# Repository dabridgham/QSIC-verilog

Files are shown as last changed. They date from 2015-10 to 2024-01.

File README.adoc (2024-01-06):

= QSIC - QBUS Storage and I/O Card

The QSIC is a QBUS card with an FPGA and SD cards that emulates the old DEC disk
controllers and drives.  A companion
http://github.com/dabridgham/Indicator-Panel[indicator panel] is also
available for those who want the blinkenlights.

This project has been split into separate repositories so that it
works better with git.  This repository primarily holds the Verilog
code that runs on the FPGAs.  It also holds the documentation and the
paper I wrote on bus arbitration.  Finally, just because there's no
more work being done on it, I've left the KiCad schematic for the
wire-wrapped prototype here as well.

So, directories you might care about are:

[horizontal]
board-wirewrap:: KiCad design for the wire-wrap prototype board
documentation:: Programming Manual for the QSIC/USIC
papers:: A paper on QBUS and Unibus arbitration
verilog:: The FPGA code to implement the QSIC

These directories, I'll probably make go away at some point but, for
now, I'll leave them be.

[horizontal]
board-prototype:: KiCad design for a prototype board with 8641 bus
		  transceivers (old idea)
board-qsic:: KiCad design for the QSIC hardware
board-smt:: KiCad design where I've been experimenting with discrete bus drivers
indicator-panel:: This directory is obsolete as the indicator panel has
		  been moved to its own project

Other QSIC-related repositories.

[horizontal]
https://github.com/dabridgham/QSIC[QSIC]:: The QSIC board
https://github.com/dabridgham/USIC[USIC]:: The USIC board
http://github.com/dabridgham/Indicator-Panel[Indicator Panel]:: Indicator Panel PCBs and graphics inlays
Software:: The software that runs on the embedded soft processor in
the QSIC/USIC (not yet started)

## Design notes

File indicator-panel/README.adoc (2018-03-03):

= Indicator Panel

This is an attempt to replicate the functionality of DEC's indicator
panels used on PDP-11s and some other machines.  It was designed in
conjunction with the QSIC project to build a QBUS board to emulate the
old DEC disk drives using more modern storage technology and we wanted
to have blinkenlights to go with.

indicator-panel*::
   KiCad design for the indicator panel boards themselves.  Three
   boards make a full indicator panel.

adapter*:: A small adapter board to convert from the version 1 pinout
   to version 2.

inlay*:: Various inlay designs we've come up with to use with the
   QSIC.

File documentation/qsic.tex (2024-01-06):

% -*- mode: LaTeX; fill-column: 96 -*-
%
% QSIC/USIC Programming and Configuration

\chapter[QBUS/UNIBUS Storage and I/O Card]{QBUS/UNIBUS Storage and Input/Output Card}
\section{Introduction}

The QSIC and USIC are cards which provide emulation of various QBUS and
UNIBUS controllers and disks, using MicroSD cards or (eventually) USB disks
as the actual storage media. They use NOS original bus drivers (DS8641s),
and then level converters to interface to a modern FPGA.

Eventually, they are likely be extended to allow emulation of other
controllers, e.g. the Interlan NI1010 and NI2010 Ethernet, via devices
plugged into the USB port.

They currently implement upwardly compatible, but extended, versions of the
old DEC RK11 and RP11 disk controllers. Although the emulation is not exact,
it is good enough that un-modified operating system images (UNIX V6) are able
to boot and run.

The emulation limitations are in part because many of the control register
bits only make sense with an actual physical drive; also, exact emulation,
including delays (e.g. for now non-existent seeks) would limit the
performance obtainable. (It is possible some systems that will not work
without better emulation of such delays; if so, an option could be added to
better emulate them.)

The QSIC is a dual-height QBUS card; it can hold two microSD cards,
allowing direct card-\textgreater card backup. The controllers are
denominated as the RKV11-F and RPV11-D; the extension is allowing DMA
to the entire $2^{22}$ byte QBUS address space.

The USIC is the same functionality in a quad-height SPC card for the UNIBUS.
The USIC will optionally adds the Able ENABLE functionality, which allows
processors with only 18-bit addressing to have access to $2^{22}$ bytes of
memory.

When this is enabled, the RK11-F and RP11-D (as they are denominated here)
can be set to be `MASSBUS' controllers (notionally), with full direct access
to the entire memory (which is on the USIC), without going through a UNIBUS
Map. With that turned off, they emulate the originals; i.e. they do DMA
cycles on the UNIBUS.

Both cards have provision for adding indicator panels, as close as possible
to the DEC originals, to display internal state and datal; this will help
invoke the feel of the older machines. They might even be useful for
debugging from time to time!

\section{Basic operation}

The space on the microSD cards (`storage devices') is divided into `packs',
described by a `pack table' on the card (because it applies only to that
card), which gives their location and size. Packs can be `loaded' on
`drives'; in other words, everything works much like the original hardware.

(The term `mount' is reserved for the operation of letting the operating
system add a pack to the visible file system -- again, like the existing UNIX,
etc, terminology.)

There are also `load tables', which record which packs are loaded on which
drives; a non-volatile instance of these allows a system to be cold-booted
without going through a pack loading phase.

A storage device is `inserted' into a microSD slot; removing one without
previously un-mounting (and un-loading) the packs is an error which can
damage storage contents, just as switching a physical pack without
un-mounting it would have on the original hardware.

Removing a storage device will auto-unload any packs still loaded. Before any
further disk operations can happen, any packs on a new storage device which
are to be used have to be loaded; attempting to use them without that step
will produce `disk not loaded' faults (e.g. clears `Drive Ready' on the RK11).

Each controller supports the maximum 8 drives of the original. It will be
possible to configure more than one instance of each controller, should
simultaneous access to more packs/drives be needed.

\section{Configuration}
\label{conf}

The QSIC and USIC contain, potentially, a multitude of devices all of
which need configuration.  If we did it in the traditional manner with
jumpers and DIP switches, the boards would be a mess of DIP switches
and difficult to change as we update the FPGA load.  Therefore,
configuration of these devices is handled through two I/O registers
which give access to a series of internal configuration registers
inside each of the emulated devices.

This configuration may be saved to internal flash memory where it will
be restored at startup.  Some configuration information is more
dynamic, such as the disk pack load tables, and needs to be
re-computed at each boot.\footnote{Still to be designed.}

\subsection{Bus Registers}

Access to the internal configuration registers is through two I/O
registers on the UNIBUS or QBUS located at $777720_8$ and $777722_8$.
The first register is the address register.  Setting this selects
which internal configuration register the second register accesses.
Reading or writing the second bus register then accesses the specified
configuration register.

\subsection{Top-Level Configuration Table}

The internal configuration begins at fixed location 0.  It gives some
information about the USIC or QSIC and then indexes all of the rest of
the configuration for the rest of the devices.

\begin{register16}
  \bits{14}{15}{Type}
  \bit{13}{FPGA Dev}
  \bit{12}{Soft Dev}
  \bit{11}{Save}
  \bits{4}{10}{---}
  \bits{0}{3}{Conf Vers}
\end{register16}
\regaddr{0}

\begin{bittable}
  0-3 & Conf Vers & Version of the configuration format.  This
  document describes version 0. \\

  11 & Save & Set this bit to cause the current configuration to be
  saved to flash memory.  While saving, this bit will read as 1.
  Do not modify the configuration while saving is in progress. \\

  12 & Soft Dev & The Software version shown is under development.  This
  bit will be cleared when it is a released version. \\

  13 & FPGA Dev & The FPGA version shown is under development.  This
  bit will be cleared when it is a released version. \\

  14-15 & Type & Type of board.\newline
  {\tt
    \begin{tabular}{rl}
      USIC & 00 \\
      QSIC & 01 \\
  \end{tabular}} \\
\end{bittable}

\begin{register16}
  \bits{8}{15}{FPGA Major Version}
  \bits{0}{7}{FPGA Minor Version}
\end{register16}
\regaddr{1}

\begin{register16}
  \bits{8}{15}{Software Major Version}
  \bits{0}{7}{Software Minor Version}
\end{register16}
\regaddr{2}

\begin{register16}
  \bits{8}{15}{Controller Count}
  \bits{0}{7}{Storage Device Count}
\end{register16}
\regaddr{3}

\begin{bittable}
  0-7 & Storage Device Count & A count of how many entries are in the
  storage devices table that follows the controller table. \\

  8-15 & Controller Count & A count of how many entries are in the
  controller table that follows. \\
\end{bittable}

Beginning at word 4, there is a table of Controllers followed by a
table of Storage Devices.  Each entry in the tables is one word long.

\begin{register16}
  \bits{11}{15}{Type}
  \bits{0}{10}{Index}
\end{register16}

\begin{bittable}
  0-10 & Index & The start address of the configuration block for the
  specified device. \\

  11-15 & Type & The type of device referenced.  For controllers,
  types are:\newline
  {\tt
    \begin{tabular}{ll}
      Indicator Panels & 0 \\
      RK11-F & 1 \\
      RP11-D & 2 \\
      Enable+ & 3 \\
      Interlan 1010 & 4 \\
  \end{tabular}}\newline
  
  For Storage Devices:\newline
  {\tt
    \begin{tabular}{ll}
      SD Card & 0 \\
      RAM Disk & 1 \\
      USB & 2 \\
  \end{tabular}}\\
\end{bittable}

\subsection{Storage Devices}

The storage devices have no configuration but they show up in the
configuration system as a way of reporting status and diagnostics.

\subsubsection{SD Card}

\begin{register16}
  \bit{15}{CD}
  \bit{14}{V2}
  \bit{13}{HC}
  \bit{12}{RDY}
  \bit{11}{RD}
  \bit{10}{WR}
  \bits{6}{9}{Error Code}
  \bits{0}{5}{Size}
\end{register16}

\begin{bittable}
  0-5 & Size & The $\log_2$ of the size of the SD Card in 512~byte
  blocks. \\
  6-9 & Error Code & If non-zero, the SD card controller is indicating an
  error.\footnote{Will fill out a table of error codes once they're
    set in the code.} \\
  10 & WR & The card is in the middle of a write operation. \\
  11 & RD & The card is in the middle of a read operation. \\
  12 & RDY & The device is ready. \\
  13 & HC & High Capacity \\
  14 & V2 & SD Version 2 \\
  15 & CD & Card Detect \\
\end{bittable}

\subsubsection{RAM Disk}

\begin{register16}
  \bits{6}{15}{---}
  \bits{0}{5}{Memory Size}
\end{register16}

\begin{bittable}
  0-5 & Size & The $\log_2$ of the size of memory in 512~byte blocks.\footnote{Current value is
    19.  256~MiBytes = $2^{28}$~Bytes = $2^{19}$~blocks.}  Zero (0) indicates there is no RAM
  available.\footnote{Wait, if there's no RAM then would we even have an entry for the
    memory?}
\end{bittable}

\subsubsection{USB Device}

This is mostly a placeholder for now, since we have not even begun to implement USB devices.
I'm expecting to have some small, fixed number of USB devices in the FPGA that get mapped to
actual USB storage devices as they're plugged in.

\begin{register16}
  \bit{15}{ACT}
  \bits{10}{14}{---}
  \bits{6}{9}{Error Code}
  \bits{0}{5}{Size}
\end{register16}

\begin{bittable}
  0-5 & Size & The $\log_2$ of the size of the USB device in 512~byte
  blocks. \\
  6-9 & Error Code & If non-zero, the USB Controller is indicating an
  error. \\
  15 & ACT & This USB device is active. \\
\end{bittable}

\subsubsection{Load Tables}
\label{storagedevice}

The load tables in each disk controller need to specify the storage device on which a disk pack
resides.  These are the values that are used.  Note that the SD Cards are physical locations
(there are two SD card slots, SD 0 and SD 1) while the different USB devices are logical (the
QSIC/USIC only has a single USB port but that may connect to a USB hub and there is no
particular mapping from physical USB port to the USB device number here).

{\tt
  \begin{tabular}{rl}
    SD Card 0 & 0 \\
    SD Card 1 & 1 \\
    RAM Disk & 2 \\
    USB 0 & 3 \\
    USB 1 & 4 \\
    USB 2 & 5 \\
    USB 3 & 6 \\
    USB 4 & 7 \\
\end{tabular}} \\

\section{RAM disks}

In addition to storing pack images on removable media, the QSIC/USIC also
supports `RAM drives' -- packs which are kept in on-board RAM on the card. The
contents do not survive power cycles, but RAM drives are desirable for uses
which do a lot of writing, none of which needs to survive a system re-boot,
e.g. swapping and paging.

The reason is that microSD cards (unlike the original magnetic media) cannot
perform un-limited write cycles; they wear out after a finite number of
writes. So, if there is no need to keep writes over re-boots (e.g. swapping
or paging data), those operations should be assigned to a RAM disk for
long-term use. On most operating systems, it is fairly easy to configure them
to do swapping/paging to particular devices.

\subsection{microSD card selection}

There have been reports of cheap commodity microSD cards failing after relatively
small numbers of writes. So, these should be avoided; also, backups of the
data on microSD cards should be kept fairly meticulously. There are ``industrial
grade'' microSD cards available, which are more robust than good consumer-grade
cards, so those are perhaps worth using.

\subsection{UNIX pipes}

The UNIX pipe device can also generate lots of ``temporary'' writes.
Unfortunately, on the early versions of UNIX, pipes are created on the root
device~-- probably the last place you want them, if there are microSD card issues!

This is simple to fix, though; in pipe(), in pipe.c, change the line:

	ip = ialloc(rootdev);

to

	ip = ialloc(pipedev);

and then go into c.c and add a line underneath the declaration of ``rootdev''
to add a ``pipedev''.

Don't forget that you will need to create a file system on any RAM pack you
are using to hold pipes, before you can use a pipe, though! Probably the
safest thing is to start the system with pipedev set to the root device, and
then reset pipedev once the pipe pack has a filesystem on it. (This is quite
OK, because once a pipe is created, it stays on the device it was created on,
and it's possible to have open pipes on more than one device.) A program to
set `pipedev' is available for V6.

\section{Upgrading drivers}

The devices on QSIC, and USIC with Enable+ on, can do DMA to all 22 bits of
address space, but are program compatible for 18 bits (i.e. existing software
will run, but can only use the low $2^{18}$ bytes of memory). To use more
than $2^{18}$ bytes -- generally only needed to use the QSIC/USIC devices for
swapping/paging -- the device driver will have to be fixed -- not too
complicated, but only if one has the capability!

The 18-bit program compatability is, however, useful for extending operating
systems to use the 22-bit capability. (For systems like UNIX, which restrict
block device I/O to buffers in the low $2^{16}$ bytes of memory, the
22-bit capability is not needed if they are not being used for swapping/paging.)
Just simply boot the OS with only $2^{18}$ bytes of memory; modify the device
driver to be able to use the 22-bit addressing capability; and restart. (This
technique was used to give Unix V6 access to the 22-bit capability.)

NOTE: On OSs that auto-size memory, if you boot the system with more than
256KB of memory, if it tries to swap to high memory with the existing 18-bit
driver, either i) the system will crash if it knows that RK11's and/or RP11's
are 18-bit only (well, technically, RKV11-D's are actually only 16 bits), or
ii) the transfer will go someplace else in memory from where the OS thought
it was going to go. (E.g. UNIX V6 would do this -- although the address in the
I/O request is 22 bits long, the existing RK11/RP11 drivers only look at the
low 18.) The solution is to boot the system with only 256KB of memory
installed; then update the driver to be able to do 22 bit DMA; then the rest
of the memory can be added back.

\chapter{Indicator Panels}

The QSIC and USIC support indicator panels which look exactly like the old
DEC ones. These comprise (like the originals) a bezel, a captioned inlay, a
light shield, and a PCB holding the lamps (``warm white'' LEDs, which look
identical to the original units, when seen through the inlay); the whole
mounts to a $19''$ rack.

As on the originals, the bezel and inlay go on the standard ``latch moldings''
(the flat plastic units with the two posts with a spherical ball on the top)
mounted to the rack; the light shield (``Benelex'' in DEC parts jargon) mounts
to the rack with a pair of brackets, and the lamp PCB mounts to that.

Although the new panels are mechanically compatible with the originals (so
that original bezels, inlays, etc can be used, and vice versa), the hardware
interface to the lamp PCB is totally different (bit-serial via a 4-wire
interface -- data, clock, latch and ground), rather than `wire per bulb', as
in the originals. As a result, the PCBs are also completely different. The
new PCBs are limited in size (for ease of fabrication); each only holds 12
columns of lamps, and a set of 3 plug together to make the full 36-wide array
of the originals.

The maximum number of panels a single QSIC/USIC can support is not yet
determined, but should be at least 4.

We can supply complete units (mostly newly-fabricated), but we have only a
limited supply of original bezels.

\section{Configuration}

The configuration registers allow the user to set how many indicator
panels are attached and what should be displayed on them.

All the indicator panels are driven by a single, differential serial
line running at approximately 100~kHz.  This serial line is
daisy-chained from one panel to the next.  The more indicator panels
you configure, the slower their update.  The current configuration
allows for up to seven but that maximum has not yet been tested.

\begin{register16}
  \bits{12}{15}{Count}
  \bits{8}{11}{Panel 1}
  \bits{4}{7}{Panel 2}
  \bits{0}{3}{Panel 3}
\end{register16}
\regaddr{Start+0}

\begin{register16}
  \bits{12}{15}{Panel 4}
  \bits{8}{11}{Panel 5}
  \bits{4}{7}{Panel 6}
  \bits{0}{3}{Panel 7}
\end{register16}
\regaddr{Start+1}

\begin{bittable}
  & Count & How many panels are active.\\

  & Panel N & The type of each panel.  That is, what to display.
  Panel 1 is first in the chain (that is, closest to the QSIC or USIC). \newline
  {\tt \begin{tabular}{rll}
      lamptest & 0 & All lights on \\
      Bus Monitor & 1 & Unibus or QBUS\footnote{Also includes some SD Card and USB
      status lights.} \\
      RK11 \#0 & 2 \\
      RK11 \#1 & 3 \\
      RP11 \#0 & 4 \\
      RP11 \#1 & 5 \\
      Enable+ & 6 \\
      Interlan & 7\footnote{Do we even want a full indicator panel for
        the Interlan Ethernet board?  Maybe just grab two or three
        lights off the bus monitor display.} \\
      debugging & 15 \\
  \end{tabular}} \\
\end{bittable}

\section{Inlays}

Although we could do exact duplicates of original panels, the old DEC panels
have lots of lights that don't make sense without an actual physical disk
(e.g. `write current on'), and also leave off other ones that would be useful
(e.g. memory address). So, we default to a new layout we have designed, which
makes the best use of the available set of lamps.

The new layout works with both the RK11 and RP11; the RK11 does not drive all
the disk address lights, but is otherwise identical.

We might be able to provide exact copies of the old ones for people who are
crazy for authenticity; it will require custom FPGA loads to drive their
lamps correctly, though.

In addition to the RK/RP inlays, there is also an inlay to monitor QBUS
activity.

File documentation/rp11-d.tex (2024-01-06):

% -*- mode: LaTeX; fill-column: 96 -*-
%
% RP11-D Programming Manual for the QSIC/USIC

\chapter{RP11-D}

The RP11-D is the implementation of the RP11 disk controller inside the QSIC
and USIC. The RP11 never existed on the QBUS at all, but it is being
supported there because it's a nice simple controller, and can be very simply
extended to provide very large disks.

The RP11-D has been extended to support 22-bit addressing, both on the QSIC
(for the 22-bit QBUS), and on the USIC (where it's notionally a MASSBUS
device), to be able to have access to the $2^{22}$ bytes of main memory
supported by the ENABLE+ functionality available on the USIC.

The extended address needs more bits alongside the existing Bus Address
Register; these are stored in a new register, the 'Extended Address Register'
(RPXA). To find a place for this, the RP11-D takes advantage of the fact that
the original RP11-C hardware actually responds from $776700_8$ up to
$776736_8$, but there are no actual registers from $776700_8$ to
$776706_8$, so we can put any additional registers needed in that range.

We've also extended it further to allow for much larger disks. This is done by the
simple expedient of extending the track and cylinder fields into all the adjacent
unused bits, and allowing the sector, head, and cylinder fields of the disk address
to take on any value that fits. (These bits are not enabled unless the RP11-D is
configured for extended packs.) The result is 28~bits of linear block address, or a
maximum disk size of $2^{37}$ bytes or 128~GiBytes.  Obviously you'll need the
ability to modify your disk driver to take advantage of this.  Another added register
allows the device driver to see the configured pack size of each disk pack.

\section{Configuration}

The RP11-D has a set of configuration registers that take the place of the jumpers
and DIP switches of earlier disk controllers.  Additionally, there are configuration
registers that make up a ``load table'' that maps logical disk drives to disk packs
located on the various storage media.

This block of registers is referenced from the top-level configuration block as
described in \S\ref{conf}, page \pageref{conf}.  In this way, multiple RP11-Ds can
each have its own set of configuration registers and they can move around in the
configuration address space without needing to redefine anything here.  Addresses
shown here are relative to the beginning of this block of RP11-D configuration.

\subsection{Device}

\regaddr{Start+0}

\begin{register16}
  \bit{15}{ENA}
  \bit{14}{Q22}
  \bit{13}{EXT}
  \bits{0}{12}{Base Address}
\end{register16}

\begin{bittable}
  00-12 & Base Address & The base address of the RP11-D's registers in the I/O page
  on the QBUS or Unibus.  The default for the first RP11 is $776700_8$.\\

  13 & Extended & Enables extended disk packs.  This breaks compatibility with
  previous RP11s but allows for much larger disks if you're able to modify your disk
  driver. \\

  14 & Q22 & Enables 22-bit operation, otherwise the RP11-D acts as an 18-bit device.
  On the QBUS, Q22 would be normal while on the Unibus, 18-bits would be normal.
  
  Selecting Q22 on the Unibus while the Enable+ is also enabled, directs the RP11-D
  to DMA directly to 22-bit memory with physical addresses, not going through the
  Enable+ Unibus mapping registers.  An ersatz MASSBUS disk, if you will.  Enabling
  22-bit addressing on the Unibus without the Enable+ is currently undefined. \\

  15 & Enable & Enables this RP11-D. \\
\end{bittable}

\regaddr{Start+1}

\begin{register16}
  \bits{11}{15}{---}
  \bits{9}{10}{INT PRI}
  \bits{0}{8}{Interrupt Vector}
\end{register16}

\begin{bittable}
  00-08 & Interrupt Vector & The interrupt vector to use.  The default for the first
  RP11 is $254_8$. \\

  09-10 & INT PRI & The interrupt priority.  The default is interrupt priority
  5. \newline {\tt
    \begin{tabular}{ll}
      Priority 4 & 00 \\
      Priority 5 & 01 \\
      Priority 6 & 10 \\
      Priority 7 & 11 \\
  \end{tabular}} \\
\end{bittable}

\subsection{Load Table}

The Load Table immediately follows the device configuration and tells the RP11-D
about simulated ``disk packs'' that are loaded into its ``drives''.  It has eight
entries, corresponding to the eight disk drives the disk controller supports.  Each
entry is four consecutive configuration words.

\regaddr{Start+2,6,10,14,18,22,26,30}

\begin{register16}
  \bit{15}{ENA}
  \bit{14}{EXT}
  \bit{13}{RP03}
  \bits{3}{12}{---}
  \bits{0}{2}{SD}
\end{register16}
\begin{register16}
  \bits{0}{15}{Offset Low}
\end{register16}
\begin{register16}
  \bits{0}{15}{Offset High}
\end{register16}
\begin{register16}
  \bits{0}{15}{Size}
\end{register16}

\begin{bittable}
  00-02 & SD & The Storage Device the pack lives on.  See the table at
  \S\ref{storagedevice}, page \pageref{storagedevice}. \\

  13 & RP03 & If this is not an extended disk pack, this specifies an RP03 disk (406
  cylinders, \verb|~|40MB) otherwise an RP02 disk (203 cylinders, \verb|~|20MB). \\

  14 & EXT & This is an extended disk pack.  Only allowed if the RP11-D is configured
  to allow extended packs.\footnote{Considering using the File Unsafe error (RPDS bit
    09) to indicate that an extended pack was configured on a non-extended RP11-D.} \\

  15 & ENA & This pack is enabled.  Whether the pack shows as loaded depends on both
  this bit and whether the associated storage device is active. \\

   & Offset & The offset, in blocks, of the pack from the beginning of its Storage
  Device. \\

   & Size & For extended disk packs, this is the largest cylinder number (one less than the
  number of cylinders).  It is set to 0 for legacy RP02 or RP03 disk packs, allowing for a
  mix of legacy and extended disk packs on the same RP11-D controller. \\
\end{bittable}

On extended disk packs, the RP11-D has 4~bits to specify the sector address and
8~bits for the track.  All values are used (16 sectors per track and 256~tracks per
cylinder) so there are $2^{12}$ or 4,096~sectors per cylinder.

The smallest disk supported is 4~MiB with 2 cylinders (since a size of 0, 1 cylinder,
specifies a legacy disk pack) while the largest is 65,536~cylinders or 128~GiB.

\section{Programming}

The RP11-D is substantially compatible with the RP11-C, with extensions for
extended addressing, the optional extended disk addresses, and again, some
different meanings to error bits to better match the flash media the
QSIC/USIC uses for storage devices.

Initiate functions (Idle, Seek and Home Seek) only require short periods;
execute functions (the rest) tie up the controller until it is finished
with the operation. No other operation (initiate or execute) can be
started until the execute function has completed. Plain Read and Write
include an implicit seek, if needed; the Seek command allows specifying
the desired head (track) as well.

After reading or writing the last sector in a track, the RP11-D automatically
advances to the next track; if the track that overflowed was the last track
in the cylinder, the cylinder automatically advances to the next cylinder. If
the cylinder that overflowed was the last cylinder, End of Pack in the RPER
is set.

Neither the 36-bit mode, nor header commands (i.e. Header bit in the RPCS
set), nor either parity, is supported.

The default interrupt vector is $254_8$ and the interrupt priority 
is 5. Both the interrupt priority and vector are configurable.

\section{Registers}

The address shown for each register is the default address for the
first RP11 controller.

\subsection{Pack Size Register (RPPS)}
\regaddr{776704}

\bigskip
If the larger pack size is not enabled, this register reads as 0, and writing
has no effect, like on the RP11-C.

If it is enabled, this register give the size of the pack currently mounted
on the drive selected by the 'Drive Select' field of the RPCS.  If a
regular RP02 or RP03 pack is loaded on a drive, the pack size will
show as 0 and the disk addressing for that disk will be the regular
cylinder/track/sector rather than a linear block address.

\begin{register16}
  \bits{0}{15}{Pack Size}
\end{register16}

\begin{bittable}
  00-15 & Pack Size (PS) & Contains the largest valid cylinder number of
  the drive selected by the 'Drive Select' field of the RPCS; read-only. \\
\end{bittable}

\subsection{Extended Address Register (RPXA)}
\regaddr{776706}

\bigskip
If addressing is set to 18-bits, this register reads as 0 and writing has no
effect, like on the RP11-C.

If addressing is set to 22-bits, this register extends the Bus
Address register to a full 22-bits.  On the UNIBUS, this only makes
sense in the presence of the ENABLE+ and the address is then a
physical address rather than being mapped by the ENABLE+. On the QBUS
it's always a physical address anyway.

\begin{register16}
  \bits{0}{5}{BAE}
  \bits{6}{15}{0}
\end{register16}

\begin{bittable}
  00-05 & Bus Address Extension (BAE) & If 22-bit addressing is
  enabled, these bits extend the Bus Address Register to 22-bits.
  Bits 00 and 01 are duplicates of MEX (bits 04 and 05 of RPCS) and
  may be read or written through either register. \\
\end{bittable}

\subsection{Drive Status Register (RPDS)}
\regaddr{776710}

\begin{register16}
  \bit{0}{ATTN 0}
  \bit{1}{ATTN 1}
  \bit{2}{ATTN 2}
  \bit{3}{ATTN 3}
  \bit{4}{ATTN 4}
  \bit{5}{ATTN 5}
  \bit{6}{ATTN 6}
  \bit{7}{ATTN 7}
  \bit{8}{SU WP}
  \bit{9}{SU FU}
  \bit{10}{SU SU}
  \bit{11}{SU SI}
  \bit{12}{HNF}
  \bit{13}{SU RP03}
  \bit{14}{SU OL}
  \bit{15}{SU RDY}
\end{register16}

The Attention bits are read-write (and may be written by a 'write byte' bus
cycle), the rest are read-only.

\begin{bittable}
  00-07 & Drive Attention & Set when the drive completes a seek.\\
  
  08 & Selected Unit Write Protected & Set when the selected drive is in
  write-protected mode. \\

  09 & Selected Unit File Unsafe & Unused, set to 0.\footnote{Could be used to
    indicate storage device initialization failure, perhaps.} \\

  10 & Selected Unit Seek Underway & Unused, set to 0.\footnote{May depend on
    what we do with seeks.} \\

  11 & Selected Unit Seek Incomplete & Set to 0; seeks always complete. \\

  12 & Header Not Found & Unused, set to 0. \\

  13 & Selected Unit RP03 & Set to 1 to indicate this is an RP03. \\

  14 & Selected Unit Online & Set to 1 when i) an SD card has been installed;
    ii) it has successfully completed initialization; iii) a pack partition
    on that card has been assigned to this drive. \\

  15 & Selected Unit Ready & Set to 1 as with SU OL, except during a read or
	write operation to this disk, when is it 0. \\
\end{bittable}

\subsection{Error Register (RPER)}
\regaddr{776712}

% Argh!! Why the inverse numbering from the previous?
\begin{register16}
  \bit{15}{WPV}
  \bit{14}{FUV}
  \bit{13}{NXC}
  \bit{12}{NXT}
  \bit{11}{NXS}
  \bit{10}{\tiny PROG}
  \bit{9}{\tiny FMTE}
  \bit{8}{\tiny MODE}
  \bit{7}{LPE}
  \bit{6}{WPE}
  \bit{5}{\tiny CSME}
  \bit{4}{\tiny TIMEE}
  \bit{3}{WCE}
  \bit{2}{\tiny NXME}
  \bit{1}{EOP}
  \bit{0}{\tiny DSK ERR }
\end{register16}

The RPER is a read-only register (except in maintenance mode, which
is not currently supported).

\begin{bittable}
  00 & Disk Error & OR of HNF and SU SI, so always 0. \\

  01 & End of Pack & Indicates that, during a Read, Write, Read Check,
    or Write Check function, operations on sector $11_8$, track $23_8$,
    and cylinder $625_8$ were finished, and the RPWC has not yet overflowed.
    This is essentially an attempt to overflow out of a drive. \\

  02 & Nonexistent Memory & Set if memory does not respond
  within the bus timeout on a memory cycle. \\

  03 & Write Check Error & Indicates that the data comparison
    didn't match during a Write Check function.\footnote{Not yet
    implemented.} \\

  04 & Timing Error & Unused, set to 0. \\

  05 & Checksum Error & Indicates a checksum error while reading
  data during a Read Check or Read function. The RP11-D does not do
  its own checksums on the data and this bit reflects the checksum
  from the SD Card or USB checksum.\footnote{Not yet implemented.} \\

  06 & Word Parity Error & Unused, set to 0. \\

  07 & Longitudinal Parity Error & Unused, set to 0. \\

  08 & Mode Error & Unused, set to 0. \\

  09 & Format Error & Unused, set to 0. \\

  10 & Programming Error & OR of transfer attempted with the RPWC
    set to 0; an operation was attempted on a drive which was not online;
    an operation was attempted while another was still in progress. \\

  11 & Non-existent Sector & Indicates that an attempt was made
  to initiate an operation to a sector larger than $11_8$. \\

  12 & Non-existent Track & Indicates that an attempt was made
  to initiate an operation to a track larger than $23_8$. \\

  13 & Non-existent Cylinder & Indicates that an attempt was made
  to initiate a transfer to a cylinder larger than $625_8$. \\

  14 & File Unsafe Violation & Unused, set to 0. \\

  15 & Write Protect Violation & Set if an attempt is made to
    write to a disk that is currently write-protected.\footnote{Not
    yet implemented.} \\
\end{bittable}

\subsection{Control Status Register (RPCS)}
\regaddr{776714}

\begin{register16}
  \bit{15}{ERR}
  \bit{14}{HE}
  \bit{13}{AIE}
  \bit{12}{\tiny MODE}
  \bit{11}{HDR}
  \bits{8}{10}{DRV SEL}
  \bit{7}{RDY}
  \bit{6}{IDE}
  \bits{4}{5}{MEX}
  \bits{1}{3}{COM}
  \bit{0}{GO}
\end{register16}

\begin{bittable}
  00 & Go & When set, causes the RP11-D to act on the function
    contained in bits 01 through 03 of the RPCS; when set, it
    sets Not Ready bit (which does not appear to be in any register;
    perhaps the Ready bit in the CSR is the inversion of that).
    Write-only, always reads as 0 (it is not stored; rather, the level during
    the bus write operation is used as a pulse). \\

  01-03 & Function & The function to be executed when Go is
  set.\newline
  {\tt
    \begin{tabular}{ll}
      Idle/Reset & 000 \\
      Write & 001 \\
      Read & 010 \\
      Write Check & 011 \\
      Seek & 100 \\
      Write (no seek) & 101 \\
      Home Seek & 110 \\
      Read (no seek) & 111 \\
  \end{tabular}} \\

  04-05 & Memory Extended Address & A 2-bit extension to RPBA giving
    an 18-bit bus address. If 22-bit addresses are enabled,
    these two bits are replicated as bits 00 and 01 of RPXA. \\

  06 & Interrupt on Done (Error) Enable & When set, causes an interrupt
    to be issued on various conditions.\footnote{Should audit the code
    and list all the conditions that can generate an interrupt.}\\

  07 & Ready & Controller is ready to perform a new function;
    read-only. \\

  08-10 & Drive Select & Specify the drive for any controller command. \\

  11 & Header & Not applicable to the QSIC/USIC.\footnote{Currently the
    Header bit is ignored but it probably should generate some sort of
    error.} \\

  12 & Mode & Not applicable to the QSIC/USIC.\footnote{Currently the
    Mode bit is ignored but it probably should generate some sort of
    error.} \\

  13 & Attention Interrupt Enable & Allows the RP11-D to generate an
    interrupt when any Attention bit (in RPDS) is set.\footnote{Not yet
    implemented.} \\

  14 & Hard Error & Set when any error other than a data error is set;
    read-only. \\

  15 & Error (ERR) & Set when any error is set; read-only. \\
\end{bittable}

\subsection{Word Count Register (RPWC)}
\regaddr{776716}

\begin{register16}
  \bits{0}{15}{Word Count}
\end{register16}

\begin{bittable}
  00-15 & Word Count & The 2's complement of the number of words to be
  transferred by a function.  The register increments by one after
  each word transfer.  When the register overflows to 0, the transfer
  is completed and the RP11 function is terminated. \\
\end{bittable}

\subsection{Bus Address Register (RPBA)}
\regaddr{776720}

\begin{register16}
  \bits{1}{15}{Bus Address}
  \bit{0}{0}
\end{register16}

\begin{bittable}
  00-15 & BA00-BA15 & The low 16-bits of the bus address to be used for data
  transfers.  The MEX bits (bits 04 and 05 of RPCS) extend the address to 18-bits
  and, if enabled, the BAE bits (bits 00-05 of RPXA) extend the address to
  22-bits. Bit 00 is always 0 as all transfers are a full word. \\
\end{bittable}

\subsection{Cylinder Address Register (RPCA)}
\regaddr{776722}

\begin{register16}
  \bits{0}{8}{Cylinder Address}
  \bits{9}{15}{Extended Cylinder Address}
\end{register16}

When in RP02/RP03 emulation mode, bits 0-8 are read-write, and 9-15 are
unused.

\begin{bittable}
  00-08 & Cylinder 00-08 & The cylinder number when emulating an
  RP02/03. \\

  09-15 & Extended Cylinder 09-15 & The high bits of the cylinder number,
  when emulating an extended pack. \\
\end{bittable}

\subsection{Disk Address Register (RPDA)}
\regaddr{776724}

\begin{register16}
  \bits{0}{3}{Sector Address}
  \bits{4}{7}{Current Sector}
  \bits{8}{12}{Track Address}
  \bits{13}{15}{Extended Track}
\end{register16}

Used for all operations other than Home Seek. Seek uses only the
Track Address.

\begin{bittable}
  00-03 & Sector Address & The disk sector to be addressed for
  the next function. \\

  04-07 & Current Sector & Notionally, the current sector address of the
	currently selected drive; read-only. On the RP11-D, connected to
	a free-running counter; the data is of no validity. \\

  08-12 & Track 00-04 & The track number, when emulating an RP02/03. \\

  13-15 & Extended Track 05-07 & The extended track number, when emulating
	an extended pack. \\
\end{bittable}

\subsection{Maintenance 1 Register (RPM1)}
\regaddr{776726}

\begin{register16}
  \bits{0}{15}{Unused}
\end{register16}

This register is currently unimplemented in the RP11-D.

\begin{bittable}
  00-15 & Unused & Unused \\
\end{bittable}

\subsection{Maintenance 2 Register (RPM2)}
\regaddr{776730}

This register is currently unimplemented in the RP11-D.

\begin{register16}
  \bits{0}{15}{Unused}
\end{register16}

\begin{bittable}
  00-15 & Unused & Unused \\
\end{bittable}

\subsection{Maintenance 3 Register (RPM3)}
\regaddr{776732}

This register is currently unimplemented in the RP11-D.

\begin{register16}
  \bits{0}{15}{Unused}
\end{register16}

\begin{bittable}
  00-15 & Unused & Unused \\
\end{bittable}

\subsection{Selected Unit Cylinder Address(SUCA)}
\regaddr{776734}

\begin{register16}
  \bits{0}{8}{Cylinder Address}
  \bits{9}{15}{Extended Cylinder Address}
\end{register16}

This register appears to be read-only. (Need to check the prints.)

\begin{bittable}
  00-08 & Cylinder 00-08 & Contains the cylinder address of the selected
    drive (I think!) when emulating an RP02/03. \\

  09-15 & Extended Cylinder 09-15 & Contains the extended cylinder address
    when emulating an extended pack. \\
\end{bittable}

\subsection{Silo Memory Buffer Register (SILO)}
\regaddr{776736}

\begin{register16}
  \bits{0}{15}{Silo end}
\end{register16}

\begin{bittable}
  00-15 & Silo & This register, when enabled by maintenance
  (currently un-implemented) allows reading from and writing to
  the FIFO connecting the RP11-D to its storage device. \\
\end{bittable}

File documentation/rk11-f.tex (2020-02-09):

% -*- LaTeX -*-
%
% RK11-F Programming Manual for the QSIC/USIC

\chapter{RK11-F}

The RK11-F is the implementation of the RK11 disk controller inside
the QSIC and USIC.  It is substantially compatible with the RK11-D
with extensions for extended addressing on the QBUS and some
reinterpretations of some of the error bits to better match the flash
media the QSIC/USIC uses for storage devices.

To provide 22-bit addressing, the RK11-F has recycled the maintenance
register from the RK11-C (which was unused in the RK11-D) to hold the
extra address bits.  On the Unibus, the RK11-F with extended
addressing is notionally a MASSBUS device, giving direct access to the
full $2^{22}$ byte physical address space supported by the ENABLE+
functionality.

On the QBUS, the RK11-F only has 22-bit mode though if you ignore the
extended address register it will act mostly like an 18-bit
device.\footnote{The exception has to do with the address register
  wrapping around at the end of the address space.  This shouldn't be
  an issue in practice as it would involve DMA operations into the I/O
  page which would almost certainly generate NXM errors.}

DEC did build an RKV11-D that was an RK11-D modified to work on the
QBUS.  For some reason, it only support 16-bit addresses even though
the RK11-D supported 18-bit addresses on the Unibus.  We think the
RK11-F, even though in 22-bit mode, ought to work with legacy software
but if this turns out to not be the case we'll return to this issue.

\section{Configuration}

By default, eight I/O registers begin at $777400_8$\footnote{Assuming
  we include two RK11s by default, I should add the default values for
  the second RK11 too.}.  The default interrupt vector is $220_8$ and
the interrupt priority is 4.  The USIC can be configured for 18-bit or
22-bit addresses.  The RK11-F as a whole may be disabled if it's not
wanted.

\section{Programming}

The address shown for each register is the default address for the
first RK11 controller.

\subsection{Drive Status Register (RKDS)}
\regaddr{777400}

\begin{register16}
  \bits{0}{3}{Sector Counter}
  \bit{4}{SC=\\SA}
  \bit{5}{WPS}
  \bit{6}{\tiny R/W/S\\RDY}
  \bit{7}{DRY}
  \bit{8}{SOK}
  \bit{9}{SIN}
  \bit{10}{DRU}
  \bit{11}{RK05}
  \bit{12}{DPL}
  \bits{13}{15}{Drive Ident}
\end{register16}

\begin{bittable}
  00-03 & Sector Counter (SC) & The current sector address of the
  selected drive. On the QSIC/USIC, this is just a free-running
  counter clocked at 312.5kHz ($3.2\mu s$).\footnote{Check me that
    this is about the right speed.}  All disks share a single Sector
  Counter. \\
  
  04 & Sector Counter Equals Sector Address (SC=SA) & Set when the
  Sector Counter is equal to the Sector Address (RKDA 03-00). \\

  05 & Write Protect Status (WPS) & Set when the selected disk is in
  the write-protected mode. \\

  06 & Read/Write/Seek Ready\newline (R/W/S RDY) & Indicates a storage
  device is loaded and ready to accept commands.  In the QSIC/USIC, a
  storage device may be serving multiple disks at once and so unable
  to accept commands right now because it's otherwise busy.  However,
  the disk controller can still accept a command and it will wait
  until the storage device is ready.\footnote{This is a description of
    what it does right now.  As I wrote this, I realized that another
    possible implementation, perhaps better, would for it to be the
    AND of DRY (Drive Ready) and RDY (Control Ready).} \\

  07 & Drive Ready (DRY) & A storage device is loaded for the selected
  disk. \\

  08 & Sector Counter OK (SOK) & Unused, set to 1. \\

  09 & Seek Incomplete (SIN) & Set to 0.  Seeks always complete. \\

  10 & Drive Unsafe (DRU) & Unused, set to 0.\footnote{Could be used to
    indicate storage device initialization failure, perhaps.} \\

  11 & RK05 & Set to 1 to indicate this is an RK05. \\

  12 & Drive Power Low (DPL) & Unused, set to 0. \\

  13-15 & Identification of Drive (ID) & Set to the drive number that
  caused an interrupt.\footnote{Currently I set this from state
    CMD\_DONE regardless of whether I generate an interrupt or not.
    Also, I should check that it sets ID for all commands that could
    generate an interrupt.} \\
\end{bittable}

\subsection{Error Register (RKER)}
\regaddr{777402}

\begin{register16}
  \bit{15}{DRE}
  \bit{14}{OVR}
  \bit{13}{WLO}
  \bit{12}{SKE}
  \bit{11}{PGE}
  \bit{10}{NXM}
  \bit{9}{DLT}
  \bit{8}{TE}
  \bit{7}{NXD}
  \bit{6}{NXC}
  \bit{5}{NXS}
  \bits{2}{4}{Unused}
  \bit{1}{CSE}
  \bit{0}{WCE}
\end{register16}

\begin{bittable}
  00 & Write Check Error (WCE) & Indicates that the data comparison
  didn't match during a Write Check function.\footnote{Not yet
    implemented.} \\

  01 & Checksum Error (CSE) & Indicates a checksum error while reading
  data during a Read Check or Read function.  The RK11-F does not do
  its own checksums on the data and this bit reflects the checksum
  from the SD Card or USB checksum.\footnote{Not yet implemented.} \\

  02-04 & Unused  \\

  05 & Nonexistent Sector (NXS) & Indicates that an attempt was made
  to initiate a transfer to a sector larger than $13_8$. \\

  06 & Nonexistent Cylinder (NXC) & Indicates that an attempt was made
  to initiate a transfer to a cylinder larger than $312_8$. \\

  07 & Nonexistent Disk (NXD) & Indicates that an attempt was made to
  initiate a function on a nonexistent drive.\footnote{Not yet
    implemented.} \\

  08 & Timing Error (TE) & Unused, set to 0. \\

  09 & Data Late (DLT) & Unused, set to 0. \\

  10 & Nonexistent Memory (NXM) & Set if memory does not respond
  within the but timeout on the memory cycle. \\

  11 & Programming Error (PGE) & Unused, set to 0. \\

  12 & Seek Error (SKE) & Unused, set to 0. \\

  13 & Write Lockout Violation (WLO) & Set if an attempt is made to
  write to a disk that is currently write-protected.\footnote{Not
    yet implemented.} \\

  14 & Overrun (OVR) & Indicates that, during a Read, Write, Read
  Check, or Write Check function, operations on sector $13_8$, surface
  1, and cylinder address $312_8$ were finished, and the RKWC has not
  yet overflowed.  This is essentially an attempt to overflow out of a
  disk drive. \\

  15 & Drive Error (DRE) & Unused, set to 0. \\
\end{bittable}

\subsection{Control Status Register (RKCS)}
\regaddr{777404}

\begin{register16}
  \bit{15}{ERR}
  \bit{14}{HE}
  \bit{13}{SCP}
  \bit{12}{---}
  \bit{11}{IBA}
  \bit{10}{FMT}
  \bit{9}{EXB}
  \bit{8}{SSE}
  \bit{7}{RDY}
  \bit{6}{IDE}
  \bits{4}{5}{MEX}
  \bits{1}{3}{FUNC}
  \bit{0}{GO}
\end{register16}

\begin{bittable}
  00 & GO & When set, causes the RK11-F to act on the function
  contained in bits 01 through 03 of the RKCS.\footnote{The RK11-D and
    RK11-E manual lists GO as write-only.  The RK11-F currently allows
    it to be read.  Oh wait, I know why they did that.  I need to fix
    the code.} \\

  01-03 & Function & The function to be executed when GO is
  set.\newline
  {\tt
    \begin{tabular}{ll}
      Control Reset & 000 \\
      Write & 001 \\
      Read & 010 \\
      Write Check & 011 \\
      Seek & 100 \\
      Read Check & 101 \\
      Drive Reset & 110 \\
      Write Lock & 111 \\
  \end{tabular}}  \\

  04-05 & Memory Extension (MEX) & A 2-bit extension to RKBA giving an
  18-bit bus address.  If 22-bit addresses are enabled (QSIC only),
  these two bits are replicated as bits 00 and 01 of RKXA. \\

  06 & Interrupt on Done Enable (IDE) & When set, causes an interrupt
  to be issued on various condition.\footnote{Should audit the code
    and list all the conditions that can generate an interrupt.}  The
  interrupt priority and vector are configurable. \\

  07 & Control Ready (RDY) & Control is ready to perform a function. \\

  08 & Stop on Soft Error & Currently not implemented. \\

  09 & Extra bit (EXB) & Unused. \\

  10 & Format (FMT) & Not applicable to the
  QSIC/USIC.\footnote{Currently the FMT bit is ignored but it probably
    should generate some sort of error.} \\

  11 & Inhibit Incrementing the RKBA (IBA) & Inhibits the RKBA from
  incrementing during a normal transfer.  This allows data transfers
  to occur to or from the same memory location throughout the entire
  transfer operation. \\

  12 & Unused \\

  13 & Search Complete (SCP) & Indicates that the previous interrupt
  was the result of some previous Seek or Drive Reset function.
  Cleared at the initiation of any new function.\footnote{Not yet
    implemented.} \\

  14 & Hard Error & Set when any of RKER 05-15 are set. \\

  15 & Error (ERR) & Set when any of RKER is set. \\
\end{bittable}

\subsection{Word Count Register (RKWC)}
\regaddr{777406}

\begin{register16}
  \bits{0}{15}{Word Count}
\end{register16}

\begin{bittable}
  00-15 & Word Count & The 2's complement of the number of words to be
  transferred by a function.  The register increments by one after
  each word transfer.  When the register overflows to 0, the transfer
  is completed and the RK11 function is terminated. \\
\end{bittable}

\subsection{Current Bus Address Register (RKBA)}
\regaddr{777410}

\begin{register16}
  \bits{1}{15}{Bus Address}
  \bit{0}{0}
\end{register16}

\begin{bittable}
  00-15 & BA00-BA15 & The low 16-bits of the bus address to be used
  for data transfers.  The MEX bits (bits 04 and 05 of RKCS) extend
  the address to 18-bits and, if enabled, the BAE bits (bits 00-05 of
  RKXA) extend the address to 22-bits (QSIC only).  Bit 00 is always 0
  as all transfers are a full word. \\
\end{bittable}

\subsection{Disk Address Register (RKDA)}
\regaddr{777412}

\begin{register16}
  \bits{0}{3}{Sector Address}
  \bit{4}{SUR}
  \bits{5}{12}{Cylinder Address}
  \bits{13}{15}{Drive Select}
\end{register16}

\begin{bittable}
  00-03 & Sector Address (SA) & The disk sector to be addressed for
  the next function. \\

  04 & Surface (SUR) & Upper or lower surface has no meaning for SD
  cards or USB flash drives so this maps to just another bit of
  cylinder addressing. \\

  05-12 & Cylinder Address\newline (CYL ADDR) & The cylinder address
  currently being selection.  The largest valid cylinder is
  $312_8$. \\

  13-15 & Drive Select (DR SEL) & The logical drive number currently
  being selected. \\
\end{bittable}

\subsection{Extended Address Register (RKXA)}
\regaddr{777414}

\bigskip
On the RK11-C this register was a maintenance register and on the
RK11-D it was unused.  If addressing is set to 18-bits, this register
reads as 0 and writing has no effect, like on the RK11-D.

If addressing is set to 22-bits, this register extends the Bus
Address register to a full 22-bits.  On the Unibus, this only makes
sense in the presence of the ENABLE+ and the address is then a
physical address rather than being mapped by the ENABLE+.  On the QBUS
it's always a physical address anyway.

\begin{register16}
  \bits{0}{5}{BAE}
  \bits{6}{15}{0}
\end{register16}

\begin{bittable}
  00-05 & Bus Address Extension (BAE) & If 22-bit addressing is
  enabled, these bits extend the Bus Address Register to 22-bits.
  Bits 00 and 01 are duplicates of MEX (bits 04 and 05 of RKCS) and
  may be read or written through either register. \\
\end{bittable}

\subsection{Data Buffer Register (RKDB)}
\regaddr{777416}

\begin{register16}
  \bits{0}{15}{Data Buffer}
\end{register16}

\begin{bittable}
  00-15 & Data Buffer (DB00-DB15) & This register reads from the read
  end of the FIFO connecting the RK11-F to its storage device.
  Writing to the Data Buffer has no effect. \\
\end{bittable}

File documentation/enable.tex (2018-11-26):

% -*- LaTeX -*-
%
% Enable+ Programming Manual for the QSIC/USIC

\chapter{Enable+}

The Enable+ is an implementation of the Able ENABLE board inside the
USIC.  The ENABLE board gave access to $2^{22}$ bytes of main memory
much like the PDP-11/70 for processors that only had 18 bits of
addressing.

The Able ENABLE board worked by having three bus connections, one
UNIBUS coming in, one UNIBUS out, and a memory bus.  The USIC
simplifies this by having all memory on-board and doesn't actually
need a UNIBUS out.

There are two maps in the Enable+, one for accesses from the processor
and the other used when devices are doing DMA operations.

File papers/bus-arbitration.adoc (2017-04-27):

= On Bus Arbitration on the Unibus and QBUS
David Bridgham <dab@froghouse.org>
April 2017

== Introduction

While working on implementing a QBUS device on an FPGA we reached a point of writing the
Verilog code for the bus arbitration.  In one particular place in the code we could see,
plain as day, that there was a race condition.  This triggered a vague memory from years
ago of being told about how there was a design flaw in the Unibus that could, on rare
occasion, lead to a bus-arbitration failure, and that this was discovered and fixed in the
QBUS design.

So here was the problem we had heard about all those years ago, clear in the Verilog code,
and that lead to an effort to understand the problem and find a workable solution.  This
paper is our attempt to document the results for the benefit of anyone who follows.  As
far as we know, this knowledge was passed word-of-mouth within the DEC community and has
not been written down until now.

== Bus Arbitration

We assume the reader has some knowledge of the Unibus and QBUS but may not know in detail
how bus arbitration works on these two buses.  For those details, refer to DEC's
http://www.bitsavers.org/pdf/dec/pdp11/handbooks/PDP11_BusHandbook1979.pdf[PDP-11 Bus
Handbook].
footnote:[http://www.bitsavers.org/pdf/dec/pdp11/handbooks/PDP11_BusHandbook1979.pdf]
It covers both the Unibus and QBUS and we will refer to timing diagrams by
page number in that reference.

For anyone actually working with these buses, it's worth your time to refer to multiple
sources for the bus description.  DEC's specs are pretty good but they learned things over
time and occasionally had editing errors.  Another take on the Unibus is found in
http://www.bitsavers.org/pdf/dec/unibus/UnibusSpec1979.pdf[PDP-11 Unibus Design
Description]
footnote:[http://www.bitsavers.org/pdf/dec/unibus/UnibusSpec1979.pdf]
and a later description of the QBUS (which has some details about block mode
transfers that I haven't seen elsewhere) is found in Appendix F of the
http://www.bitsavers.org/pdf/dec/vax/680/EK-KA680-TM-001_KA680_TechMan.pdf[KA680 CPU
Module Technical Manual].
footnote:[http://www.bitsavers.org/pdf/dec/vax/680/EK-KA680-TM-001_KA680_TechMan.pdf]

=== General Description

A computer bus connects a processor (sometimes multiple processors) and peripheral devices
together and allows data transfers between the various components.  As a general rule, one
and only one device may be in control of the bus at any time.  Usually this would be the
processor, reading and writing to memory and I/O devices as it executes instructions, but
from time to time it is useful to hand off this bus-master role to other devices in the
system, either so they can access memory directly (DMA) or so they can interrupt the
processor and give it an interrupt vector.

The mechanism whereby the processor hands over control of the bus to exactly one device is
called bus arbitration.  Computer designers have invented a variety of means of doing this
arbitration but a generic description of how DEC does it on the Unibus and QBUS follows.

A device requesting the bus asserts a common open-collector signal (wired OR) to the
processor.  When the processor sees this and is ready, the bus arbitration circuitry in
the processor asserts a bus grant line that is daisy-chained down the bus (i.e. wired from
an 'out' pin on one slot to an 'in' pin on the next sequential slot, for every pair of
adjacent slots).

Each device that is not requesting the bus simply repeats the bus grant signal along.  The
first device that is requesting the bus does not repeat the bus grant signal and assumes
that it now has exclusive use of the bus.  It asserts an acknowledgment back to the
processor, and asserts its interrupt vector, or begins DMA operations as appropriate.

=== Detailed Descriptions

Each of the four combinations of Unibus vs. QBUS and DMA vs. interrupts has little
variations from that general description so we'll briefly introduce those here.  All the
bus signals mentioned below, except the grants, are, like the request line, also common
open-collector signal (wired-OR); i.e. they are broadcast to all devices on the bus.

==== Unibus Non-Processor Grant

The Unibus NPG Arbitration Sequence allows a device to become bus master in order to
perform DMA operations.  The description, starting on page 36, follows the general
description pretty closely.

To start, a device requests the bus by asserting NPR.  The bus arbitrator responds, when
it's ready, by asserting the daisy-chained signal NPG.  The requesting device captures NPG
(doesn't pass it along to devices further down the chain) and asserts SACK to acknowledge
the bus-grant; the arbitrator negates NPG when it sees that acknowledgment.  Important
note: the requesting device must not grab an NPG if it has already started passing it
along for some other device.  More on this later.

When the bus is idle (BBSY, NPG, and SSYN are all negated), the requesting device asserts
BBSY and becomes the bus master.  The requesting device now can run data transfer bus
cycles.  When it's done, the requesting device negates SACK and BBSY and control reverts
to the processor.  footnote:[The formatting of the 1979 __PDP-11 Bus Handbook__ seems to
have gotten broken here.  Immediately following the description of the NPG Arbitration
Sequence, without any sort of header or break, the text goes into describing how to
generate INTR cycles.  Other Unibus descriptions make it clear that the NPG sequence is
only for DMA and not for interrupts.]

==== Unibus Bus Grant

The Unibus also has a priority Bus Grant system with four priority levels that work just
like NPG but requests are made on BR[7..4] and the daisy-chained bus-grant signals are on
BG[7..4].  Once a device becomes bus master, it may run either data transfer cycles (aka
DMA) or an interrupt cycle to pass its interrupt vector to the processor.

==== QBUS DMA Protocol

The QBUS DMA protocol is described starting on page 115 with the timing diagram Figure 2-8
on page 117.  It follows the general description given above exactly.  A device requesting
the bus for DMA asserts DMR.
footnote:[A note on QBUS signal terminology.  A signal like DMR (DMA Request) may show up with
three different names depending on how this signal is being considered, distinguished by a
prefix letter.  A leading B is the signal on the bus; it is inverted logic, that is an
asserted signal is a low voltage (open-collector signals).  A leading T indicates this is
the signal transmitted by a board and a leading R indicates a received signal; these
signals are not inverted.  In addition, the daisy-chained signals (DMG and IAK) often have
a trailing letter (I or O) to indicate if the signal is coming in (from the processor) or
going out (away from the processor).]
When the processor replies with DMGI the device does not pass this through by asserting
DMGO to the next device (not shown in the timing diagram) but captures that bus grant for
itself and asserts SACK to acknowledge that it has the bus.  It then clears DMR which it
was asserting, goes on to do its DMA operations, and clears SACK when it is done.

==== QBUS Interrupt Protocol

The QBUS interrupt protocol diverges the most from the general description we've been
using.  The basic ideas are the same but there are a bunch of details that differ.  The
big difference is that for Unibus interrupts, the interrupt device becomes bus master and
then runs an INTR bus cycle to send its interrupt vector to the processor.  On the QBUS,
the device runs through the bus arbitration but then the processor reads the interrupt
vector from the device similarly to how the processor would read an I/O register from the
device.

The interrupt protocol description starts on page 117 with the timing diagram figure 2-10
on page 120.  The QBUS has four different interrupt request lines IRQ4, IRQ5, IRQ6, and
IRQ7.  A single shared daisy-chained "bus grant" comes back down the bus and into a device
as IAKI and continues out of the device as IAKO.

A device that's requesting an interrupt will not pass an incoming IAKI to IAKO, but will
assume that it has won the bus arbitration.  At that point it deasserts its request,
asserts RPLY and its interrupt vector, and then removes RPLY and its interrupt vector
when it sees IAKI go away.

There is a little more complication with not capturing a bus grant if someone at higher
priority is requesting an interrupt but that's not relevant to the discussion here about
bus arbitration.

The other variation that we have skipped until now is the DIN signal.  We will come back
to this but, for now, just note that DIN (normally used to signal a read cycle on the bus)
is asserted with SYNC not asserted a minimum of 150ns before IAKI is asserted.  This
provides the device advance notice that an interrupt bus grant is coming soon.

== The Problem

Now we focus in on just how a device decides if it is going to pass the bus grant signal
through, or capture it for itself, thereby deciding that it has won the arbitration.  This
decision of whether to pass the bus grant signal or not is where the problem arises.  We
will use the QBUS DMA signal names to be specific in the examples.

The first naive approach is that it is a simple AND gate.  If bus grant comes in and this
device is not requesting the bus, pass the signal through.  In Verilog:

    assign TDMGO = RDMGI & ~bus_request;

In this example, the bus_request signal is generated internally by the device whenever it
decides it wants to acquire the bus for DMA operations.  It is sure a nice,
straightforward implementation but of course if that were all there was to it, I wouldn't
be writing this paper and you wouldn't be reading it.

Consider that the device can decide it wants the bus at any arbitrary time relative to
whatever the processor or any other device on the bus is doing.  So it is possible that
the bus grant may come through as a result of a down-steam device's request just before
this device asserts bus_request.  In that case, TDMGO is asserted briefly and then the
device "takes it back".

Besides being downright rude, this can easily result in two devices both thinking that
they own the bus and chaos ensures when they both start running DMA operations.  Given the
design of the Unibus and QBUS with open-collector bus drivers this is unlikely to let out
the magic smoke but scrambling memory or the data on your disk is almost guaranteed.

The fix, you think, is to latch the fact that you passed through bus grant so you never
"take it back".  Exactly right.  Here is the Verilog for this:

----
always @(posedge RDMGI, posedge RINIT, posedge cycle_finished) begin
   if (RINIT || cycle_finished)
     won_arbitration <= 0;
   else
     won_arbitration <= bus_request;
end
    
assign TDMGO = RDMGI & ~won_arbitration;
----

In this, 'cycle_finished' is a signal from the DMA state machine that gets asserted when
DMA operations are complete.  This will synthesize to something like this:



=== Meta-stability

Now we have a circuit that is an
https://en.wikipedia.org/wiki/Arbiter_(electronics)[arbiter].
footnote:[https://en.wikipedia.org/wiki/Arbiter_(electronics)]
footnote:[http://gunkies.org/wiki/Arbiter]
Since we are doing bus
arbitration, that should be no surprise.  The flip-flop is determining if the positive
edge of RDMGI happens before bus_request goes high.  Flip-flops have specifications called
their setup and hold times.  The data input to the flip-flop must be valid at least the
setup time before the clock and must remain valid at least hold time after the clock
otherwise the flip-flop may enter a
https://en.wikipedia.org/wiki/Metastability_in_electronics[meta-stable state].
footnote:[https://en.wikipedia.org/wiki/Metastability_in_electronics]
footnote:[http://gunkies.org/wiki/Meta-stability]

A latch is a circuit with feedback -- i.e. an output is connected back to an input. In line
with the axiom that 'digital circuits are made out of analog parts', this feedback is not
digital (i.e. restricted to '0' or '1'), but may be any intermediate voltage. Generally,
if the output is 'toward' one of those two values, the circuit moves quickly (via
feedback) all the way to that value. However, if it is balanced precisely in the middle,
it may take a while before it fluctuates to one side or the other, and then rapidly moves
to that value.

The race condition is between the clock to the latch and the data input.  As they change
closer together, the setup and hold time limitations mentioned above are violated, and the
probability of the latch going meta-stable increase.

Note that there is no way to avoid this situation (and considerable theoretical work has
gone into studying it, and 'proves' that there is no solution). The best one can do is
create circuits that ask 'is it still trying to decide', and if so, wait.

Since bus_request can happen at any time relative to bus grant (RDMGI), these setup and
hold times cannot be guaranteed and the output of the arbiter may go meta-stable.  This is
a fundamental property of any arbiter.  The fix is to wait a while to let the
meta-stability settle out.  While there is no time interval you can specify that guarantees
success, the longer you wait the better your chances and in reality it almost always does
settle out pretty quickly.

The key though is that you should not use the arbitration output immediately, and this
circuit does use it immediately to gate the pass-through of RDMGI to TDMGO.  In other
words, it can result in a short pulse of grant being passed through, so that two devices
decide that they won the bus arbitration and chaos reigns as described previously.

=== Glitching

Turns out the circuit here also has another problem; it glitches TDMGO when RDMGI comes in
if bus_request is asserted.  The short explanation of this glitch is that whenever an
input signal travels two paths to an output signal, those two paths may take differing
times and so you want to think about glitches.

In more detail, if the circuit is quiescent then RDGMI is low and won_arbitration is low
which makes [overline]#Q# high, therefore TDMGO is low.  If bus_request is high and RDMGI
goes high, [overline]#Q# is still high briefly so TDMGO will go high.  In a very short
interval, the propagation time of the flip-flop, [overline]#Q# will go low and TDMGO will
go low again.  However, this has glitched TDMGO and some device downstream that is also
requesting DMA may think it just won the bus arbitration.

The fix we will apply for the meta-stability problem will fix the glitch as well.

== The Solution

=== The Idea

The basic idea is simple.  Since the problem comes from trying to use the arbitration
output immediately, we should wait a while before using it.  If we could do the
arbitration some time before the bus grant signal arrived then we could let any
meta-stability settle out before we had to pass gate bus grant through or not using that
pre-decided answer.

=== QBUS DMA

For the bus grant on Unibus or DMA on the QBUS, there is no early indication that a bus
grant is soon to come but we can get that effect by running the bus grant through a delay.
The un-delayed signal clocks the arbiter and the delayed bus grant is passed down the
chain or not.

This circuit looks like this:



Now the output of the Arbiter, possibly meta-stable, will not be sent out to TDMGO until
'delay' after RDMGI's positive edge, by which time it ought to have stabilized on an
answer to the question of whether bus_request or RDMGI happened first.  The
won_arbitration needs this type of protection as well.

DEC's DC010 Direct Memory Access Logic chip
footnote:[http://bitsavers.trailing-edge.com/pdf/dec/qbus/Chipkit_Users_Manual_1982.pdf[ChipKit Users Manual] pg.43 Figure 18]
uses a delay line just like this but since delay lines are not available in most FPGAs, we
can use a bucket-brigade of flip-flops to get a similar effect.  Note that this
bucket-brigade is the same circuit as a synchronizer used when signals travel between
clock domains.

Here is the Verilog for this final design with its circuit:

----
always @(posedge RDMGI, posedge RINIT, posedge cycle_finished) begin
   if (RINIT || cycle_finished)
     won_arbitration <= 0;
   else
     won_arbitration <= bus_request;
end

reg RDMGIra[1:0];
reg RDMGI_delayed = RDMGIra[1];
always @(posedge CLK)
  RDMGIra <= { RDMGIra[0], RDMGI };

assign TDMGO = RDMGI_delayed & ~won_arbitration;
----



Obviously this adds delay to the bus grant chain at each device in the chain.  How much of
a problem is this?  From page 117:

____
Propagation delay from BDMGI L to BDMGO L must be less than 500 ns per LSI-11 bus slot.
Since this delay directly affects system performance, it should be kept as short as
possible.
____

With a 20MHz clock, two flip-flops will add between 50ns and 100ns of delay depending on
the phase relationship of the incoming bus grant with the clock, well within the spec.
footnote:[We are unable to find the Unibus spec for this delay.]
Looking at the timing table for the DC010 chip mentioned above,
footnote:[Ibid pg.54 Table 10] 
the total propagation delay high-low is between 95 and 220ns while low-high is between 15
and 60ns.  Apparently DEC considered delays of this order acceptable in practice as well as
in theory.

=== FPGAs and Glitching

One final consideration comes up when implementing this on an FPGA.  Specifically, what
about that AND gate that's feeding TDMGO and what happens if the output of the Arbiter
flip-flop goes meta-stable for a little while?  On a real AND gate, holding one input low
means the output will be low no matter what the other input does.  But what about an AND
gate that's implemented by other means, like the LUTs in an FPGA?  It turns out that
FPGA's LUTs are built to be glitch-free in the face of a single input changing.  So it's a
problem worth considering but, at least in the case of FPGAs, this works.

=== Unibus DMA and Interrupts

We have used the QBUS for our specifics so far but it all works the same on the Unibus,
just wire this circuit up to NPR/NPG or BRn/BGn depending on your desired priority.
However, an interesting difference between the QBUS and Unibus happens once you've won
arbitration and want to generate an interrupt.  On the Unibus, the device runs an INTR bus
cycle that basically writes the interrupt vector into the interrupt fielding processor.
On the QBUS, after the arbitrator has granted the bus to some device requesting an
interrupt, the processor runs what looks very much like a DATI cycle (bus read) to read
the interrupt vector from the device.

This means the implementation of interrupts on the Unibus vs QBUS are quite different
once the bus arbitration is done.  Implementing interrupts on a Unibus device needs a
state machine -- simpler than the DMA state machine but a state machine nonetheless -- to
sequence through the bus signals needed to run the INTR bus cycle.  On the QBUS, interrupt
processing on a slave device is simply another register read.  It's driven off RDIN and
won_arbitration rather than an address match but it's otherwise very similar.  No state
machine is needed, just combinational logic.

=== QBUS Interrupts

In the QBUS interrupt protocol, as mentioned earlier, BDIN is asserted at least 150ns
before bus grant (BIAKI).  So if we clock the arbitrator flip-flop on RDIN, we get a
minimum of 150ns to let any meta-stability clear before we use the signal.  The Verilog
for this is:

----
always @(posedge RDIN, posedge RINIT) begin
   if (RINIT)
     interrupt_mine <= 0;
   else if (irql && !irq_higher)
     interrupt_mine <= 1;
   else
     interrupt_mine <= 0;
end

assign TIAKO = RIAKI & ~interrupt_mine;
----

This should look very similar to the bus grant logic we considered previously with the
change that we clock the arbiter flip-flop off RDIN while we pass RIAKI rather than doing
both off the bus grant.  The irql signal is a latched version of the internal interrupt
request line on the device and irq_higher is a calculation among the four QBUS interrupt
request lines to make sure some higher priority interrupt isn't currently being requested.

The synthesized circuit would look something like this (the irq_higher part removed as it
just muddies the picture):



Again, the output of the Arbiter may be meta-stable for a little while so those outputs
should not be used until they have time to settle.  Gating the output with RIAKI, which
will be low during any potential meta-stability, provides that protection.  The
interrupt_mine signal gets this protection as well, as you'll see below.

One bit of subtlety here is that only RDIN clocks the Arbiter.  Since RDIN is also used to
signal DATI (data read) cycles on the QBUS, doesn't that confuse things?  The processor
asserts RDIN while RSYNC is negated to provide the early indication that the it is about
to assert RIAKI to read an interrupt vector.  So why are we not including RSYNC in here
somewhere?  Well, we could but it turns out it doesn't matter.  Since the output of the
Arbiter is only used when RIAKI gets asserted, clocking in irql on every RDIN transition
doesn't hurt anything and it simplifies the circuit a little.  Also, once our interrupt
vector is read and irql is negated, the next RDIN will clear the Arbiter flip-flop
naturally so we don't have to add some circuitry to deal with that.

This is only a small piece of the QBUS interrupt circuitry and on the QBUS, unlike on
the Unibus, the rest of the interrupt processing is a part of the bus arbitration
sequence.  So here is that arbiter in a little more context.  The interrupt_request
line comes from the device when it wants to trigger an interrupt; TIRQn expands to the
different IRQ signals depending on what priority this device is configured for; 
assert_vector is a signal to the register read circuitry that causes it to put the
interrupt vector on the BDAL lines rather than I/O register contents; and, as before, the
irq_higher logic has been omitted for clarity.

When RIAKI comes in, we either pass it through to TIKAO or assert our own interrupt vector
as determined by the bus arbitration flip-flop which was clocked off RDIN at least 150ns
earlier.  When we assert the interrupt vector, then we also clear the interrupt request
flip-flop and negate TIRQn.



== Conclusion

There is no revealed wisdom here.  These are just the opinions of the author and not
inside information from DEC engineers.  We present the information to aid those in the
community who experiment with their own device designs.  We welcome feedback and
discussion to make this information as complete and correct as possible.

== Acknowledgments

The author gratefully acknowledges the assistance of Noel Chiappa in working through
questions about how the Unibus and QBUS work as well as reviewing this paper not to
mention starting the QSIC project
footnote:[http://pdp10.froghouse.org/qsic/html/overview.html]
that lead to discovering all this stuff in the first place.

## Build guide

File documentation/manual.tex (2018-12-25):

% -*- LaTeX -*-
%
% QSIC/USIC Manual

\documentclass[12pt]{book}

\usepackage{array}
\usepackage{longtable}
%\usepackage{graphicx}
\usepackage[hidelinks=true]{hyperref}

\input{register-diagram.def}

\newcommand{\code}[1]{\textsf{#1}}
\newcommand{\regaddr}[1]{{\hspace{3em} \small\tt Address = #1}}

% Gives me a non-justified paragraph inside a table
\newcolumntype{P}[1]{>{\raggedright\arraybackslash}p{#1}}
% Gives me a \tt column inside a table
\newcolumntype{B}[0]{>{\tt\arraybackslash}l}

% The table used throughout for describing bits in registers.
\newenvironment{bittable}
               { \begin{longtable}{BP{0.22\textwidth}p{0.6\textwidth}}
                   {\bf Bit} &
                   {\bf Designation} &
                   {\bf Description and Operation}  \endhead }
               { \end {longtable}}
                 
\includeonly{
  qsic,
  rk11-f,
  rp11-d,
  enable
}

\title{QBUS/Unibus Storage and \\ Input/Output Card \\
  (QSIC/USIC) \\ Programming Manual}
\author{David Bridgham \and Noel Chiappa}

\begin{document}
\maketitle
\pagenumbering{roman}
\tableofcontents\newpage

\pagenumbering{arabic}
\pagestyle{headings}

\include{qsic}
\include{rk11-f}
\include{rp11-d}
\include{enable}

\end{document}

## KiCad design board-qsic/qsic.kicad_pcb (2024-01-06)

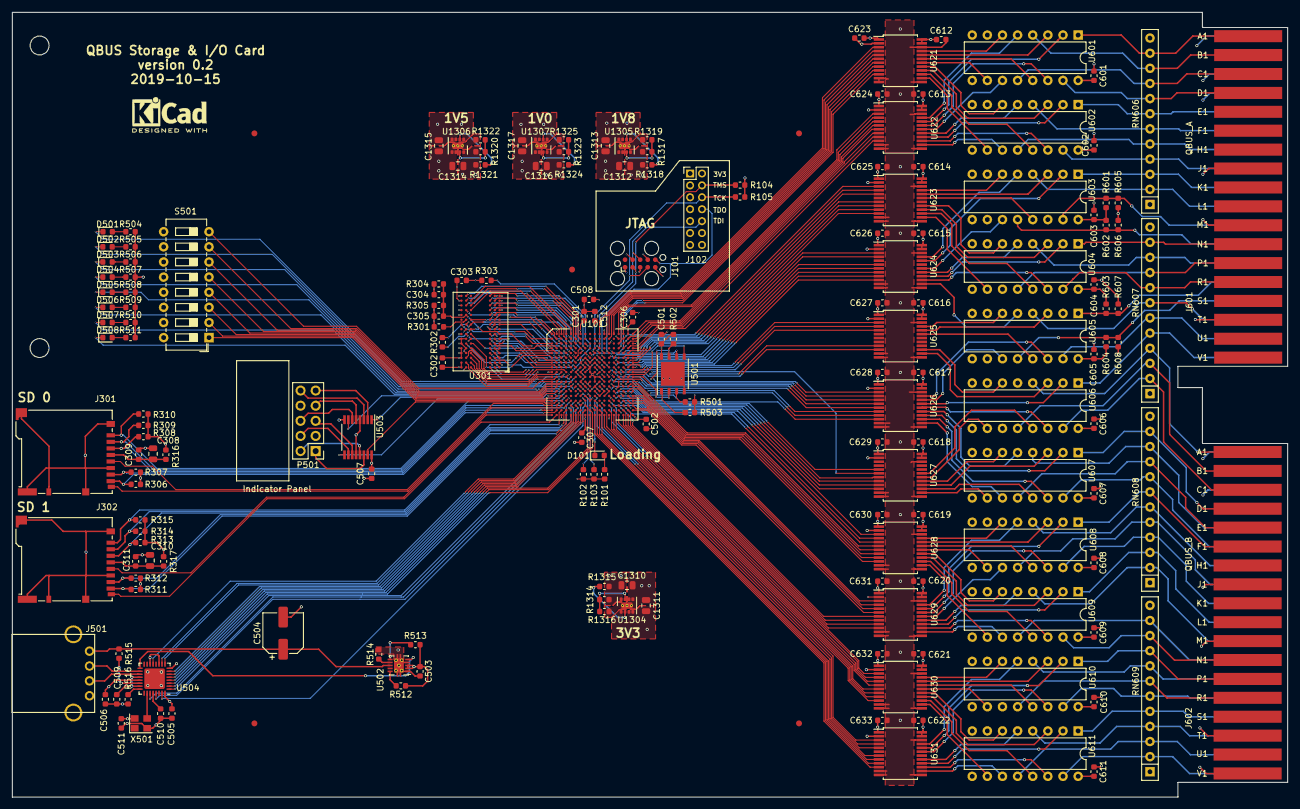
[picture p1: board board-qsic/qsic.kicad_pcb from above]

Board: 4 copper layers, 214.1 x 131.7 mm, 183 parts (0 on the bottom side), 358 nets.

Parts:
C301, C306, C508, C512: 10µF; C_0603_1608Metric
C302, C303, C304, C305, C309, C311, C501, C503, C505, C506, C507, C601, C602, C603, C604, C605, C606, C607, C608, C609, C610, C611, C612, C613, C614, C615, C616, C617, C618, C619, C620, C621, C622, C623, C624, C625, C626, C627, C628, C629, C630, C631, C632, C633: 100nF; C_0603_1608Metric
C307, C502: 10uF; C_0603_1608Metric
C308, C310, C1310, C1312, C1314, C1316: 22µF; C_0805_2012Metric
C504: 150µF; CP_Elec_6.3x5.7
C509, C510: 1µF; C_0603_1608Metric
C511: 10nF; C_0603_1608Metric
C1311, C1313, C1315, C1317: 10µF; C_0805_2012Metric
D101, D501, D502, D503, D504, D505, D506, D507, D508: green; LED_0603_1608Metric
FID101, FID102, FID103, FID104, FID105: Fiducial; Fiducial_1mm_Mask2mm
J101: Conn_02x05_Odd_Even; Tag-Connect_TC2050-IDC-FP_2x05_P1.27mm_Vertical
J102: Conn_02x07_Odd_Even; PinHeader_2x07_P2.00mm_Vertical
J301: SD 0; microSD_HC_Hirose_DM3BT-DSF-PEJS
J302: SD 1; microSD_HC_Hirose_DM3BT-DSF-PEJS
J501: USB_A; USB-A-Amphenol-UE27
J601: QBUS_A; DEC_Edge_Fingers_single_height
J602: QBUS_B; DEC_Edge_Fingers_single_height
LOGO101: Logo_Open_Hardware_Small; KiCad-Logo2_5mm_SilkScreen
P501: Indicator Panel; Box_Header_2x05_P2.54mm
R101, R301, R504, R505, R506, R507, R508, R509, R510, R511: 240; R_0603_1608Metric
R102, R103, R501, R502: 4.7k; R_0603_1608Metric
R104, R105: 10k; R_0603_1608Metric
R302: 89; R_0603_1608Metric
R303: 47k; R_0603_1608Metric
R304, R305: 47 1%; R_0603_1608Metric
R306, R307, R308, R309, R310, R311, R312, R313, R314, R315: 50k; R_0603_1608Metric
R316, R317: 4.7; R_0603_1608Metric
R503: 2.4k; R_0603_1608Metric
R512, R513: 100k; R_0603_1608Metric
R514: 56.2k; R_0603_1608Metric
R515: 20k; R_0603_1608Metric
R516: 8.06k; R_0603_1608Metric
R601, R602, R603, R604: 330; R_0603_1608Metric
R605, R606, R607, R608: 680; R_0603_1608Metric
R1314: 511k; R_0603_1608Metric
R1315, R1318, R1321, R1324: 499k; R_0603_1608Metric
R1316, R1319, R1322, R1325: 162k; R_0603_1608Metric
R1317: 200k; R_0603_1608Metric
R1320: 143k; R_0603_1608Metric
R1323: 40.2; R_0603_1608Metric
RN606, RN607, RN608, RN609: 330/680; R_Array_SIP12
S501: Config; SW_DIP_SPSTx08_Slide_6.7x21.88mm_W7.62mm_P2.54mm_LowProfile
U101: XC7A75T-CSG324; BGA-324_15.0x15.0mm_Layout18x18_P0.8mm_Ball0.5mm_Pad0.4mm_N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
U301: IS43TR16128B; BGA-96_9.0x13.0mm_Layout2x3x16_P0.8mm
U501: MT25Q-mlq8; DFN-8-1EP_6x5mm_P1.27mm_EP4x4mm
U502: TPS2561; VSON-10-1EP_3x3mm_P0.5mm_EP1.65x2.4mm_ThermalVias
U503: MAX3033E; TSSOP-16_4.4x5mm_P0.65mm
U504: USB3340; QFN-32-1EP_5x5mm_P0.5mm_EP3.45x3.45mm
U601, U602, U603, U604, U605, U606, U607, U608, U609, U610, U611: DS8641-small; DIP-16_W7.62mm
U621, U622, U623, U624, U625, U626, U627, U628, U629, U630, U631: 74LVC8T245-small; SSOP-24_5.3x8.2mm_P0.65mm
U1304, U1305, U1306, U1307: TPS82085; Texas_SIL0008D_MicroSiP-8-1EP_2.8x3mm_P0.65mm_EP1.1x1.9mm_T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
X501: ASE-24.000MHz; Oscillator_SMD_Abracon_ASE-4Pin_3.2x2.5mm

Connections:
/1V0: C512.1, C1316.1, R1323.1, R1324.1, U101.F8, U101.F10, U101.G7, U101.G9, U101.G11, U101.H8, U101.J7, U101.J11, U101.K8, U101.L7, U101.L11, U101.M8, U101.M10, U101.N7, U101.N9, U101.N11, U1307.8
/1V5: C301.1, C302.1, C303.1, C304.1, C1314.1, R304.1, R1320.1, R1321.1, U101.A7, U101.C3, U101.D6, U101.F2, U101.G5, U101.J1, U301.A1, U301.A8, U301.B2, U301.C1, U301.C9, U301.D2, U301.D9, U301.E9, U301.F1, U301.G7, U301.H2, U301.H9, U301.K2, U301.K8, U301.N1, U301.N9, U301.R1, U301.R9, U1306.8
/1V8: C508.1, C1312.1, R1317.1, R1318.1, U101.B10, U101.F12, U101.H10, U101.H12, U101.K12, U101.M12, U1305.8
/3V3: C306.1, C307.1, C501.1, C502.1, C505.1, C506.1, C507.1, C511.1, C623.1, C624.1, C625.1, C626.1, C627.1, C628.1, C629.1, C630.1, C631.1, C632.1, C633.1, C1310.1, J101.1, J102.2, R101.1, R102.1, R103.1, R104.1, R105.1, R306.1, R307.1, R308.1, R309.1, R310.1, R311.1, R312.1, R313.1, R314.1, R315.1, R316.2, R317.2, R501.1, R502.1, R503.1, R504.1, R505.1, R506.1, R507.1, R508.1, R509.1, R510.1, R511.1, R1314.1, R1315.1, U101.A17, U101.C13, U101.D16, U101.G15, U101.H18, U101.K4, U101.K14, U101.L17, U101.N3, U101.N13, U101.P6, U101.P8, U101.P12, U101.P16, U101.R9, U101.T2, U101.T12, U101.U5, U101.U15, U101.V8, U101.V18, U501.8, U503.4, U503.12, U503.16, U504.8, U504.11, U504.14, U504.21, U504.32, U621.1, U622.1, U622.2, U623.1, U624.1, U624.2, U625.1, U626.1, U626.2, U627.1, U628.1, U629.1, U629.2, U630.1, U631.1, U631.2, U1304.8, X501.4
/5V0: C503.1, C601.1, C602.1, C603.1, C604.1, C605.1, C606.1, C607.1, C608.1, C609.1, C610.1, C611.1, C612.1, C613.1, C614.1, C615.1, C616.1, C617.1, C618.1, C619.1, C620.1, C621.1, C622.1, C1311.1, C1313.1, C1315.1, C1317.1, J601.A2, J601.D2, J602.A2, J602.V1, R512.1, R513.1, R601.1, R602.1, R603.1, R604.1, RN606.12, RN607.12, RN608.12, RN609.12, U502.2, U502.3, U601.16, U602.16, U603.16, U604.16, U605.16, U606.16, U607.16, U608.16, U609.16, U610.16, U611.16, U621.23, U621.24, U622.23, U622.24, U623.23, U623.24, U624.23, U624.24, U625.23, U625.24, U626.23, U626.24, U627.23, U627.24, U628.23, U628.24, U629.23, U629.24, U630.23, U630.24, U631.23, U631.24, U1304.1, U1304.3, U1304.4, U1305.1, U1305.3, U1305.4, U1306.1, U1306.3, U1306.4, U1307.1, U1307.3, U1307.4
/Memory/A0: U101.C5, U301.N3
/Memory/A1: U101.B6, U301.P7
/Memory/A2: U101.C7, U301.P3
/Memory/A3: U101.D5, U301.N2
/Memory/A4: U101.A3, U301.P8
/Memory/A5: U101.E7, U301.P2
/Memory/A6: U101.A4, U301.R8
/Memory/A7: U101.C6, U301.R2
/Memory/A8: U101.A6, U301.T8
/Memory/A9: U101.D8, U301.R3
/Memory/A10: U101.B2, U301.L7
/Memory/A11: U101.A5, U301.R7
/Memory/A12: U101.B3, U301.N7
/Memory/A13: U101.B7, U301.T3
/Memory/BA0: U101.E5, U301.M2
/Memory/BA1: U101.A1, U301.N8
/Memory/BA2: U101.E6, U301.M3
/Memory/CAS#: U101.D3, U301.K3
/Memory/CK: R302.2, U101.C4, U301.J7
/Memory/CK#: R302.1, U101.B4, U301.K7
/Memory/CKE: U101.B1, U301.K9
/Memory/DML: U101.G1, U301.E7
/Memory/DMU: U101.G6, U301.D3
/Memory/DQL0: U101.H1, U301.E3
/Memory/DQL1: U101.F1, U301.F7
/Memory/DQL2: U101.E2, U301.F2
/Memory/DQL3: U101.E1, U301.F8
/Memory/DQL4: U101.F4, U301.H3
/Memory/DQL5: U101.C1, U301.H8
/Memory/DQL6: U101.F3, U301.G2
/Memory/DQL7: U101.D2, U301.H7
/Memory/DQSL: U101.H2, U301.F3
/Memory/DQSL#: U101.G2, U301.G3
/Memory/DQSU: U101.J4, U301.C7
/Memory/DQSU#: U101.H4, U301.B7
/Memory/DQU0: U101.G4, U301.D7
/Memory/DQU1: U101.H5, U301.C3
/Memory/DQU2: U101.G3, U301.C8
/Memory/DQU3: U101.H6, U301.C2
/Memory/DQU4: U101.J2, U301.A7
/Memory/DQU5: U101.J3, U301.A2
/Memory/DQU6: U101.K1, U301.B8
/Memory/DQU7: U101.K2, U301.A3
/Memory/ODT: U101.F5, U301.K1
/Memory/RAS#: U101.E3, U301.J3
/Memory/RESET#: R303.1, U101.J5, U301.T2
/Memory/VREF15: C304.2, C305.1, R304.2, R305.1, U101.D7, U101.F6, U301.H1, U301.M8
/Memory/WE#: U101.D4, U301.L3
/QBUS & I/O/CCLK: U101.E9, U501.6
/QBUS & I/O/IPblank_N: P501.7, U503.5
/QBUS & I/O/IPblank_P: P501.6, U503.6
/QBUS & I/O/IPclk_N: P501.10, U503.3
/QBUS & I/O/IPclk_P: P501.9, U503.2
/QBUS & I/O/IPdata_N: P501.2, U503.13
/QBUS & I/O/IPdata_P: P501.1, U503.14
/QBUS & I/O/IPlatch_N: P501.5, U503.11
/QBUS & I/O/IPlatch_P: P501.4, U503.10
/QBUS & I/O/LED_0: D501.1, U101.K3
/QBUS & I/O/LED_1: D502.1, U101.K5
/QBUS & I/O/LED_2: D503.1, U101.K6
/QBUS & I/O/LED_3: D504.1, U101.L4
/QBUS & I/O/LED_4: D505.1, U101.L5
/QBUS & I/O/LED_5: D506.1, U101.N5
/QBUS & I/O/LED_6: D507.1, U101.M6
/QBUS & I/O/LED_7: D508.1, U101.M3
/QBUS & I/O/QBUS-int/BBS7: J601.P2, RN607.10, U604.4
/QBUS & I/O/QBUS-int/BDAL0: J601.U2, RN607.6, U605.15
/QBUS & I/O/QBUS-int/BDAL1: J601.V2, RN607.5, U606.1
/QBUS & I/O/QBUS-int/BDAL2: J602.E2, RN608.10, U607.4
/QBUS & I/O/QBUS-int/BDAL3: J602.F2, RN608.8, U607.15
/QBUS & I/O/QBUS-int/BDAL4: J602.H2, RN608.6, U608.4
/QBUS & I/O/QBUS-int/BDAL5: J602.J2, RN608.5, U608.12
/QBUS & I/O/QBUS-int/BDAL6: J602.K2, RN608.4, U608.15
/QBUS & I/O/QBUS-int/BDAL7: J602.L2, RN608.3, U609.1
/QBUS & I/O/QBUS-int/BDAL8: J602.M2, RN608.2, U609.4
/QBUS & I/O/QBUS-int/BDAL9: J602.N2, RN609.11, U609.12
/QBUS & I/O/QBUS-int/BDAL10: J602.P2, RN609.8, U610.4
/QBUS & I/O/QBUS-int/BDAL11: J602.R2, RN609.6, U610.15
/QBUS & I/O/QBUS-int/BDAL12: J602.S2, RN609.5, U611.1
/QBUS & I/O/QBUS-int/BDAL13: J602.T2, RN609.4, U611.4
/QBUS & I/O/QBUS-int/BDAL14: J602.U2, RN609.3, U611.12
/QBUS & I/O/QBUS-int/BDAL15: J602.V2, RN609.2, U611.15
/QBUS & I/O/QBUS-int/BDAL16: J601.C1, RN606.9, U601.12
/QBUS & I/O/QBUS-int/BDAL17: J601.D1, RN606.8, U601.15
/QBUS & I/O/QBUS-int/BDAL18: J602.C1, RN607.2, U606.15
/QBUS & I/O/QBUS-int/BDAL19: J602.D1, RN608.11, U607.1
/QBUS & I/O/QBUS-int/BDAL20: J602.E1, RN608.9, U607.12
/QBUS & I/O/QBUS-int/BDAL21: J602.F1, RN608.7, U608.1
/QBUS & I/O/QBUS-int/BDCOK: J602.A1, RN607.4, U606.4
/QBUS & I/O/QBUS-int/BDIN: J601.H2, RN606.5, U602.12
/QBUS & I/O/QBUS-int/BDMGI: J601.R2, R603.2, R607.1, U605.1
/QBUS & I/O/QBUS-int/BDMGO: J601.S2, R604.2, R608.1, U605.12
/QBUS & I/O/QBUS-int/BDMR: J601.N1, RN607.11, U604.1
/QBUS & I/O/QBUS-int/BDOUT: J601.E2, RN606.7, U602.1
/QBUS & I/O/QBUS-int/BEVNT: J602.R1, RN609.7, U610.12
/QBUS & I/O/QBUS-int/BHALT: J601.P1, RN607.9, U604.12
/QBUS & I/O/QBUS-int/BIAKI: J601.M2, R601.2, R605.1, U603.15
/QBUS & I/O/QBUS-int/BIAKO: J601.N2, R602.2, R606.1, U603.12
/QBUS & I/O/QBUS-int/BINIT: J601.T2, RN607.7, U605.4
/QBUS & I/O/QBUS-int/BIRQ4: J601.L2, RN606.2, U603.4
/QBUS & I/O/QBUS-int/BIRQ5: J601.A1, RN606.11, U601.1
/QBUS & I/O/QBUS-int/BIRQ6: J601.B1, RN606.10, U601.4
/QBUS & I/O/QBUS-int/BIRQ7: J602.P1, RN609.9, U610.1
/QBUS & I/O/QBUS-int/BPOK: J602.B1, RN607.3, U606.12
/QBUS & I/O/QBUS-int/BREF: J601.R1, RN607.8, U604.15
/QBUS & I/O/QBUS-int/BRPLY: J601.F2, RN606.6, U602.4
/QBUS & I/O/QBUS-int/BSACK: J602.N1, RN609.10, U609.15
/QBUS & I/O/QBUS-int/BSYNC: J601.J2, RN606.4, U602.15
/QBUS & I/O/QBUS-int/BWTBT: J601.K2, RN606.3, U603.1
/QBUS & I/O/RBS7: U101.E18, U623.7
/QBUS & I/O/RDAL0: U101.H16, U625.5
/QBUS & I/O/RDAL1: U101.J13, U625.10
/QBUS & I/O/RDAL2: U101.N14, U627.7
/QBUS & I/O/RDAL3: U101.P15, U627.9
/QBUS & I/O/RDAL4: U101.R16, U628.3
/QBUS & I/O/RDAL5: U101.M17, U628.6
/QBUS & I/O/RDAL6: U101.T16, U628.5
/QBUS & I/O/RDAL7: U101.N17, U628.8
/QBUS & I/O/RDAL8: U101.M18, U628.7
/QBUS & I/O/RDAL9: U101.P17, U628.10
/QBUS & I/O/RDAL10: U101.V16, U630.3
/QBUS & I/O/RDAL11: U101.T13, U630.5
/QBUS & I/O/RDAL12: U101.V14, U630.8
/QBUS & I/O/RDAL13: U101.U14, U630.7
/QBUS & I/O/RDAL14: U101.U12, U630.10
/QBUS & I/O/RDAL15: U101.U13, U630.9
/QBUS & I/O/RDAL16: U101.B13, U621.6
/QBUS & I/O/RDAL17: U101.A13, U621.5
/QBUS & I/O/RDAL18: U101.N15, U627.5
/QBUS & I/O/RDAL19: U101.P14, U627.8
/QBUS & I/O/RDAL20: U101.R15, U627.10
/QBUS & I/O/RDAL21: U101.R13, U628.4
/QBUS & I/O/RDCOK: U101.J15, U625.9
/QBUS & I/O/RDIN: U101.E15, U621.10
/QBUS & I/O/RDMGI: U101.J18, U625.4
/QBUS & I/O/RDMR: U101.F16, U623.8
/QBUS & I/O/RDOUT: U101.A15, U621.8
/QBUS & I/O/REVNT: U101.T14, U630.6
/QBUS & I/O/RHALT: U101.E16, U623.10
/QBUS & I/O/RIAKI: U101.E17, U623.5
/QBUS & I/O/RINIT: U101.J17, U625.3
/QBUS & I/O/RIRQ4: U101.B16, U623.3
/QBUS & I/O/RIRQ5: U101.B12, U621.4
/QBUS & I/O/RIRQ6: U101.A11, U621.3
/QBUS & I/O/RIRQ7: U101.V15, U630.4
/QBUS & I/O/RPOK: U101.H14, U627.6
/QBUS & I/O/RREF: U101.F18, U623.9
/QBUS & I/O/RRPLY: U101.A14, U621.7
/QBUS & I/O/RSACK: U101.P18, U628.9
/QBUS & I/O/RSYNC: U101.D15, U621.9
/QBUS & I/O/RWTBT: U101.C16, U623.4
/QBUS & I/O/SW_0: S501.8, U101.L1
/QBUS & I/O/SW_1: S501.7, U101.L3
/QBUS & I/O/SW_2: S501.6, U101.M1
/QBUS & I/O/SW_3: S501.5, U101.M2
/QBUS & I/O/SW_4: S501.4, U101.N1
/QBUS & I/O/SW_5: S501.3, U101.N2
/QBUS & I/O/SW_6: S501.2, U101.P2
/QBUS & I/O/SW_7: S501.1, U101.R1
/QBUS & I/O/TBS7: U101.G18, U624.7
/QBUS & I/O/TDAL0: U101.K13, U626.3
/QBUS & I/O/TDAL1: U101.J14, U626.5
/QBUS & I/O/TDAL2: U101.L18, U626.7
/QBUS & I/O/TDAL3: U101.N16, U626.9
/QBUS & I/O/TDAL4: U101.R18, U629.3
/QBUS & I/O/TDAL5: U101.U18, U629.6
/QBUS & I/O/TDAL6: U101.T18, U629.5
/QBUS & I/O/TDAL7: U101.U17, U629.8
/QBUS & I/O/TDAL8: U101.T15, U629.7
/QBUS & I/O/TDAL9: U101.U16, U629.10
/QBUS & I/O/TDAL10: U101.V12, U631.3
/QBUS & I/O/TDAL11: U101.R10, U631.5
/QBUS & I/O/TDAL12: U101.V11, U631.8
/QBUS & I/O/TDAL13: U101.U11, U631.7
/QBUS & I/O/TDAL14: U101.V10, U631.10
/QBUS & I/O/TDAL15: U101.T10, U631.9
/QBUS & I/O/TDAL16: U101.B17, U622.6
/QBUS & I/O/TDAL17: U101.A18, U622.5
/QBUS & I/O/TDAL18: U101.K15, U626.6
/QBUS & I/O/TDAL19: U101.M16, U626.8
/QBUS & I/O/TDAL20: U101.M13, U626.10
/QBUS & I/O/TDAL21: U101.R17, U629.4
/QBUS & I/O/TDIN: U101.D18, U622.10
/QBUS & I/O/TDMGO: U101.K16, U626.4
/QBUS & I/O/TDMR: U101.G14, U624.8
/QBUS & I/O/TDOUT: U101.C17, U622.8
/QBUS & I/O/TIAKO: U101.G17, U624.6
/QBUS & I/O/TINIT: U101.H17, U624.10
/QBUS & I/O/TIRQ4: U101.F14, U624.3
/QBUS & I/O/TIRQ5: U101.A16, U622.4
/QBUS & I/O/TIRQ6: U101.C15, U622.3
/QBUS & I/O/TIRQ7: U101.T11, U631.4
/QBUS & I/O/TREF: U101.G16, U624.9
/QBUS & I/O/TRPLY: U101.B18, U622.7
/QBUS & I/O/TSACK: U101.V17, U629.9
/QBUS & I/O/TSYNC: U101.D17, U622.9
/QBUS & I/O/TWTBT: U101.F13, U624.4
/QBUS & I/O/ip_blank: U101.M4, U503.7
/QBUS & I/O/ip_clk: U101.N4, U503.1
/QBUS & I/O/ip_data: U101.R2, U503.15
/QBUS & I/O/ip_latch: U101.P3, U503.9
/QBUS & I/O/sd0_clk: J301.5, U101.T1
/QBUS & I/O/sd0_cmd: J301.3, R308.2, U101.T4
/QBUS & I/O/sd0_dat0: J301.7, R307.2, U101.U1
/QBUS & I/O/sd0_dat1: J301.8, R306.2, U101.U2
/QBUS & I/O/sd0_dat2: J301.1, R310.2, U101.P4
/QBUS & I/O/sd0_dat3: J301.2, R309.2, U101.R3
/QBUS & I/O/sd0_det: J301.9, U101.T3
/QBUS & I/O/sd1_clk: J302.5, U101.V1
/QBUS & I/O/sd1_cmd: J302.3, R313.2, U101.R5
/QBUS & I/O/sd1_dat0: J302.7, R312.2, U101.R6
/QBUS & I/O/sd1_dat1: J302.8, R311.2, U101.V4
/QBUS & I/O/sd1_dat2: J302.1, R315.2, U101.U3
/QBUS & I/O/sd1_dat3: J302.2, R314.2, U101.U4
/QBUS & I/O/sd1_det: J302.9, U101.V2
/QBUS & I/O/usb0_clk60: U101.T5, U504.1
/QBUS & I/O/usb0_d0: U101.V9, U504.3
/QBUS & I/O/usb0_d1: U101.T8, U504.4
/QBUS & I/O/usb0_d2: U101.U8, U504.5
/QBUS & I/O/usb0_d3: U101.V7, U504.6
/QBUS & I/O/usb0_d4: U101.U7, U504.7
/QBUS & I/O/usb0_d5: U101.V6, U504.9
/QBUS & I/O/usb0_d6: U101.U6, U504.10
/QBUS & I/O/usb0_d7: U101.V5, U504.13
/QBUS & I/O/usb0_dir: U101.R8, U504.31
/QBUS & I/O/usb0_nxt: U101.U9, U504.2
/QBUS & I/O/usb0_resetb: U101.T6, U504.27
/QBUS & I/O/usb0_stp: U101.R7, U504.29
/TCK: J101.4, J102.6, R105.2, U101.E10
/TDI: J101.8, J102.10, U101.E11
/TDO: J101.6, J102.8, U101.E13
/TMS: J101.2, J102.4, R104.2, U101.E12
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

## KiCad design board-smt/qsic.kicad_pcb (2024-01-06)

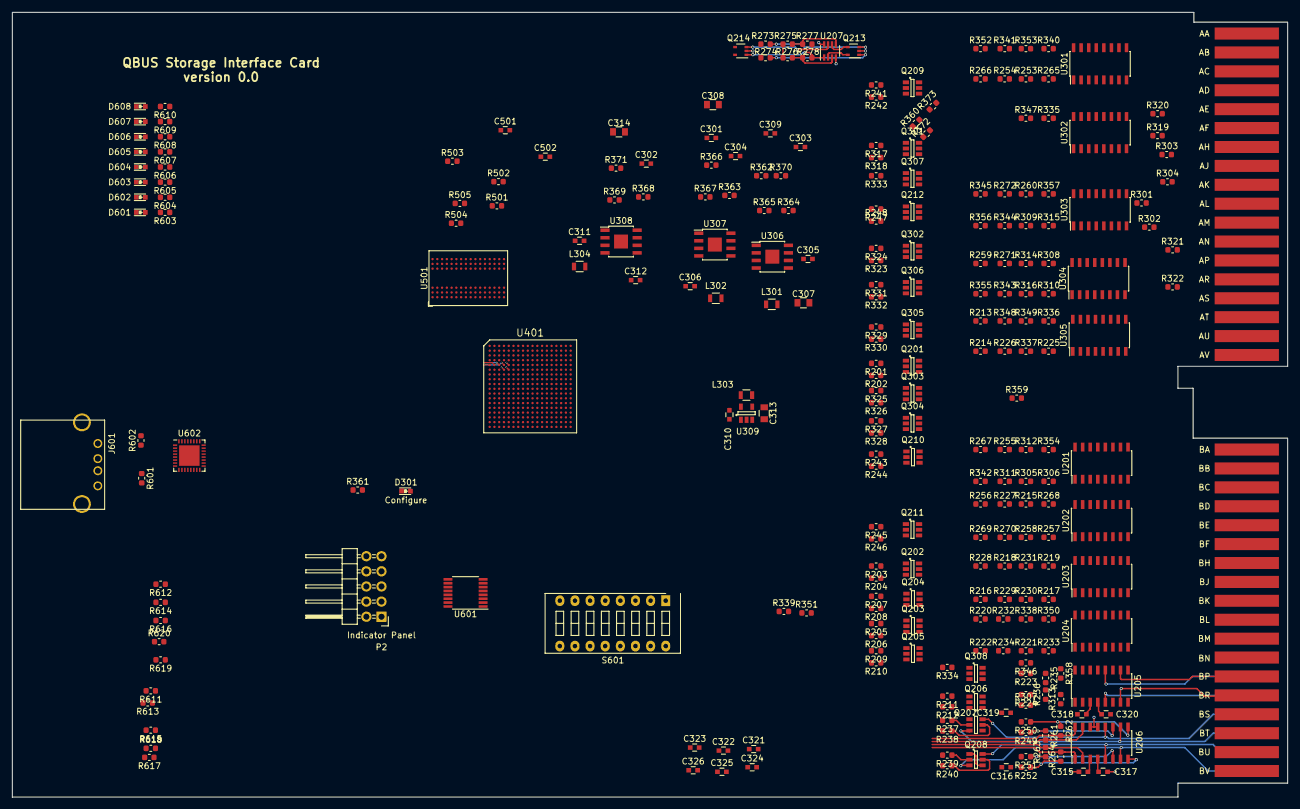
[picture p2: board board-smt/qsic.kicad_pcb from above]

Board: 4 copper layers, 214.1 x 131.7 mm, 263 parts (0 on the bottom side), 270 nets.

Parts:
B101: QBUS; Qbus-double
C301, C302, C309, C310: 10uF; C_0603
C303, C304: 2.2nF; C_0603
C305, C306, C311, C312, C315, C316, C317, C318, C319, C320, C321, C322, C323, C324, C325, C326, C501, C502: 100nF; C_0603
C307, C308, C313, C314: 22uF; C_0805
D301: Configure; LED-0603
D601: LED 0; LED-0603
D602: LED 1; LED-0603
D603: LED 2; LED-0603
D604: LED 3; LED-0603
D605: LED 4; LED-0603
D606: LED 5; LED-0603
D607: LED 6; LED-0603
D608: LED 7; LED-0603
J601: USB_A
L301, L302: 4.7uH; R_0805
L303: 1.5uH; R_0805
L304: 2.2uH; R_0805
P2: Indicator Panel; Pin_Header_Angled_2x05
Q201, Q202, Q203, Q204, Q205, Q206, Q207, Q208, Q209, Q210, Q211, Q212, Q301, Q302, Q303, Q304, Q305, Q306, Q307, Q308: Dual_NMOS; SOT-23-6
Q213, Q214: DMN32; SOT-353_SC-70-5
R201, R202, R203, R204, R205, R206, R207, R208, R209, R210, R211, R212, R237, R238, R239, R240, R241, R242, R243, R244, R245, R246, R247, R248, R317, R318, R323, R324, R325, R326, R327, R328, R329, R330, R331, R332, R333, R334, R360, R603, R604, R605, R606, R607, R608, R609, R610: R; R_0603_1608Metric
R213, R214, R215, R216, R217, R218, R219, R220, R221, R222, R223, R224, R249, R250, R251, R252, R253, R254, R255, R256, R257, R258, R259, R260, R275, R276, R305, R306, R307, R308, R309, R310, R335, R336, R337, R338, R339, R340, R341, R342, R343, R344, R345, R346, R372: 20kΩ; R_0603_1608Metric
R225, R226, R227, R228, R229, R230, R231, R232, R233, R234, R235, R236, R261, R262, R263, R264, R265, R266, R267, R268, R269, R270, R271, R272, R277, R278, R311, R312, R313, R314, R315, R316, R347, R348, R349, R350, R351, R352, R353, R354, R355, R356, R357, R358, R373: 340kΩ; R_0603_1608Metric
R273, R274: 66; R_0603_1608Metric
R301, R303, R319, R321: 330; R_0603_1608Metric
R302, R304, R320, R322: 680; R_0603_1608Metric
R359: 5kΩ; R_0603_1608Metric
R361, R505: 240; R_0603_1608Metric
R362, R363: 7.5k; R_0603_1608Metric
R364: 31.1k; R_0603_1608Metric
R365, R366: 10k; R_0603_1608Metric
R367: 11.5k; R_0603_1608Metric
R368: 100k; R_0603_1608Metric
R369, R611, R612, R613, R614, R615, R616, R617, R619: 50k; R_0603_1608Metric
R370: 18.2k; R_0603_1608Metric
R371: 4.7k; R_0603_1608Metric
R501: 47k; R_0603_1608Metric
R502: 89; R_0603_1608Metric
R503, R504: 47; R_0603_1608Metric
R601, R602: 15k; R_0603_1608Metric
R618, R620: 270k; R_0603_1608Metric
S601: Config; SW_DIP_x8_Slide
U201, U202, U203, U204, U205, U206, U301, U302, U303, U304, U305: CMP401; SOIC-16_3.9x9.9mm_Pitch1.27mm
U207: MAX9107; SOT-23-8
U306, U307: AOZ3010PI; SOIC-8-1EP_3.9x4.9mm_Pitch1.27mm
U308: RT8288A; SOIC-8-1EP_3.9x4.9mm_Pitch1.27mm
U309: SC189; SOT-23-5
U401: XC7A75T-CSG324; CSG324
U501: IS43TR16128B; BGA-96_2x3x16_9.0x13.0mm_Pitch0.8mm
U601: MAX3033E; TSSOP-16_4.4x5mm_Pitch0.65mm
U602: USB3340; QFN-32-1EP_5x5mm_Pitch0.5mm

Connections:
+1V0: C314.1, L304.2, R371.1, U401.F8, U401.F10, U401.G7, U401.G9, U401.G11, U401.H8, U401.J7, U401.J11, U401.K8, U401.L7, U401.L11, U401.M8, U401.M10, U401.N7, U401.N9, U401.N11
+1V5: C308.1, C316.1, C319.1, C322.1, C325.1, C501.1, L302.2, R309.1, R310.1, R366.1, R503.1, U401.A7, U401.C3, U401.D6, U401.F2, U401.G5, U401.J1, U501.A1, U501.A8, U501.B2, U501.C1, U501.C9, U501.D2, U501.D9, U501.E9, U501.F1, U501.G7, U501.H2, U501.H9, U501.K2, U501.K8, U501.N1, U501.N9, U501.R1, U501.R9
+1V5_ref: R213.2, R214.2, R215.2, R216.2, R217.2, R218.2, R219.1, R220.2, R221.2, R222.2, R223.2, R224.2, R249.2, R250.2, R251.2, R252.2, R253.2, R254.2, R255.2, R256.2, R257.2, R258.2, R259.2, R260.2, R275.1, R276.1, R305.1, R306.1, R307.1, R308.1, R335.2, R336.2, R337.2, R338.2, R339.2, R340.2, R341.2, R342.2, R343.2, R344.2, R345.2, R346.2, R359.1, R372.2
+1V8: C313.1, L303.2, U309.4, U401.F12, U401.H12, U401.K12, U401.M12
+3V3: C307.1, C315.1, C318.1, C321.1, C324.1, D301.2, L301.2, R364.1, R603.1, R604.1, R605.1, R606.1, R607.1, R608.1, R609.1, R610.1, R611.1, R612.1, R613.1, R614.1, R615.1, R616.1, R617.1, R619.1, U201.3, U202.3, U203.3, U204.3, U205.3, U206.3, U301.3, U302.3, U303.3, U304.3, U305.3, U401.A17, U401.B10, U401.C13, U401.D16, U401.G15, U401.H18, U401.K4, U401.K14, U401.L17, U401.N3, U401.N13, U401.P6, U401.P8, U401.P16, U401.R9, U401.T2, U401.T12, U401.U5, U401.U15, U401.V8, U401.V18, U601.4, U601.12
+5V: B101.AA2, B101.BA2, B101.BV1, C301.2, C302.2, C309.2, C310.2, C317.1, C320.1, C323.1, C326.1, R301.1, R303.1, R319.1, R321.1, R368.2, U201.4, U202.4, U203.4, U204.4, U205.4, U206.4, U207.8, U301.4, U302.4, U303.4, U304.4, U305.4, U306.2, U306.6, U307.2, U307.6, U308.1, U309.1, U309.3
+12V: B101.AD2, B101.BD2
/Address/Data/BBS7: B101.AP2, Q212.6, U304.10
/Address/Data/BWTBT: B101.AK2, Q212.3, U303.12
/Address/Data/RDAL0: R225.2, U305.2
/Address/Data/RDAL1: R226.2, U305.1
/Address/Data/RDAL2: R227.2, U202.16
/Address/Data/RDAL3: R228.2, U203.15
/Address/Data/RDAL4: R229.2, U203.2
/Address/Data/RDAL5: R230.2, U203.1
/Address/Data/RDAL6: R231.2, U203.16
/Address/Data/RDAL7: R232.2, U204.15
/Address/Data/RDAL8: R233.2, U204.2
/Address/Data/RDAL9: R234.2, U204.1
/Address/Data/RDAL11: R236.2, U205.2
/Address/Data/RDAL12: R261.2, U206.15
/Address/Data/RDAL13: R262.1, U206.16
/Address/Data/RDAL14: R263.2, U206.2
/Address/Data/RDAL15: R264.2, U206.1
/Address/Data/RDAL16: R265.2, U301.2
/Address/Data/RDAL17: R266.2, U301.1
/Address/Data/RDAL18: R267.2, U201.16
/Address/Data/RDAL19: R268.2, U202.15
/Address/Data/RDAL20: R269.2, U202.2
/Address/Data/RDAL21: R270.2, U202.1
/BDAL0: B101.AU2, Q201.6, U305.5
/BDAL1: B101.AV2, Q201.3, U305.7
/BDAL2: B101.BE2, Q202.6, U202.10
/BDAL3: B101.BF2, Q202.3, U203.12
/BDAL4: B101.BH2, Q203.6, U203.5
/BDAL5: B101.BJ2, Q203.3, U203.7
/BDAL6: B101.BK2, Q204.6, U203.10
/BDAL7: B101.BL2, Q204.3, U204.12
/BDAL8: B101.BM2, Q205.6, U204.5
/BDAL9: B101.BN2, Q205.3, U204.7
/BDAL10: B101.BP2, Q206.6, U205.12
/BDAL11: B101.BR2, Q206.3, U205.5
/BDAL12: B101.BS2, Q207.6, U206.12
/BDAL13: B101.BT2, Q207.3, U206.10
/BDAL14: B101.BU2, Q208.6, U206.5
/BDAL15: B101.BV2, Q208.3, U206.7
/BDAL16: B101.AC1, Q209.6, U301.5
/BDAL17: B101.AD1, Q209.3, U301.7
/BDAL18: B101.BC1, Q210.6, U201.10
/BDAL19: B101.BD1, Q210.3, U202.12
/BDAL20: B101.BE1, Q211.6, U202.5
/BDAL21: B101.BF1, Q211.3, U202.7
/Bus Control/BDCOK: B101.BA1, U201.7
/Bus Control/BDIN: B101.AH2, Q302.3, U305.10
/Bus Control/BDMGI: B101.AR2, R303.2, R304.1, U304.7
/Bus Control/BDMGO: B101.AS2, Q301.3, R321.2, R322.1
/Bus Control/BDMR: B101.AN1, Q305.6, U301.12
/Bus Control/BDOUT: B101.AE2, Q303.6, U305.12
/Bus Control/BEVNT: B101.BR1, U205.7
/Bus Control/BHALT: B101.AP1, U304.12
/Bus Control/BIAKI: B101.AM2, R301.2, R302.1, U303.7
/Bus Control/BIAKO: B101.AN2, Q301.6, R319.2, R320.1
/Bus Control/BINIT: B101.AT2, Q304.3, U301.10
/Bus Control/BIRQ4: B101.AL2, Q306.6, U304.5
/Bus Control/BIRQ5: B101.AA1, Q213.4, Q306.3, U207.6, U303.5
/Bus Control/BIRQ6: B101.AB1, Q213.5, Q307.6, U207.2, U303.10
/Bus Control/BIRQ7: B101.BP1, Q307.3, Q308.6, U205.10
/Bus Control/BPOK: B101.BB1, U201.5
/Bus Control/BREF: B101.AR1, Q304.6, U302.5
/Bus Control/BRPLY: B101.AF2, Q303.3, U204.10
/Bus Control/BSACK: B101.BN1, Q305.3, U201.12
/Bus Control/BSYNC: B101.AJ2, Q302.6, U302.10
/I/O/IPblank_N: P2.7, U601.13
/I/O/IPblank_P: P2.6, U601.14
/I/O/IPclk_N: P2.10, U601.3
/I/O/IPclk_P: P2.9, U601.2
/I/O/IPdata_N: P2.2, U601.5
/I/O/IPdata_P: P2.1, U601.6
/I/O/IPlatch_N: P2.5, U601.11
/I/O/IPlatch_P: P2.4, U601.10
/I/O/USB_D+: J601.3, R602.1
/I/O/USB_D-: J601.2, R601.1
/Memory/A0: U401.C5, U501.N3
/Memory/A1: U401.B6, U501.P7
/Memory/A2: U401.C7, U501.P3
/Memory/A3: U401.D5, U501.N2
/Memory/A4: U401.A3, U501.P8
/Memory/A5: U401.E7, U501.P2
/Memory/A6: U401.A4, U501.R8
/Memory/A7: U401.C6, U501.R2
/Memory/A8: U401.A6, U501.T8
/Memory/A9: U401.D8, U501.R3
/Memory/A10: U401.B2, U501.L7
/Memory/A11: U401.A5, U501.R7
/Memory/A12: U401.B3, U501.N7
/Memory/A13: U401.B7, U501.T3
/Memory/BA0: U401.E5, U501.M2
/Memory/BA1: U401.A1, U501.N8
/Memory/BA2: U401.E6, U501.M3
/Memory/CAS#: U401.D3, U501.K3
/Memory/CK: R502.2, U401.C4, U501.J7
/Memory/CK#: R502.1, U401.B4, U501.K7
/Memory/CKE: U401.B1, U501.K9
/Memory/DML: U401.G1, U501.E7
/Memory/DMU: U401.G6, U501.D3
/Memory/DQL0: U401.H1, U501.E3
/Memory/DQL1: U401.F1, U501.F7
/Memory/DQL2: U401.E2, U501.F2
/Memory/DQL3: U401.E1, U501.F8
/Memory/DQL4: U401.F4, U501.H3
/Memory/DQL5: U401.C1, U501.H8
/Memory/DQL6: U401.F3, U501.G2
/Memory/DQL7: U401.D2, U501.H7
/Memory/DQSL: U401.H2, U501.F3
/Memory/DQSL#: U401.G2, U501.G3
/Memory/DQSU: U401.J4, U501.C7
/Memory/DQSU#: U401.H4, U501.B7
/Memory/DQU0: U401.G4, U501.D7
/Memory/DQU1: U401.H5, U501.C3
/Memory/DQU2: U401.G3, U501.C8
/Memory/DQU3: U401.H6, U501.C2
/Memory/DQU4: U401.J2, U501.A7
/Memory/DQU5: U401.J3, U501.A2
/Memory/DQU6: U401.K1, U501.B8
/Memory/DQU7: U401.K2, U501.A3
/Memory/ODT: U401.F5, U501.K1
/Memory/RAS#: U401.E3, U501.J3
/Memory/RESET#: R501.1, U401.J5, U501.T2
/Memory/VREF15: C501.2, C502.1, R503.2, R504.1, U401.D7, U401.F6, U501.H1, U501.M8
/Memory/WE#: U401.D4, U501.L3
/RBS7: R271.2, U304.16
/RDCOK: R312.1, U201.1
/RDIN: R348.2, U305.16
/RDMGI: R316.1, U304.1
/RDMR: R353.2, U301.15
/RDOUT: R349.2, U305.15
/REVNT: R313.1, U205.1
/RHALT: R314.1, U304.15
/RIAKI: R315.1, U303.1
/RINIT: R352.2, U301.16
/RIRQ4: R355.1, U304.2
/RIRQ5: Q214.4, R356.1, U303.2
/RIRQ6: Q214.5, R357.1, U303.16
/RIRQ7: R358.1, R373.1, U205.16
/RPOK: R311.1, U201.2
/RREF: R351.2, U302.2
/RRPLY: R350.2, U204.16
/RSACK: R354.2, U201.15
/RSYNC: R347.2, U302.16
/RWTBT: R272.2, U303.15
/TIRQ5: R273.2, R332.2
/TIRQ6: R274.2, R333.2
/TIRQ7: R334.2, R360.2
GND: B101.AC2, B101.AJ1, B101.AM1, B101.AT1, B101.BC2, B101.BJ1, B101.BT1, C301.1, C302.1, C303.2, C304.2, C305.2, C306.2, C307.2, C308.2, C309.1, C310.1, C312.2, C313.2, C314.2, C315.2, C316.2, C317.2, C318.2, C319.2, C320.2, C321.2, C322.2, C323.2, C324.2, C325.2, C326.2, C502.2, J601.4, J601.5, P2.3, P2.8, Q201.1, Q201.4, Q202.1, Q202.4, Q203.1, Q203.4, Q204.1, Q204.4, Q205.1, Q205.4, Q206.1, Q206.4, Q207.1, Q207.4, Q208.1, Q208.4, Q209.1, Q209.4, Q210.1, Q210.4, Q211.1, Q211.4, Q212.1, Q212.4, Q213.2, Q214.2, Q301.1, Q301.4, Q302.1, Q302.4, Q303.1, Q303.4, Q304.1, Q304.4, Q305.1, Q305.4, Q306.1, Q306.4, Q307.1, Q307.4, Q308.1, R302.2, R304.2, R320.2, R322.2, R359.2, R365.2, R367.2, R370.2, R501.2, R504.2, R505.2, R601.2, R602.2, R618.2, R620.2, S601.9, S601.10, S601.11, S601.12, S601.13, S601.14, S601.15, S601.16, U201.13, U201.14, U202.13, U202.14, U203.13, U203.14, U204.13, U204.14, U205.13, U205.14, U206.13, U206.14, U207.4, U301.13, U301.14, U302.13, U302.14, U303.13, U303.14, U304.13, U304.14, U305.13, U305.14, U306.1, U306.3, U307.1, U307.3, U308.8, U308.9, U309.2, U401.A2, U401.A12, U401.B5, U401.B15, U401.C8, U401.C18, U401.D1, U401.D11, U401.E4, U401.E14, U401.F7, U401.F9, U401.F11, U401.F17, U401.G8, U401.G10, U401.G12, U401.H3, U401.H7, U401.H9, U401.H11, U401.H13, U401.J6, U401.J8, U401.J9, U401.J12, U401.J16, U401.K7, U401.K10, U401.K11, U401.L2, U401.L8, U401.L12, U401.M5, U401.M7, U401.M9, U401.M11, U401.M15, U401.N8, U401.N10, U401.N12, U401.N18, U401.P1, U401.R4, U401.R14, U401.T7, U401.T17, U401.U10, U401.V3, U401.V13, U501.A9, U501.B1, U501.B3, U501.B9, U501.D1, U501.D8, U501.E1, U501.E2, U501.E8, U501.F9, U501.G1, U501.G8, U501.G9, U501.J2, U501.J8, U501.M1, U501.M9, U501.P1, U501.P9, U501.T1, U501.T9
unnamed: C303.1, R362.2
unnamed: C304.1, R363.2
unnamed: C305.1, U306.7
unnamed: C306.1, U307.7
unnamed: C311.1, U308.4
unnamed: C311.2, L304.1, U308.2, U308.3
unnamed: C312.1, U308.7
unnamed: D301.1, R361.1
unnamed: D601.2, R603.2
unnamed: D602.2, R604.2
unnamed: D603.2, R605.2
unnamed: D604.2, R606.2
unnamed: D605.2, R607.2
unnamed: D606.2, R608.2
unnamed: D607.2, R609.2
unnamed: D608.2, R610.2
unnamed: L301.1, U306.8, U306.9
unnamed: L302.1, U307.8, U307.9
unnamed: L303.1, U309.5
unnamed: Q201.2, R201.1
unnamed: Q201.5, R202.2
unnamed: Q202.2, R203.1
unnamed: Q202.5, R204.1
unnamed: Q203.2, R205.1
unnamed: Q203.5, R206.1
unnamed: Q204.2, R207.1
unnamed: Q204.5, R208.1
unnamed: Q205.2, R209.1
unnamed: Q205.5, R210.1
unnamed: Q206.2, R211.1
unnamed: Q206.5, R212.1
unnamed: Q207.2, R237.1
unnamed: Q207.5, R238.1
unnamed: Q208.2, R239.1
unnamed: Q208.5, R240.1
unnamed: Q209.2, R241.1
unnamed: Q209.5, R242.1
unnamed: Q210.2, R243.1
unnamed: Q210.5, R244.1
unnamed: Q211.2, R245.1
unnamed: Q211.5, R246.1
unnamed: Q212.2, R247.1
unnamed: Q212.5, R248.1
unnamed: Q213.1, R274.1
unnamed: Q213.3, R273.1
unnamed: Q214.1, R278.1, U207.1
unnamed: Q214.3, R277.1, U207.7
unnamed: Q301.2, R317.1
unnamed: Q301.5, R318.1
unnamed: Q302.2, R323.1
unnamed: Q302.5, R324.1
unnamed: Q303.2, R325.1
unnamed: Q303.5, R326.1
unnamed: Q304.2, R327.1
unnamed: Q304.5, R328.1
unnamed: Q305.2, R329.1
unnamed: Q305.5, R330.1
unnamed: Q306.2, R331.1
unnamed: Q306.5, R332.1
unnamed: Q307.2, R333.1
unnamed: Q307.5, R360.1
unnamed: Q308.2, R334.1
unnamed: R213.1, R225.1, U305.6
unnamed: R214.1, R226.1, U305.8
unnamed: R215.1, R227.1, U202.9
unnamed: R216.1, R228.1, U203.11
unnamed: R217.1, R229.1, U203.6
unnamed: R218.1, R230.1, U203.8
unnamed: R219.2, R231.1, U203.9
unnamed: R220.1, R232.1, U204.11
unnamed: R221.1, R233.1, U204.6
unnamed: R222.1, R234.1, U204.8
unnamed: R223.1, R235.1, U205.11
unnamed: R224.1, R236.1, U205.6
unnamed: R249.1, R261.1, U206.11
unnamed: R250.1, R262.2, U206.9
unnamed: R251.1, R263.1, U206.6
unnamed: R252.1, R264.1, U206.8
unnamed: R253.1, R265.1, U301.6
unnamed: R254.1, R266.1, U301.8
unnamed: R255.1, R267.1, U201.9
unnamed: R256.1, R268.1, U202.11
unnamed: R257.1, R269.1, U202.6
unnamed: R258.1, R270.1, U202.8
unnamed: R259.1, R271.1, U304.9
unnamed: R260.1, R272.1, U303.11
unnamed: R275.2, R277.2, U207.5
unnamed: R276.2, R278.2, U207.3
unnamed: R305.2, R311.2, U201.6
unnamed: R306.2, R312.2, U201.8
unnamed: R307.2, R313.2, U205.8
unnamed: R308.2, R314.2, U304.11
unnamed: R309.2, R315.2, U303.8
unnamed: R310.2, R316.2, U304.8
unnamed: R335.1, R347.1, U302.9
unnamed: R336.1, R348.1, U305.9
unnamed: R337.1, R349.1, U305.11
unnamed: R338.1, R350.1, U204.9
unnamed: R339.1, R351.1, U302.6
unnamed: R340.1, R352.1, U301.9
unnamed: R341.1, R353.1, U301.11
unnamed: R342.1, R354.1, U201.11
unnamed: R343.1, R355.2, U304.6
unnamed: R344.1, R356.2, U303.6
unnamed: R345.1, R357.2, U303.9
unnamed: R346.1, R358.2, U205.9
unnamed: R361.2, U401.P10
unnamed: R362.1, U306.5
unnamed: R363.1, U307.5
unnamed: R364.2, R365.1, U306.4
unnamed: R366.2, R367.1, U307.4
unnamed: R368.1, U308.5
unnamed: R369.1, R370.1, R371.2
unnamed: R369.2, U308.6
unnamed: R372.1, R373.2
unnamed: R505.1, U501.L8

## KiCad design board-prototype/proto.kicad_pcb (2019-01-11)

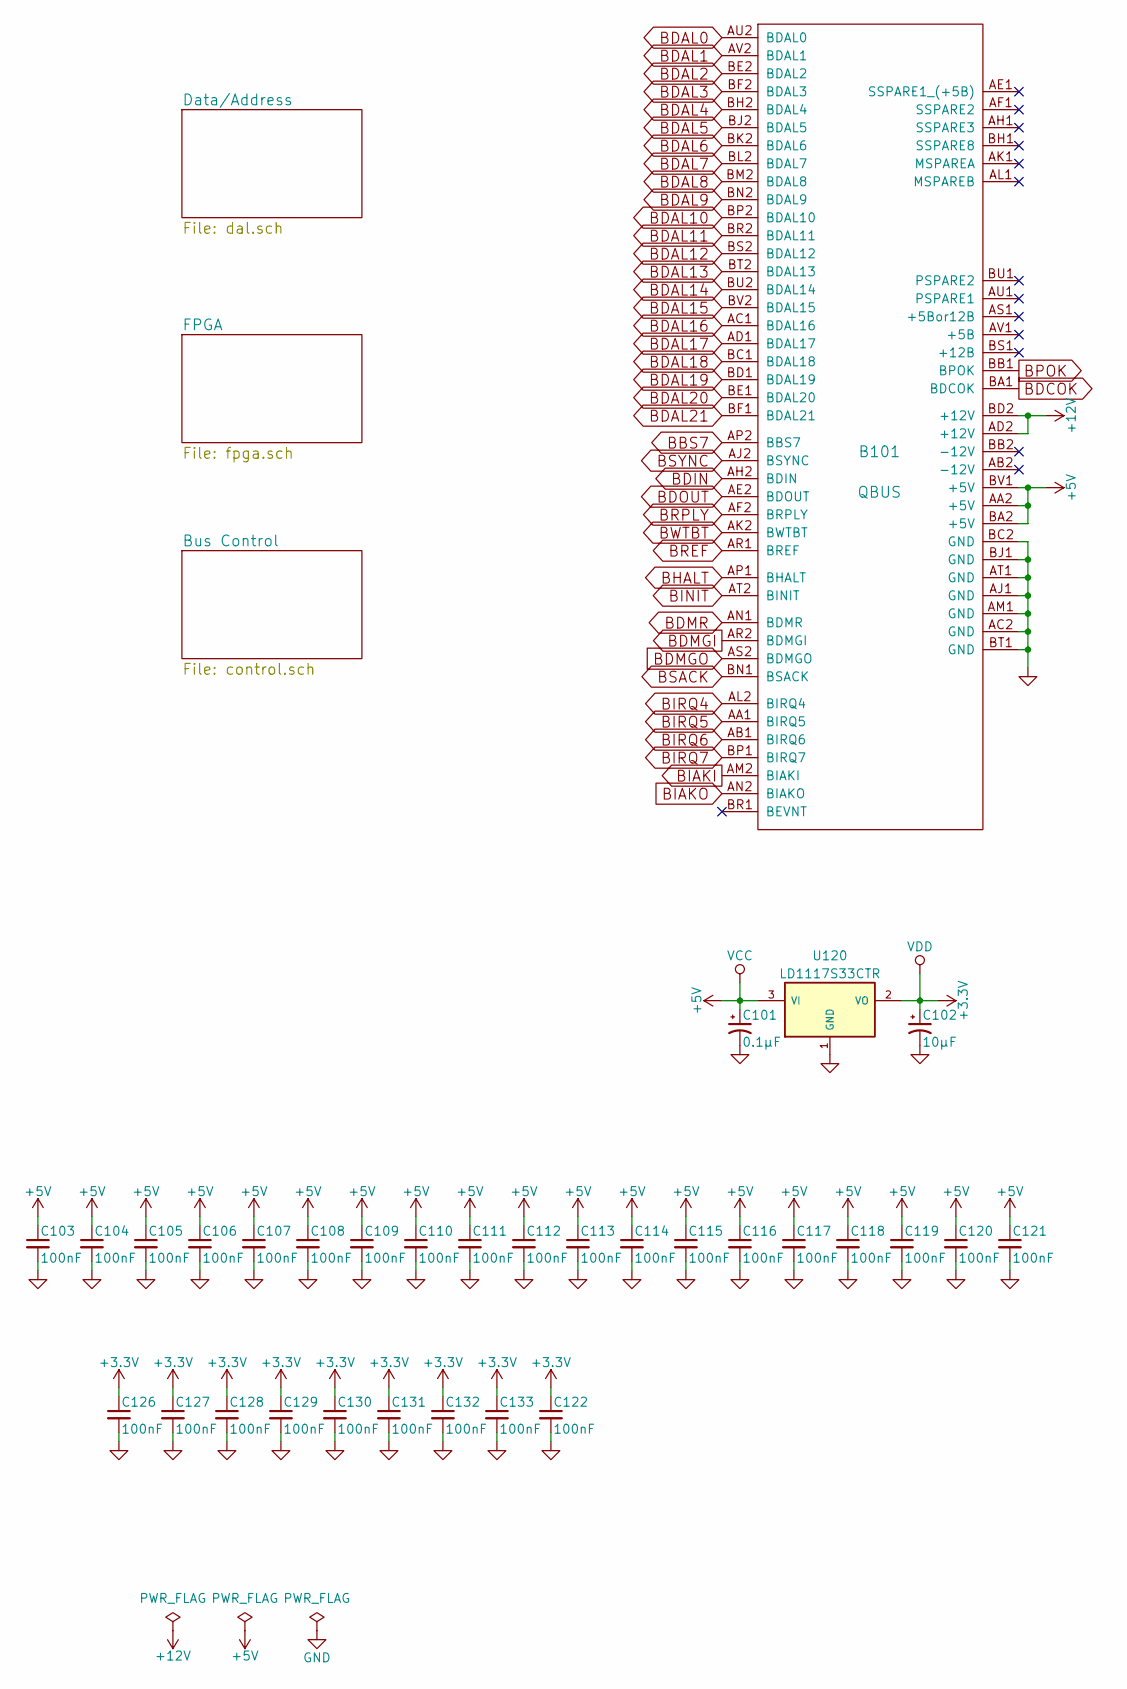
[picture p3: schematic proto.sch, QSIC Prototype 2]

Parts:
B101: QBUS; Qbus-double
C101: 0.1µF; TantalC_SizeR_EIA-2012
C102: 10µF; TantalC_SizeR_EIA-2012
C103, C104, C105, C106, C107, C108, C109, C110, C111, C112, C113, C114, C115, C116, C117, C118, C119, C120, C121, C122, C126, C127, C128, C129, C130, C131, C132, C133: 100nF; C_0805
U120: LD1117S33CTR; SOT-223

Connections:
+5V: B101.AA2 (+5V), B101.BA2 (+5V), B101.BV1 (+5V), C101.1, C103.1, C104.1, C105.1, C106.1, C107.1, C108.1, C109.1, C110.1, C111.1, C112.1, C113.1, C114.1, C115.1, C116.1, C117.1, C118.1, C119.1, C120.1, C121.1, U120.3 (VI); also elsewhere on the board
+12V: B101.AD2 (+12V), B101.BD2 (+12V); also elsewhere on the board
BBS7: B101.AP2 (BBS7); also elsewhere on the board
BDAL0: B101.AU2 (BDAL0); also elsewhere on the board
BDAL1: B101.AV2 (BDAL1); also elsewhere on the board
BDAL2: B101.BE2 (BDAL2); also elsewhere on the board
BDAL3: B101.BF2 (BDAL3); also elsewhere on the board
BDAL4: B101.BH2 (BDAL4); also elsewhere on the board
BDAL5: B101.BJ2 (BDAL5); also elsewhere on the board
BDAL6: B101.BK2 (BDAL6); also elsewhere on the board
BDAL7: B101.BL2 (BDAL7); also elsewhere on the board
BDAL8: B101.BM2 (BDAL8); also elsewhere on the board
BDAL9: B101.BN2 (BDAL9); also elsewhere on the board
BDAL10: B101.BP2 (BDAL10); also elsewhere on the board
BDAL11: B101.BR2 (BDAL11); also elsewhere on the board
BDAL12: B101.BS2 (BDAL12); also elsewhere on the board
BDAL13: B101.BT2 (BDAL13); also elsewhere on the board
BDAL14: B101.BU2 (BDAL14); also elsewhere on the board
BDAL15: B101.BV2 (BDAL15); also elsewhere on the board
BDAL16: B101.AC1 (BDAL16); also elsewhere on the board
BDAL17: B101.AD1 (BDAL17); also elsewhere on the board
BDAL18: B101.BC1 (BDAL18); also elsewhere on the board
BDAL19: B101.BD1 (BDAL19); also elsewhere on the board
BDAL20: B101.BE1 (BDAL20); also elsewhere on the board
BDAL21: B101.BF1 (BDAL21); also elsewhere on the board
BDCOK: B101.BA1 (BDCOK); also elsewhere on the board
BDIN: B101.AH2 (BDIN); also elsewhere on the board
BDMGI: B101.AR2 (BDMGI); also elsewhere on the board
BDMGO: B101.AS2 (BDMGO); also elsewhere on the board
BDMR: B101.AN1 (BDMR); also elsewhere on the board
BDOUT: B101.AE2 (BDOUT); also elsewhere on the board
BHALT: B101.AP1 (BHALT); also elsewhere on the board
BIAKI: B101.AM2 (BIAKI); also elsewhere on the board
BIAKO: B101.AN2 (BIAKO); also elsewhere on the board
BINIT: B101.AT2 (BINIT); also elsewhere on the board
BIRQ4: B101.AL2 (BIRQ4); also elsewhere on the board
BIRQ5: B101.AA1 (BIRQ5); also elsewhere on the board
BIRQ6: B101.AB1 (BIRQ6); also elsewhere on the board
BIRQ7: B101.BP1 (BIRQ7); also elsewhere on the board
BPOK: B101.BB1 (BPOK); also elsewhere on the board
BREF: B101.AR1 (BREF); also elsewhere on the board
BRPLY: B101.AF2 (BRPLY); also elsewhere on the board
BSACK: B101.BN1 (BSACK); also elsewhere on the board
BSYNC: B101.AJ2 (BSYNC); also elsewhere on the board
BWTBT: B101.AK2 (BWTBT); also elsewhere on the board

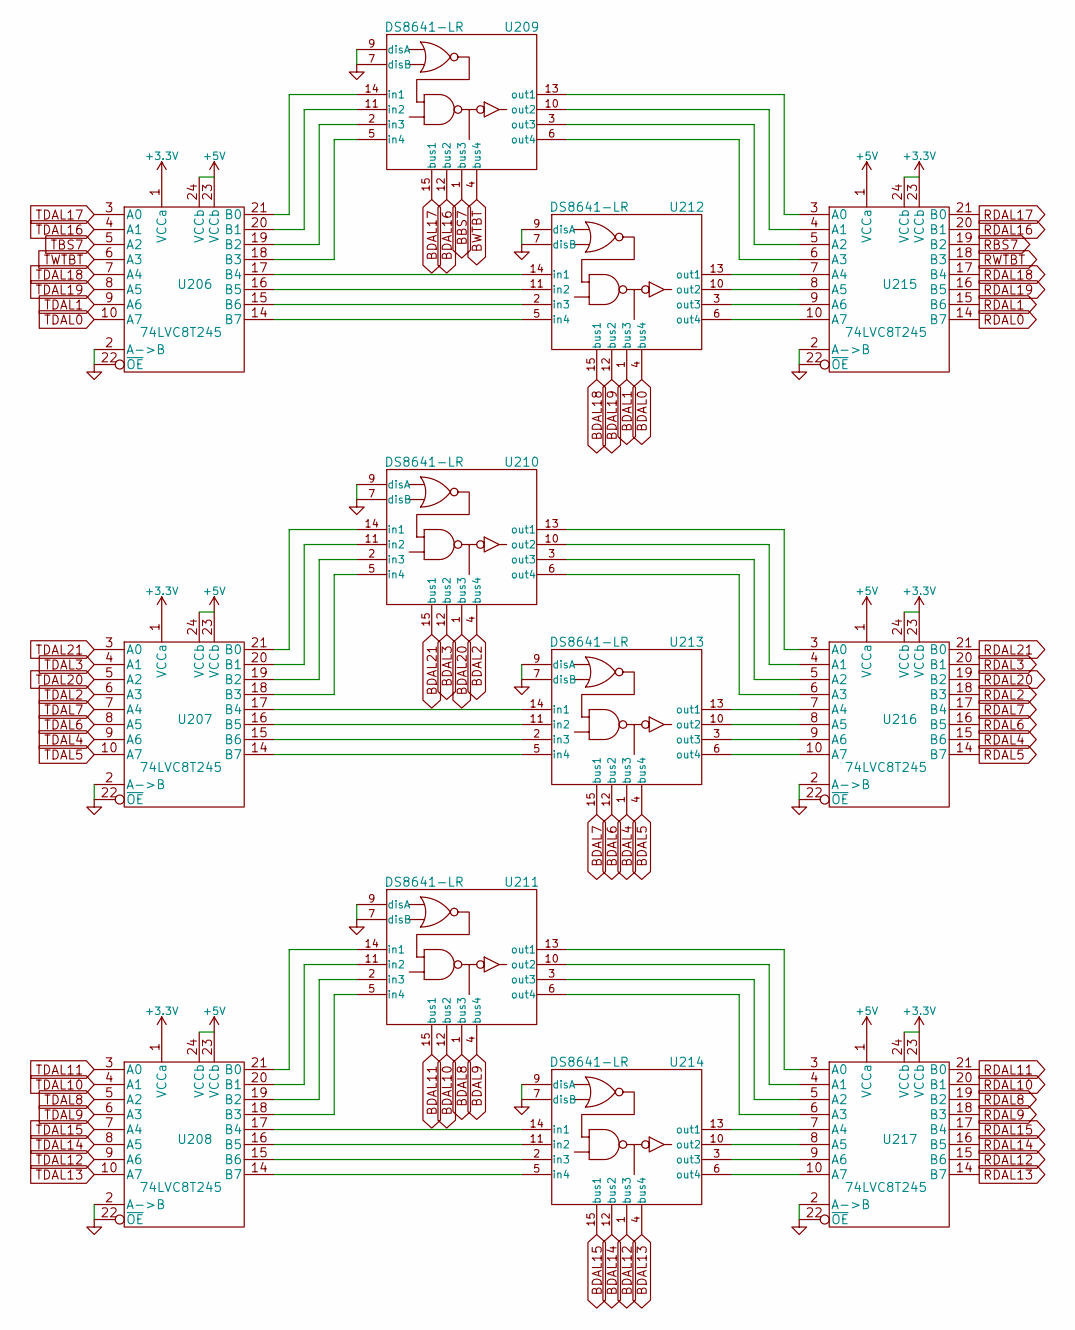
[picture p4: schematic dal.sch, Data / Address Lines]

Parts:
U206, U207, U208, U215, U216, U217: 74LVC8T245; TSSOP-24_4.4x7.8mm_Pitch0.65mm
U209, U210, U211, U212, U213, U214: DS8641-LR; DIP-16__300

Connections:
+5V: U206.23 (VCCb), U206.24 (VCCb), U207.23 (VCCb), U207.24 (VCCb), U208.23 (VCCb), U208.24 (VCCb), U209.16 (VCC), U210.16 (VCC), U211.16 (VCC), U212.16 (VCC), U213.16 (VCC), U214.16 (VCC), U215.1 (VCCa), U216.1 (VCCa), U217.1 (VCCa); also elsewhere on the board
BBS7: U209.1 (bus3); also elsewhere on the board
BDAL0: U212.4 (bus4); also elsewhere on the board
BDAL1: U212.1 (bus3); also elsewhere on the board
BDAL2: U210.4 (bus4); also elsewhere on the board
BDAL3: U210.12 (bus2); also elsewhere on the board
BDAL4: U213.1 (bus3); also elsewhere on the board
BDAL5: U213.4 (bus4); also elsewhere on the board
BDAL6: U213.12 (bus2); also elsewhere on the board
BDAL7: U213.15 (bus1); also elsewhere on the board
BDAL8: U211.1 (bus3); also elsewhere on the board
BDAL9: U211.4 (bus4); also elsewhere on the board
BDAL10: U211.12 (bus2); also elsewhere on the board
BDAL11: U211.15 (bus1); also elsewhere on the board
BDAL12: U214.1 (bus3); also elsewhere on the board
BDAL13: U214.4 (bus4); also elsewhere on the board
BDAL14: U214.12 (bus2); also elsewhere on the board
BDAL15: U214.15 (bus1); also elsewhere on the board
BDAL16: U209.12 (bus2); also elsewhere on the board
BDAL17: U209.15 (bus1); also elsewhere on the board
BDAL18: U212.15 (bus1); also elsewhere on the board
BDAL19: U212.12 (bus2); also elsewhere on the board
BDAL20: U210.1 (bus3); also elsewhere on the board
BDAL21: U210.15 (bus1); also elsewhere on the board
BWTBT: U209.4 (bus4); also elsewhere on the board
unnamed: U206.14 (B7), U212.5 (in4)
unnamed: U206.15 (B6), U212.2 (in3)
unnamed: U206.16 (B5), U212.11 (in2)
unnamed: U206.17 (B4), U212.14 (in1)
unnamed: U206.18 (B3), U209.5 (in4)
unnamed: U206.19 (B2), U209.2 (in3)
unnamed: U206.20 (B1), U209.11 (in2)
unnamed: U206.21 (B0), U209.14 (in1)
unnamed: U207.14 (B7), U213.5 (in4)
unnamed: U207.15 (B6), U213.2 (in3)
unnamed: U207.16 (B5), U213.11 (in2)
unnamed: U207.17 (B4), U213.14 (in1)
unnamed: U207.18 (B3), U210.5 (in4)
unnamed: U207.19 (B2), U210.2 (in3)
unnamed: U207.20 (B1), U210.11 (in2)
unnamed: U207.21 (B0), U210.14 (in1)
unnamed: U208.14 (B7), U214.5 (in4)
unnamed: U208.15 (B6), U214.2 (in3)
unnamed: U208.16 (B5), U214.11 (in2)
unnamed: U208.17 (B4), U214.14 (in1)
unnamed: U208.18 (B3), U211.5 (in4)
unnamed: U208.19 (B2), U211.2 (in3)
unnamed: U208.20 (B1), U211.11 (in2)
unnamed: U208.21 (B0), U211.14 (in1)
unnamed: U209.3 (out3), U215.5 (A2)
unnamed: U209.6 (out4), U215.6 (A3)
unnamed: U209.10 (out2), U215.4 (A1)
unnamed: U209.13 (out1), U215.3 (A0)
unnamed: U210.3 (out3), U216.5 (A2)
unnamed: U210.6 (out4), U216.6 (A3)
unnamed: U210.10 (out2), U216.4 (A1)
unnamed: U210.13 (out1), U216.3 (A0)
unnamed: U211.3 (out3), U217.5 (A2)
unnamed: U211.6 (out4), U217.6 (A3)
unnamed: U211.10 (out2), U217.4 (A1)
unnamed: U211.13 (out1), U217.3 (A0)
unnamed: U212.3 (out3), U215.9 (A6)
unnamed: U212.6 (out4), U215.10 (A7)
unnamed: U212.10 (out2), U215.8 (A5)
unnamed: U212.13 (out1), U215.7 (A4)
unnamed: U213.3 (out3), U216.9 (A6)
unnamed: U213.6 (out4), U216.10 (A7)
unnamed: U213.10 (out2), U216.8 (A5)
unnamed: U213.13 (out1), U216.7 (A4)
unnamed: U214.3 (out3), U217.9 (A6)
unnamed: U214.6 (out4), U217.10 (A7)
unnamed: U214.10 (out2), U217.8 (A5)
unnamed: U214.13 (out1), U217.7 (A4)
RBS7: U215.19 (B2); also elsewhere on the board
RDAL0: U215.14 (B7); also elsewhere on the board
RDAL1: U215.15 (B6); also elsewhere on the board
RDAL2: U216.18 (B3); also elsewhere on the board
RDAL3: U216.20 (B1); also elsewhere on the board
RDAL4: U216.15 (B6); also elsewhere on the board
RDAL5: U216.14 (B7); also elsewhere on the board
RDAL6: U216.16 (B5); also elsewhere on the board
RDAL7: U216.17 (B4); also elsewhere on the board
RDAL8: U217.19 (B2); also elsewhere on the board
RDAL9: U217.18 (B3); also elsewhere on the board
RDAL10: U217.20 (B1); also elsewhere on the board
RDAL11: U217.21 (B0); also elsewhere on the board
RDAL12: U217.15 (B6); also elsewhere on the board
RDAL13: U217.14 (B7); also elsewhere on the board
RDAL14: U217.16 (B5); also elsewhere on the board
RDAL15: U217.17 (B4); also elsewhere on the board
RDAL16: U215.20 (B1); also elsewhere on the board
RDAL17: U215.21 (B0); also elsewhere on the board
RDAL18: U215.17 (B4); also elsewhere on the board
RDAL19: U215.16 (B5); also elsewhere on the board
RDAL20: U216.19 (B2); also elsewhere on the board
RDAL21: U216.21 (B0); also elsewhere on the board
RWTBT: U215.18 (B3); also elsewhere on the board
TBS7: U206.5 (A2); also elsewhere on the board
TDAL0: U206.10 (A7); also elsewhere on the board
TDAL1: U206.9 (A6); also elsewhere on the board
TDAL2: U207.6 (A3); also elsewhere on the board
TDAL3: U207.4 (A1); also elsewhere on the board
TDAL4: U207.9 (A6); also elsewhere on the board
TDAL5: U207.10 (A7); also elsewhere on the board
TDAL6: U207.8 (A5); also elsewhere on the board
TDAL7: U207.7 (A4); also elsewhere on the board
TDAL8: U208.5 (A2); also elsewhere on the board
TDAL9: U208.6 (A3); also elsewhere on the board
TDAL10: U208.4 (A1); also elsewhere on the board
TDAL11: U208.3 (A0); also elsewhere on the board
TDAL12: U208.9 (A6); also elsewhere on the board
TDAL13: U208.10 (A7); also elsewhere on the board
TDAL14: U208.8 (A5); also elsewhere on the board
TDAL15: U208.7 (A4); also elsewhere on the board
TDAL16: U206.4 (A1); also elsewhere on the board
TDAL17: U206.3 (A0); also elsewhere on the board
TDAL18: U206.7 (A4); also elsewhere on the board
TDAL19: U206.8 (A5); also elsewhere on the board
TDAL20: U207.5 (A2); also elsewhere on the board
TDAL21: U207.3 (A0); also elsewhere on the board
TWTBT: U206.6 (A3); also elsewhere on the board

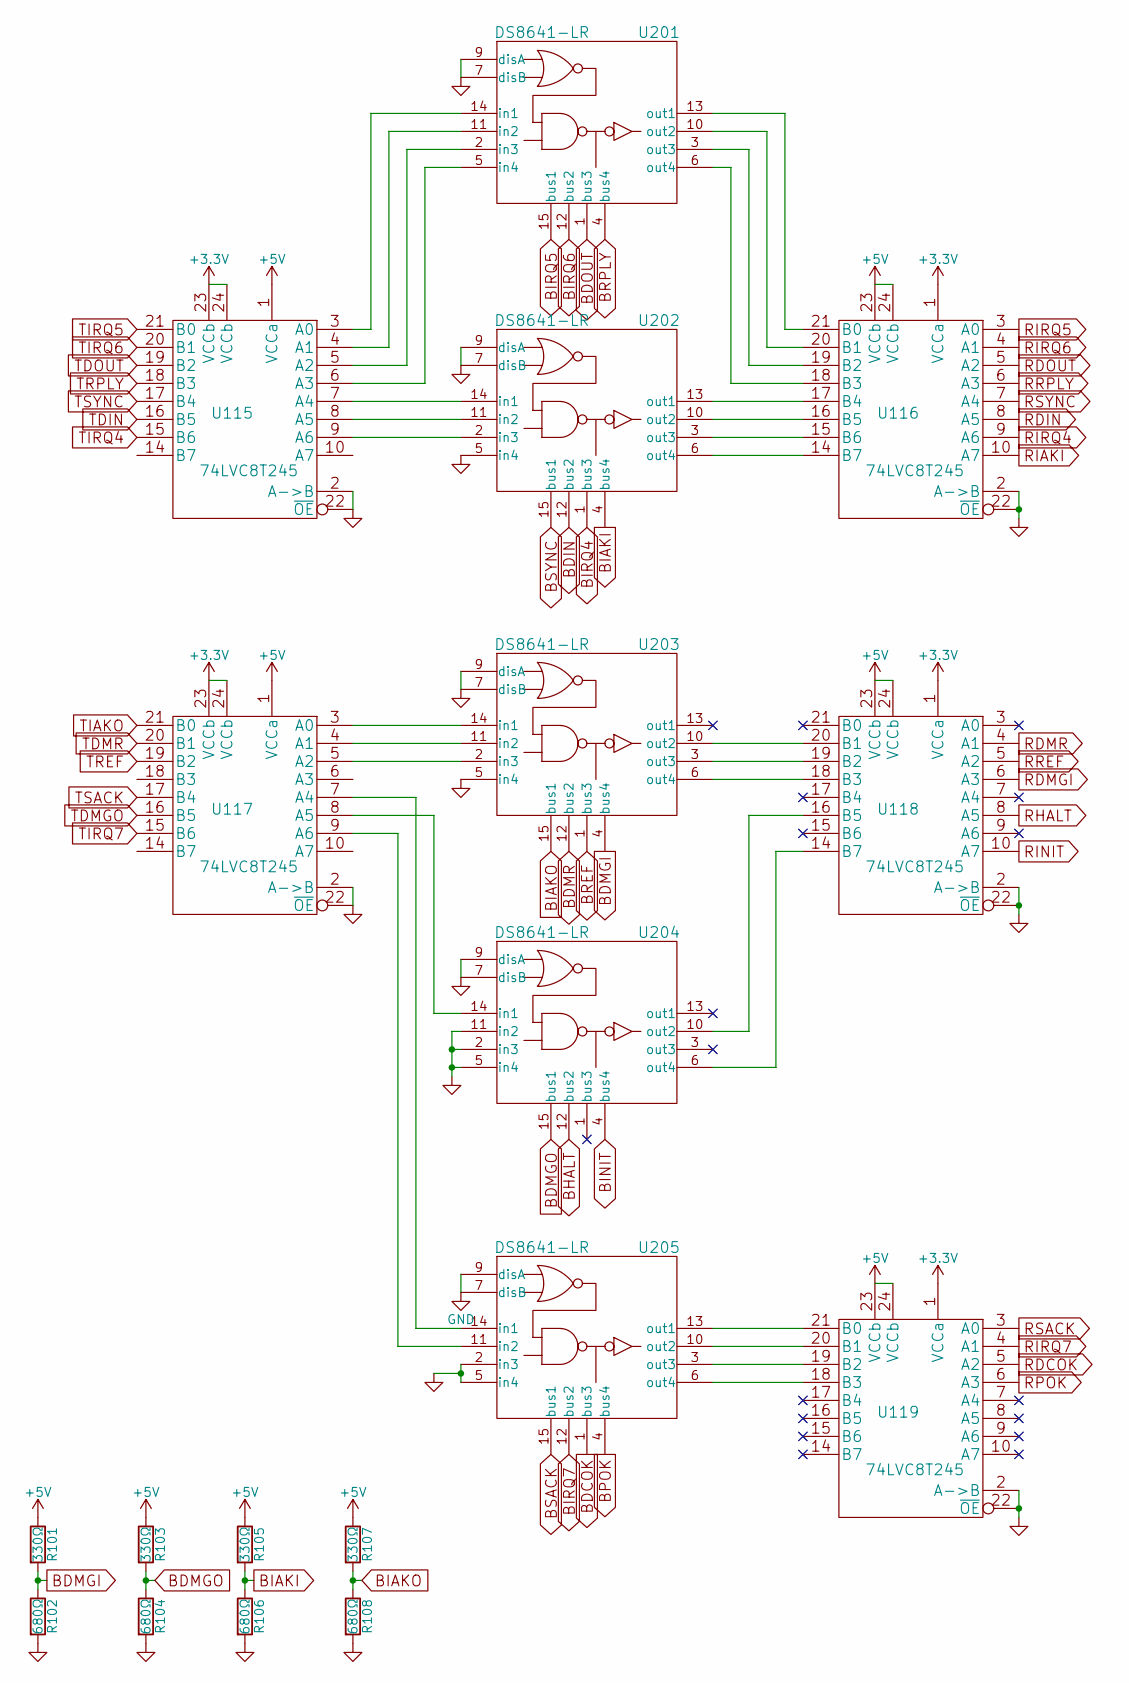
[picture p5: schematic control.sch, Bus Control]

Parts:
R101, R103, R105, R107: 330Ω; R_0805
R102, R104, R106, R108: 680Ω; R_0805
U115, U116, U117, U118, U119: 74LVC8T245; TSSOP-24_4.4x7.8mm_Pitch0.65mm
U201, U202, U203, U204, U205: DS8641-LR; DIP-16__300

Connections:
+5V: R101.1, R103.1, R105.1, R107.1, U115.1 (VCCa), U116.23 (VCCb), U116.24 (VCCb), U117.1 (VCCa), U118.23 (VCCb), U118.24 (VCCb), U119.23 (VCCb), U119.24 (VCCb), U201.16 (VCC), U202.16 (VCC), U203.16 (VCC), U204.16 (VCC), U205.16 (VCC); also elsewhere on the board
BDCOK: U205.1 (bus3); also elsewhere on the board
BDIN: U202.12 (bus2); also elsewhere on the board
BDMGI: R101.2, R102.1, U203.4 (bus4); also elsewhere on the board
BDMGO: R103.2, R104.1, U204.15 (bus1); also elsewhere on the board
BDMR: U203.12 (bus2); also elsewhere on the board
BDOUT: U201.1 (bus3); also elsewhere on the board
BHALT: U204.12 (bus2); also elsewhere on the board
BIAKI: R105.2, R106.1, U202.4 (bus4); also elsewhere on the board
BIAKO: R107.2, R108.1, U203.15 (bus1); also elsewhere on the board
BINIT: U204.4 (bus4); also elsewhere on the board
BIRQ4: U202.1 (bus3); also elsewhere on the board
BIRQ5: U201.15 (bus1); also elsewhere on the board
BIRQ6: U201.12 (bus2); also elsewhere on the board
BIRQ7: U205.12 (bus2); also elsewhere on the board
BPOK: U205.4 (bus4); also elsewhere on the board
BREF: U203.1 (bus3); also elsewhere on the board
BRPLY: U201.4 (bus4); also elsewhere on the board
BSACK: U205.15 (bus1); also elsewhere on the board
BSYNC: U202.15 (bus1); also elsewhere on the board
unnamed: U115.3 (A0), U201.14 (in1)
unnamed: U115.4 (A1), U201.11 (in2)
unnamed: U115.5 (A2), U201.2 (in3)
unnamed: U115.6 (A3), U201.5 (in4)
unnamed: U115.7 (A4), U202.14 (in1)
unnamed: U115.8 (A5), U202.11 (in2)
unnamed: U115.9 (A6), U202.2 (in3)
unnamed: U116.14 (B7), U202.6 (out4)
unnamed: U116.15 (B6), U202.3 (out3)
unnamed: U116.16 (B5), U202.10 (out2)
unnamed: U116.17 (B4), U202.13 (out1)
unnamed: U116.18 (B3), U201.6 (out4)
unnamed: U116.19 (B2), U201.3 (out3)
unnamed: U116.20 (B1), U201.10 (out2)
unnamed: U116.21 (B0), U201.13 (out1)
unnamed: U117.3 (A0), U203.14 (in1)
unnamed: U117.4 (A1), U203.11 (in2)
unnamed: U117.5 (A2), U203.2 (in3)
unnamed: U117.8 (A5), U204.14 (in1)
unnamed: U118.14 (B7), U204.6 (out4)
unnamed: U118.16 (B5), U204.10 (out2)
unnamed: U118.18 (B3), U203.6 (out4)
unnamed: U118.19 (B2), U203.3 (out3)
unnamed: U118.20 (B1), U203.10 (out2)
unnamed: U119.18 (B3), U205.6 (out4)
unnamed: U119.19 (B2), U205.3 (out3)
unnamed: U119.20 (B1), U205.10 (out2)
unnamed: U119.21 (B0), U205.13 (out1)
RDIN: U116.8 (A5); also elsewhere on the board
RDMGI: U118.6 (A3); also elsewhere on the board
RDMR: U118.4 (A1); also elsewhere on the board
RDOUT: U116.5 (A2); also elsewhere on the board
RHALT: U118.8 (A5); also elsewhere on the board
RIAKI: U116.10 (A7); also elsewhere on the board
RINIT: U118.10 (A7); also elsewhere on the board
RIRQ4: U116.9 (A6); also elsewhere on the board
RIRQ5: U116.3 (A0); also elsewhere on the board
RIRQ6: U116.4 (A1); also elsewhere on the board
RREF: U118.5 (A2); also elsewhere on the board
RRPLY: U116.6 (A3); also elsewhere on the board
RSYNC: U116.7 (A4); also elsewhere on the board
TDIN: U115.16 (B5); also elsewhere on the board
TDMGO: U117.16 (B5); also elsewhere on the board
TDMR: U117.20 (B1); also elsewhere on the board
TDOUT: U115.19 (B2); also elsewhere on the board
TIAKO: U117.21 (B0); also elsewhere on the board
TIRQ4: U115.15 (B6); also elsewhere on the board
TIRQ5: U115.21 (B0); also elsewhere on the board
TIRQ6: U115.20 (B1); also elsewhere on the board
TIRQ7: U115.14 (B7); also elsewhere on the board
TREF: U117.19 (B2); also elsewhere on the board
TRPLY: U115.18 (B3); also elsewhere on the board
TSACK: U117.17 (B4); also elsewhere on the board
TSYNC: U115.17 (B4); also elsewhere on the board

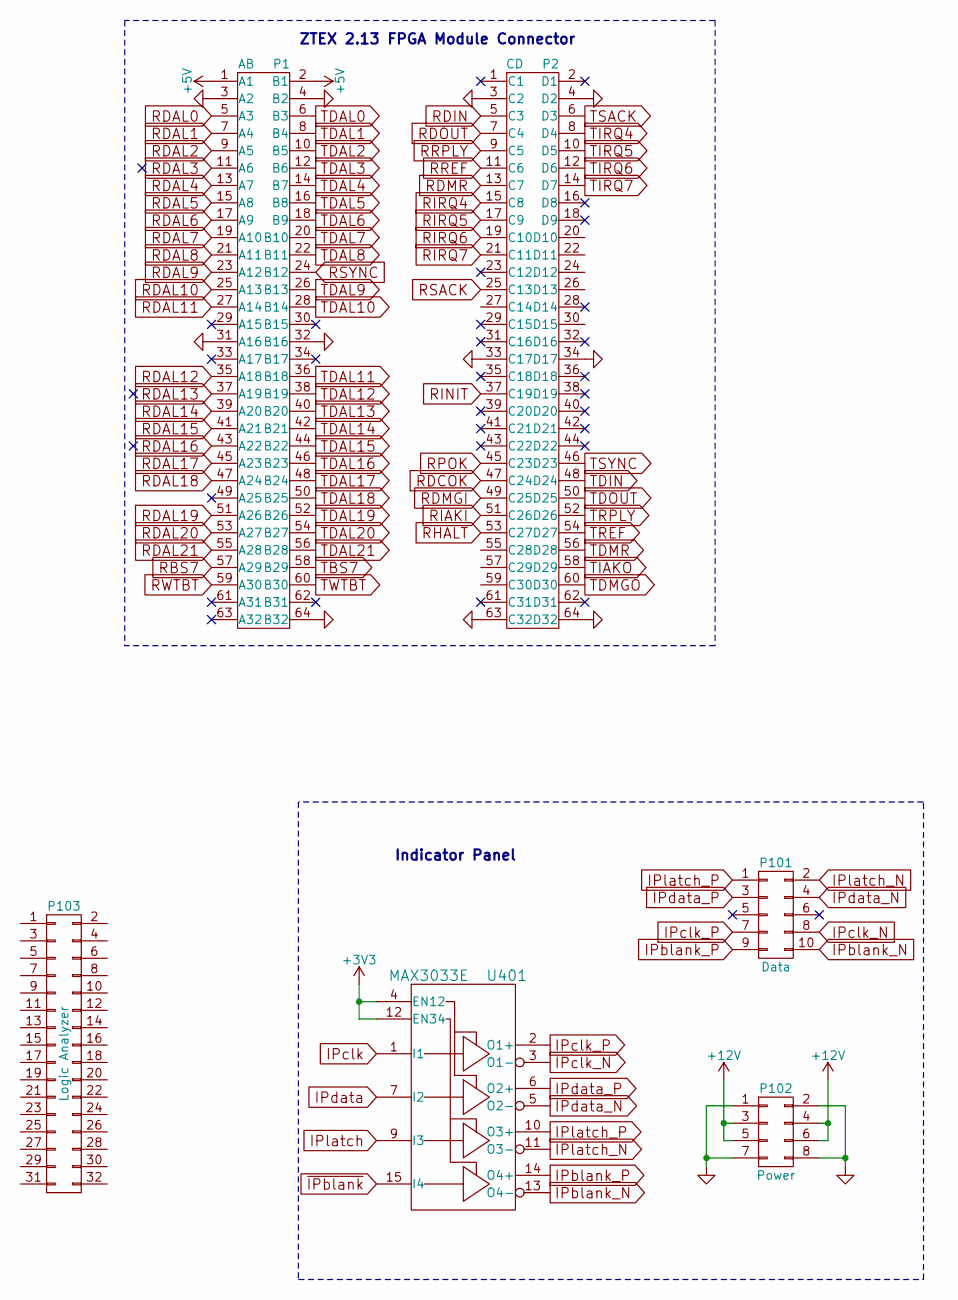
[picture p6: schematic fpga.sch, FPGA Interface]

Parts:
P1: AB; Pin_Header_Straight_2x32
P2: CD; Pin_Header_Straight_2x32
P101: Data; Pin_Header_Angled_2x05
P102: Power; Pin_Header_Angled_2x04
P103: Logic Analyzer; Pin_Header_Straight_2x16
U401: MAX3033E; SOIC-16_3.9x9.9mm_Pitch1.27mm

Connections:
+5V: P1.1 (A1), P1.2 (B1); also elsewhere on the board
+12V: P102.3, P102.4, P102.5, P102.6; also elsewhere on the board
IPblank_N: P101.10, U401.13 (O4-)
IPblank_P: P101.9, U401.14 (O4+)
IPclk: U401.1 (I1)
IPclk_N: P101.8, U401.3 (O1-)
IPclk_P: P101.7, U401.2 (O1+)
IPdata: U401.7 (I2)
IPdata_N: P101.4, U401.5 (O2-)
IPdata_P: P101.3, U401.6 (O2+)
IPlatch: U401.9 (I3)
IPlatch_N: P101.2, U401.11 (O3-)
IPlatch_P: P101.1, U401.10 (O3+)
RBS7: P1.57 (A29); also elsewhere on the board
RDAL0: P1.5 (A3); also elsewhere on the board
RDAL1: P1.7 (A4); also elsewhere on the board
RDAL2: P1.9 (A5); also elsewhere on the board
RDAL3: P1.11 (A6); also elsewhere on the board
RDAL4: P1.13 (A7); also elsewhere on the board
RDAL5: P1.15 (A8); also elsewhere on the board
RDAL6: P1.17 (A9); also elsewhere on the board
RDAL7: P1.19 (A10); also elsewhere on the board
RDAL8: P1.21 (A11); also elsewhere on the board
RDAL9: P1.23 (A12); also elsewhere on the board
RDAL10: P1.25 (A13); also elsewhere on the board
RDAL11: P1.27 (A14); also elsewhere on the board
RDAL12: P1.35 (A18); also elsewhere on the board
RDAL13: P1.37 (A19); also elsewhere on the board
RDAL14: P1.39 (A20); also elsewhere on the board
RDAL15: P1.41 (A21); also elsewhere on the board
RDAL16: P1.43 (A22); also elsewhere on the board
RDAL17: P1.45 (A23); also elsewhere on the board
RDAL18: P1.47 (A24); also elsewhere on the board
RDAL19: P1.51 (A26); also elsewhere on the board
RDAL20: P1.53 (A27); also elsewhere on the board
RDAL21: P1.55 (A28); also elsewhere on the board
RDIN: P2.5 (C3); also elsewhere on the board
RDMGI: P2.49 (C25); also elsewhere on the board
RDMR: P2.13 (C7); also elsewhere on the board
RDOUT: P2.7 (C4); also elsewhere on the board
RHALT: P2.53 (C27); also elsewhere on the board
RIAKI: P2.51 (C26); also elsewhere on the board
RINIT: P2.37 (C19); also elsewhere on the board
RIRQ4: P2.15 (C8); also elsewhere on the board
RIRQ5: P2.17 (C9); also elsewhere on the board
RIRQ6: P2.19 (C10); also elsewhere on the board
RREF: P2.11 (C6); also elsewhere on the board
RRPLY: P2.9 (C5); also elsewhere on the board
RSYNC: P1.24 (B12); also elsewhere on the board
RWTBT: P1.59 (A30); also elsewhere on the board
TBS7: P1.58 (B29); also elsewhere on the board
TDAL0: P1.6 (B3); also elsewhere on the board
TDAL1: P1.8 (B4); also elsewhere on the board
TDAL2: P1.10 (B5); also elsewhere on the board
TDAL3: P1.12 (B6); also elsewhere on the board
TDAL4: P1.14 (B7); also elsewhere on the board
TDAL5: P1.16 (B8); also elsewhere on the board
TDAL6: P1.18 (B9); also elsewhere on the board
TDAL7: P1.20 (B10); also elsewhere on the board
TDAL8: P1.22 (B11); also elsewhere on the board
TDAL9: P1.26 (B13); also elsewhere on the board
TDAL10: P1.28 (B14); also elsewhere on the board
TDAL11: P1.36 (B18); also elsewhere on the board
TDAL12: P1.38 (B19); also elsewhere on the board
TDAL13: P1.40 (B20); also elsewhere on the board
TDAL14: P1.42 (B21); also elsewhere on the board
TDAL15: P1.44 (B22); also elsewhere on the board
TDAL16: P1.46 (B23); also elsewhere on the board
TDAL17: P1.48 (B24); also elsewhere on the board
TDAL18: P1.50 (B25); also elsewhere on the board
TDAL19: P1.52 (B26); also elsewhere on the board
TDAL20: P1.54 (B27); also elsewhere on the board
TDAL21: P1.56 (B28); also elsewhere on the board
TDIN: P2.48 (D24); also elsewhere on the board
TDMGO: P2.60 (D30); also elsewhere on the board
TDMR: P2.56 (D28); also elsewhere on the board
TDOUT: P2.50 (D25); also elsewhere on the board
TIAKO: P2.58 (D29); also elsewhere on the board
TIRQ4: P2.8 (D4); also elsewhere on the board
TIRQ5: P2.10 (D5); also elsewhere on the board
TIRQ6: P2.12 (D6); also elsewhere on the board
TIRQ7: P2.14 (D7); also elsewhere on the board
TREF: P2.54 (D27); also elsewhere on the board
TRPLY: P2.52 (D26); also elsewhere on the board
TSACK: P2.6 (D3); also elsewhere on the board
TSYNC: P2.46 (D23); also elsewhere on the board
TWTBT: P1.60 (B30); also elsewhere on the board
~IPblank: U401.15 (I4)

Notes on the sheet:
ZTEX 2.13 FPGA Module Connector
Indicator Panel

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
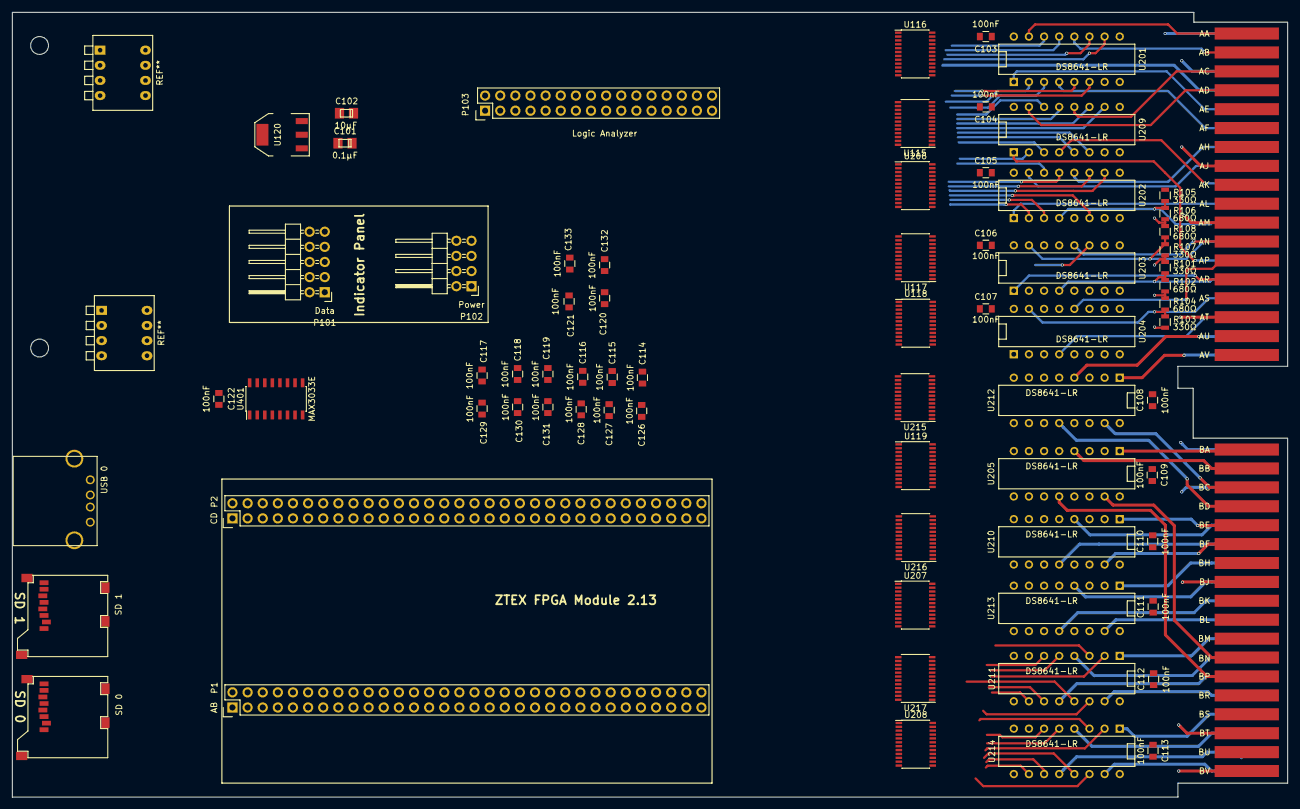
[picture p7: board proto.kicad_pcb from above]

Board: 4 copper layers, 214.1 x 131.7 mm, 73 parts (0 on the bottom side), 211 nets.

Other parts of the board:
SD 0, SD 1: microSD 3M; microSD-3M-2900-series
USB 0: USB_A
h1, h2: MountingHole_3mm

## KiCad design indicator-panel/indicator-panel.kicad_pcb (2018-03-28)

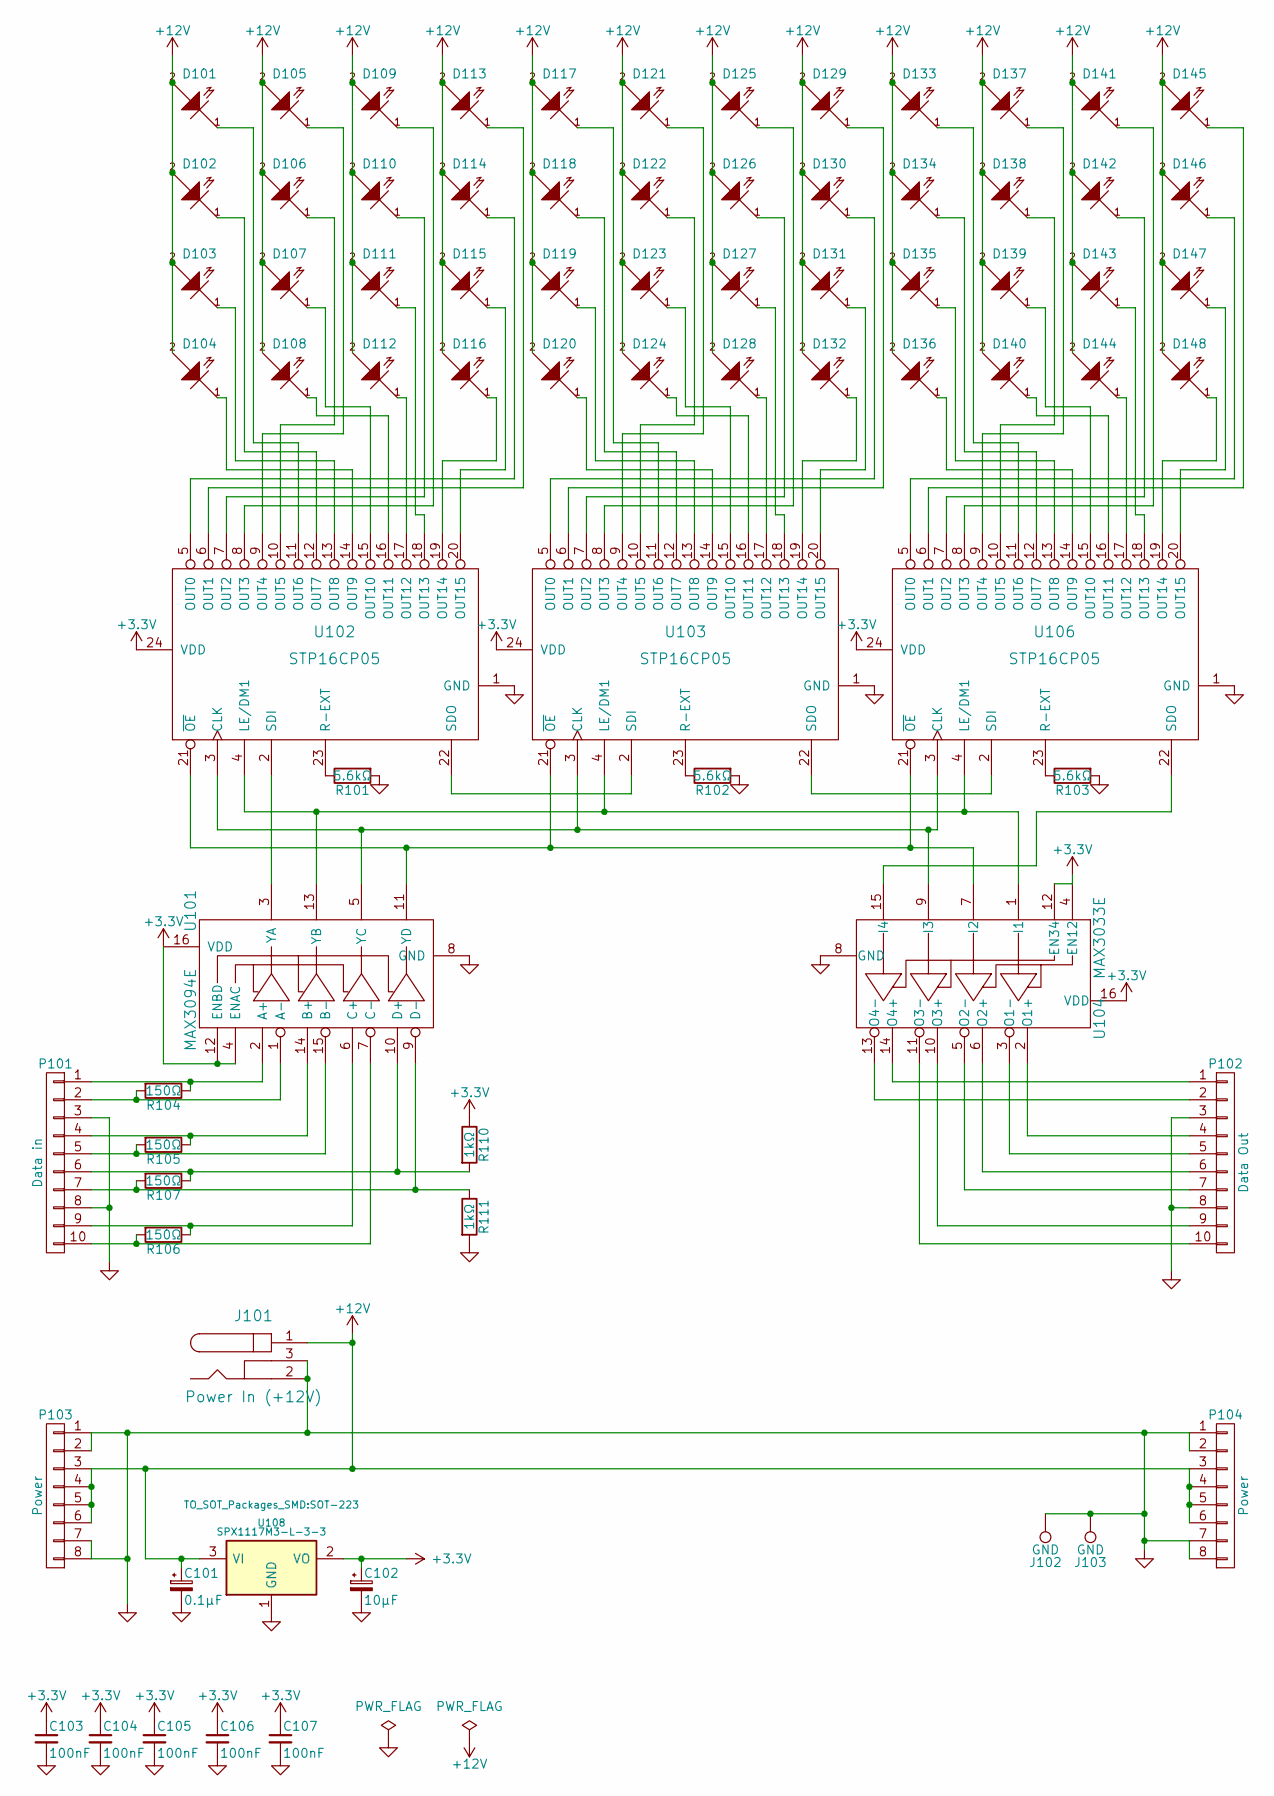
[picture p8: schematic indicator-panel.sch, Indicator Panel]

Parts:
C101: 0.1μF; CP_Tantalum_Case-R_EIA-2012-12_Reflow
C102: 10μF; CP_Tantalum_Case-R_EIA-2012-12_Wave
C103, C104, C105, C106, C107: 100nF; C_0805
D101, D102, D103, D104, D105, D106, D107, D108, D109, D110, D111, D112, D113, D114, D115, D116, D117, D118, D119, D120, D121, D122, D123, D124, D125, D126, D127, D128, D129, D130, D131, D132, D133, D134, D135, D136, D137, D138, D139, D140, D141, D142, D143, D144, D145, D146, D147, D148: LED-45; LED-0805
J101: Power In (+12V); PJ-032B
J102, J103: GND; MountingHole_3-5mm
P101: Data in; Pin_Header_Angled_2x05
P102: Data Out; Socket_Strip_Angled_2x05
P103: Power; Pin_Header_Angled_2x04
P104: Power; Socket_Strip_Angled_2x04
R101, R102, R103: 5.6kΩ; R_0805
R104, R105, R106, R107: 150Ω; R_0805
R110, R111: 1kΩ; R_0805
U101: MAX3094E; SOIC-16_3.9x9.9mm_Pitch1.27mm
U102, U103, U106: STP16CP05; SOIC-24_7.5x15.4mm_Pitch1.27mm
U104: MAX3033E; SOIC-16_3.9x9.9mm_Pitch1.27mm
U108: SPX1117M3-L-3-3; SOT-223

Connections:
+3V3: C102.1, C103.1, C104.1, C105.1, C106.1, C107.1, R110.1, U101.4 (ENAC), U101.12 (ENBD), U101.16 (VDD), U102.24 (VDD), U103.24 (VDD), U104.4 (EN12), U104.12 (EN34), U104.16 (VDD), U106.24 (VDD), U108.2 (VO)
+12V: C101.1, D101.2 (A), D102.2 (A), D103.2 (A), D104.2 (A), D105.2 (A), D106.2 (A), D107.2 (A), D108.2 (A), D109.2 (A), D110.2 (A), D111.2 (A), D112.2 (A), D113.2 (A), D114.2 (A), D115.2 (A), D116.2 (A), D117.2 (A), D118.2 (A), D119.2 (A), D120.2 (A), D121.2 (A), D122.2 (A), D123.2 (A), D124.2 (A), D125.2 (A), D126.2 (A), D127.2 (A), D128.2 (A), D129.2 (A), D130.2 (A), D131.2 (A), D132.2 (A), D133.2 (A), D134.2 (A), D135.2 (A), D136.2 (A), D137.2 (A), D138.2 (A), D139.2 (A), D140.2 (A), D141.2 (A), D142.2 (A), D143.2 (A), D144.2 (A), D145.2 (A), D146.2 (A), D147.2 (A), D148.2 (A), J101.1, P103.3, P103.4, P103.5, P103.6, P104.3, P104.4, P104.5, P104.6, U108.3 (VI)
GND: C101.2, C102.2, C103.2, C104.2, C105.2, C106.2, C107.2, J101.2, J101.3, J102.1, J103.1, P101.3, P101.8, P102.3, P102.8, P103.1, P103.2, P103.7, P103.8, P104.1, P104.2, P104.7, P104.8, R101.2, R102.2, R103.2, R111.2, U101.8 (GND), U102.1 (GND), U103.1 (GND), U104.8 (GND), U106.1 (GND), U108.1 (GND)
unnamed: D101.1 (K), U102.11 (OUT6)
unnamed: D102.1 (K), U102.12 (OUT7)
unnamed: D103.1 (K), U102.13 (OUT8)
unnamed: D104.1 (K), U102.14 (OUT9)
unnamed: D105.1 (K), U102.9 (OUT4)
unnamed: D106.1 (K), U102.10 (OUT5)
unnamed: D107.1 (K), U102.15 (OUT10)
unnamed: D108.1 (K), U102.16 (OUT11)
unnamed: D109.1 (K), U102.8 (OUT3)
unnamed: D110.1 (K), U102.7 (OUT2)
unnamed: D111.1 (K), U102.18 (OUT13)
unnamed: D112.1 (K), U102.17 (OUT12)
unnamed: D113.1 (K), U102.6 (OUT1)
unnamed: D114.1 (K), U102.5 (OUT0)
unnamed: D115.1 (K), U102.20 (OUT15)
unnamed: D116.1 (K), U102.19 (OUT14)
unnamed: D117.1 (K), U103.11 (OUT6)
unnamed: D118.1 (K), U103.12 (OUT7)
unnamed: D119.1 (K), U103.13 (OUT8)
unnamed: D120.1 (K), U103.14 (OUT9)
unnamed: D121.1 (K), U103.9 (OUT4)
unnamed: D122.1 (K), U103.10 (OUT5)
unnamed: D123.1 (K), U103.15 (OUT10)
unnamed: D124.1 (K), U103.16 (OUT11)
unnamed: D125.1 (K), U103.8 (OUT3)
unnamed: D126.1 (K), U103.7 (OUT2)
unnamed: D127.1 (K), U103.18 (OUT13)
unnamed: D128.1 (K), U103.17 (OUT12)
unnamed: D129.1 (K), U103.6 (OUT1)
unnamed: D130.1 (K), U103.5 (OUT0)
unnamed: D131.1 (K), U103.20 (OUT15)
unnamed: D132.1 (K), U103.19 (OUT14)
unnamed: D133.1 (K), U106.11 (OUT6)
unnamed: D134.1 (K), U106.12 (OUT7)
unnamed: D135.1 (K), U106.13 (OUT8)
unnamed: D136.1 (K), U106.14 (OUT9)
unnamed: D137.1 (K), U106.9 (OUT4)
unnamed: D138.1 (K), U106.10 (OUT5)
unnamed: D139.1 (K), U106.15 (OUT10)
unnamed: D140.1 (K), U106.16 (OUT11)
unnamed: D141.1 (K), U106.8 (OUT3)
unnamed: D142.1 (K), U106.7 (OUT2)
unnamed: D143.1 (K), U106.18 (OUT13)
unnamed: D144.1 (K), U106.17 (OUT12)
unnamed: D145.1 (K), U106.6 (OUT1)
unnamed: D146.1 (K), U106.5 (OUT0)
unnamed: D147.1 (K), U106.20 (OUT15)
unnamed: D148.1 (K), U106.19 (OUT14)
unnamed: P101.1, R104.1, U101.2 (A+)
unnamed: P101.2, R104.2, U101.1 (A-)
unnamed: P101.4, R105.1, U101.14 (B+)
unnamed: P101.5, R105.2, U101.15 (B-)
unnamed: P101.6, R107.1, R110.2, U101.10 (D+)
unnamed: P101.7, R107.2, R111.1, U101.9 (D-)
unnamed: P101.9, R106.1, U101.6 (C+)
unnamed: P101.10, R106.2, U101.7 (C-)
unnamed: P102.1, U104.14 (O4+)
unnamed: P102.2, U104.13 (O4-)
unnamed: P102.4, U104.2 (O1+)
unnamed: P102.5, U104.3 (O1-)
unnamed: P102.6, U104.6 (O2+)
unnamed: P102.7, U104.5 (O2-)
unnamed: P102.9, U104.10 (O3+)
unnamed: P102.10, U104.11 (O3-)
unnamed: R101.1, U102.23 (R-EXT)
unnamed: R102.1, U103.23 (R-EXT)
unnamed: R103.1, U106.23 (R-EXT)
unnamed: U101.3 (YA), U102.2 (SDI)
unnamed: U101.5 (YC), U102.3 (CLK), U103.3 (CLK), U104.9 (I3), U106.3 (CLK)
unnamed: U101.11 (YD), U102.21 (~OE), U103.21 (~OE), U104.7 (I2), U106.21 (~OE)
unnamed: U101.13 (YB), U102.4 (LE/DM1), U103.4 (LE/DM1), U104.1 (I1), U106.4 (LE/DM1)
unnamed: U102.22 (SDO), U103.2 (SDI)
unnamed: U103.22 (SDO), U106.2 (SDI)
unnamed: U104.15 (I4), U106.22 (SDO)

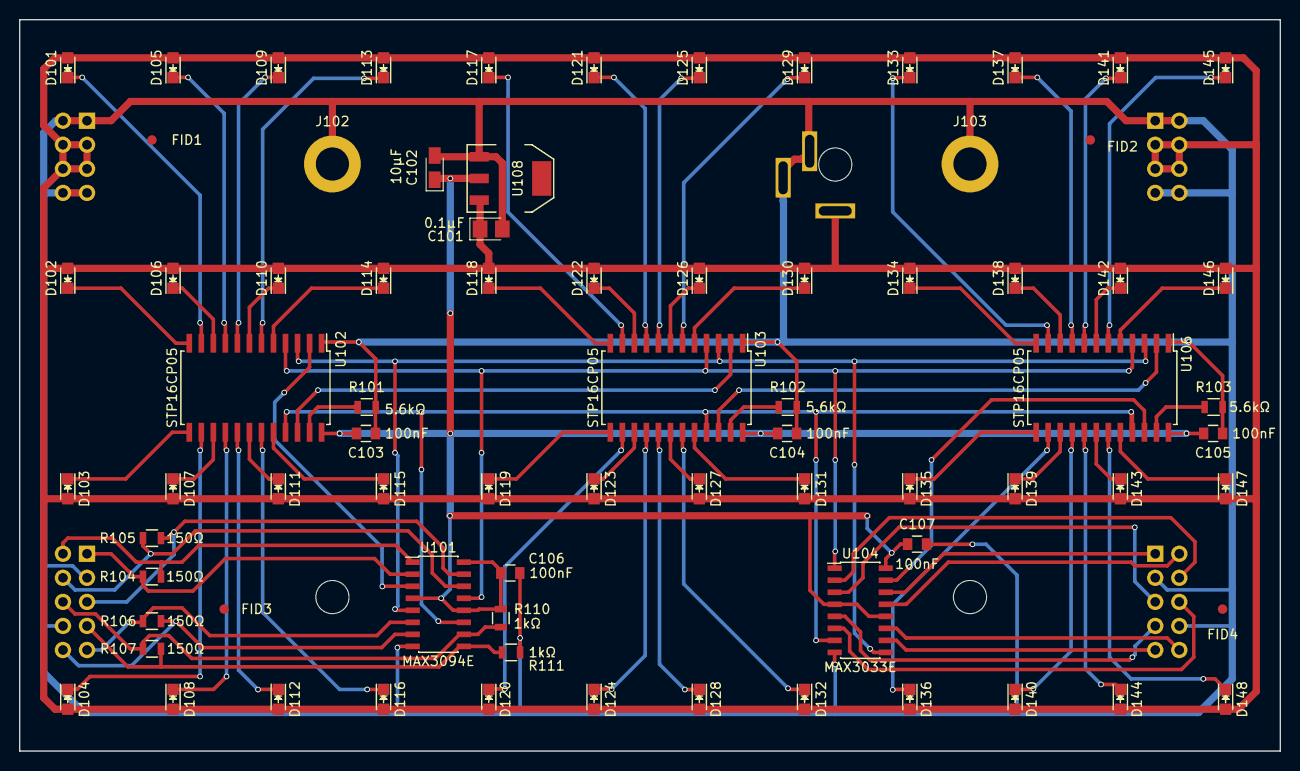
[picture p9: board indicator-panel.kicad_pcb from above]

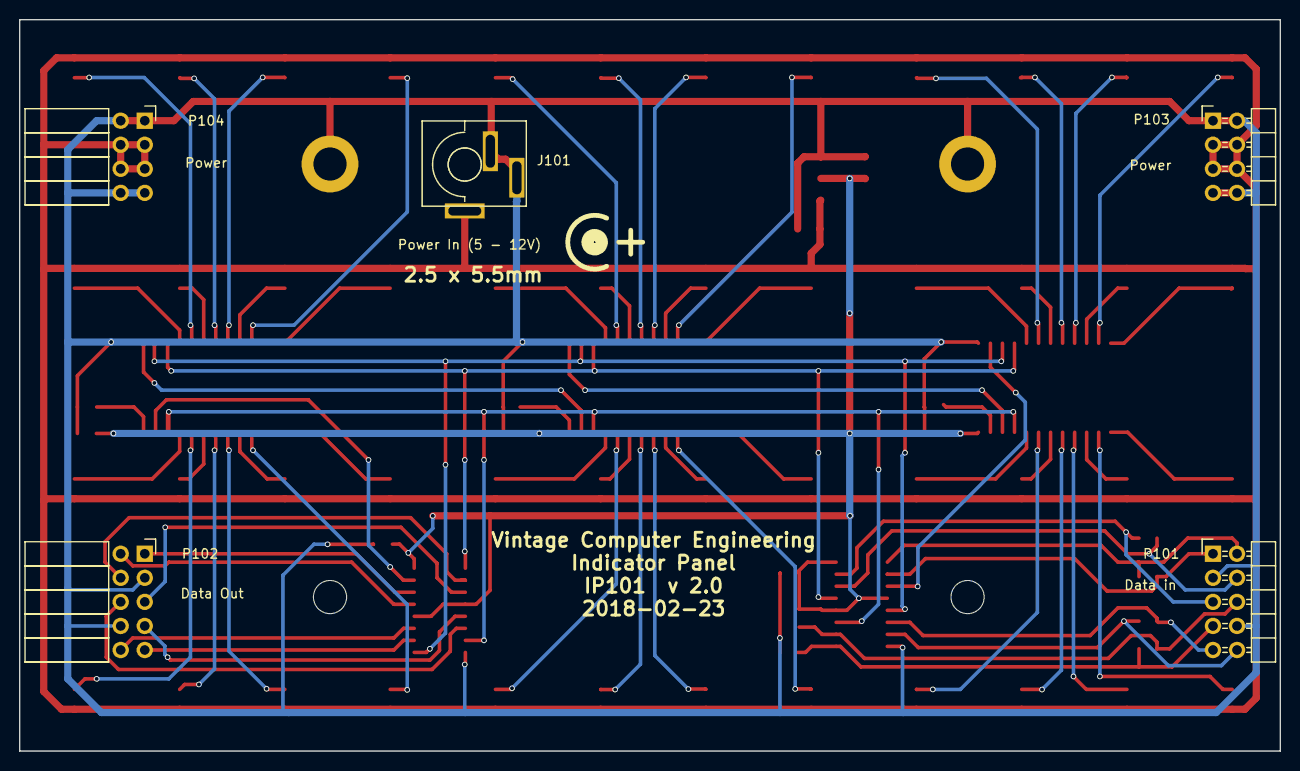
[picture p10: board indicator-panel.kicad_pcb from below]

Board: 2 copper layers, 133.1 x 77.2 mm, 81 parts (5 on the bottom side), 77 nets.

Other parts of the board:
FID1, FID2, FID3, FID4: Fiducial; Fiducial_1mm_Dia_2.54mm_Outer_CopperTop

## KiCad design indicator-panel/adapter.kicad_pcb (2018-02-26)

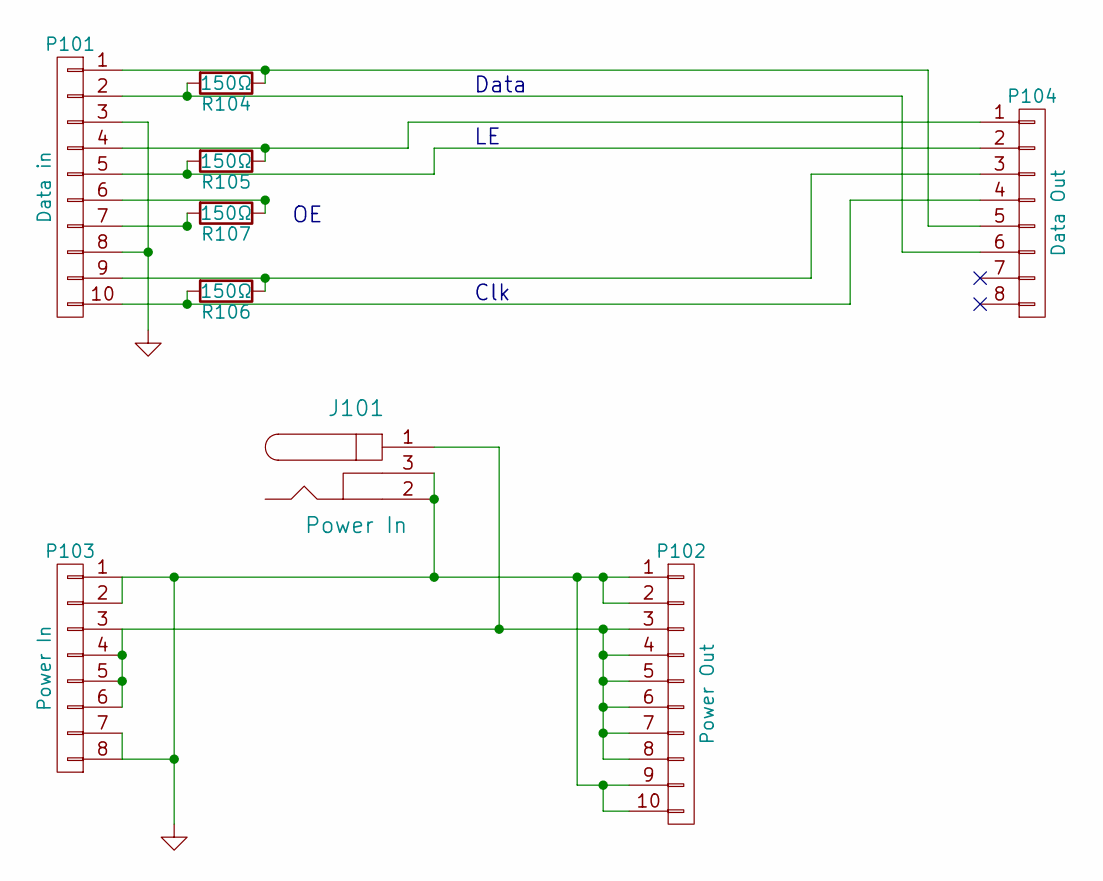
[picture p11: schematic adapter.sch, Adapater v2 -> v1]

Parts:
J101: Power In; PJ-032B
P101: Data in; Pin_Header_Straight_2x05
P102: Power Out; Socket_Strip_Straight_2x05
P103: Power In; Pin_Header_Straight_2x04
P104: Data Out; Socket_Strip_Straight_2x04
R104, R105, R106, R107: 150Ω; R_0805

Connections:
GND: J101.2, J101.3, P101.3, P101.8, P102.1, P102.2, P102.9, P102.10, P103.1, P103.2, P103.7, P103.8
unnamed: J101.1, P102.3, P102.4, P102.5, P102.6, P102.7, P102.8, P103.3, P103.4, P103.5, P103.6
unnamed: P101.1, P104.5, R104.1
unnamed: P101.2, P104.6, R104.2
unnamed: P101.4, P104.1, R105.1
unnamed: P101.5, P104.2, R105.2
unnamed: P101.6, R107.1
unnamed: P101.7, R107.2
unnamed: P101.9, P104.3, R106.1
unnamed: P101.10, P104.4, R106.2

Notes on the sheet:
Data
Clk

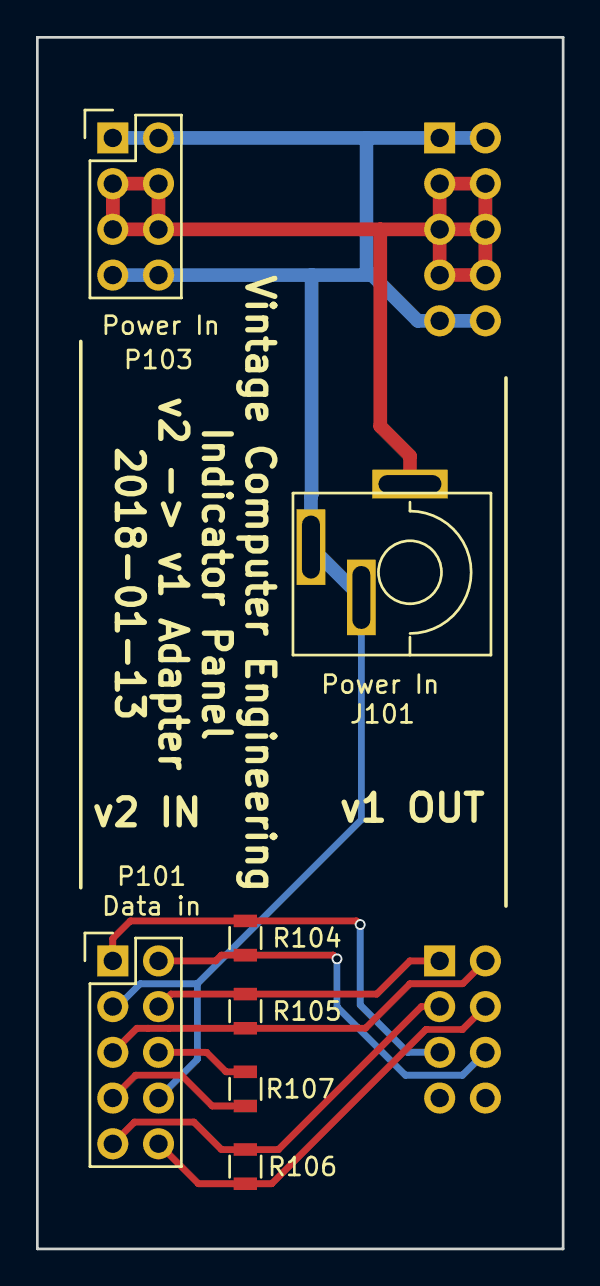
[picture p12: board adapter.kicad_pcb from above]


Board: 2 copper layers, 29.2 x 67.3 mm, 9 parts (2 on the bottom side), 10 nets.

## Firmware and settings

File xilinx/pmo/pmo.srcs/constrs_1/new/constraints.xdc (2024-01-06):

set_property IOSTANDARD LVCMOS33 [get_ports clk48_in]
set_property IOSTANDARD LVCMOS33 [get_ports led_a6]
set_property PACKAGE_PIN P15 [get_ports clk48_in]
set_property PACKAGE_PIN H15 [get_ports led_a6]


set_property CONFIG_VOLTAGE 3.3 [current_design]
set_property CFGBVS VCCO [current_design]


set_property PACKAGE_PIN J14 [get_ports led_a7]
set_property IOSTANDARD LVCMOS33 [get_ports led_a7]
set_property PACKAGE_PIN J13 [get_ports led_b6]
set_property IOSTANDARD LVCMOS33 [get_ports led_b6]

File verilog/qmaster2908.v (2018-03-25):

//	-*- mode: Verilog; fill-column: 96 -*-
//
// QBus Master logic for when there are Am2908s between us and the QBUS - This is the logic that
// handles bus acquisition, managing the data transfers, and handing the bus back.  The actual
// data paths are elsewhere.
//
// Copyright 2016-2018 Noel Chiappa and David Bridgham

`timescale 1 ns / 1 ns

module qmaster2908
  (
   input      clk, // 20MHz clock to get right timing for QBUS

   // QBUS
   input      RSYNC,
   input      RRPLY,
   input      RDMR,
   input      RSACK,
   input      RINIT,
   input      RDMGI,
   input      sRDMGI, // a synchronized (and delayed) RDMGI
   input      RREF, 
   output reg TSYNC,
   output reg TWTBT, 
   output reg TDIN,
   output reg TDOUT,
   output     TDMR,
   output reg TSACK, 
   output     TDMGO,

   // internal controls
   input      dma_read,
   input      dma_write,
   output reg assert_addr,
   output reg assert_data,
   output     read_pulse, // a one clock pulse if a device needs to clock out data
   output reg bus_master,
   output reg dma_complete, // only asserted for one clock cycle each dma cycle
   output reg DALst,
   output reg DALbe,
   output reg nxm
   );

   //
   // handle the bus arbitration.  this looks much like the interrupt ack processing.  perhaps
   // the biggest difference is that the interrupt processing latches the interrupt request
   // while here we expect the device to keep requesting dma so long as it has more data to
   // transfer.
   //

   assign TDMR = dma_read | dma_write;
   assign read_pulse = assert_data_set;
   

   // each time RDMGI gets asserted, latch if we're requesting the bus
   reg 	      won_arbitration = 0;
   reg 	      clear_win = 0;
   always @(posedge RDMGI, posedge RINIT, posedge clear_win) begin
      if (RINIT || clear_win)
	won_arbitration <= 0;
      else
	won_arbitration <= TDMR;
   end
   
   // pass on the bus grant if we don't take it.  the magic here is that we chain out the
   // delayed version of RDMGI.  that delay gives time for the won_arbitration signal to settle
   // and hopefully any meta-stable state to stabilize.  if we have multiple devices, they can
   // all look at the same RDGMI and then the chain starts from the synchronizer and each device
   // only adds the single AND gate.
   assign TDMGO = sRDMGI & ~won_arbitration;


   //
   // The state machine handles the sequencing for the master side of executing slave cycles
   //

   // states of bus master (one-hot)
`ifdef SIM
   integer state_index;
   integer state_index_next;
`endif
   reg [0:12] state;
   reg [0:12] state_next;
   localparam
     IDLE = 0,			// idle
     ADDR_SETUP = 1,		// acquired the bus, send address
     ADDR_HOLD = 2,		// hold the address, then start read or write

     WRITE_START = 3,		// start the data moving to the Am2908s
     WRITE_SETUP = 4,		// put the data on the bus
     WRITE = 5,			// begin write cycle
     WRITE_WAIT = 6,		// wait for reply
     WRITE_HOLD = 7,		// hold the write data
     WRITE_FINISH = 8,		// finish up the write cycle and release the bus
     
     READ = 9,			// start a read cycle
     READ_WAIT = 10,		// wait for reply
     READ_FINISH = 11,		// hold time on read data
     READ_RPLY_CLEAR = 12;	// wait for reply to clear, then release the bus
   
   task set_state;
      input integer s;
      begin
`ifdef SIM
	 state_index_next = s;
`endif
	 state_next[s] = 1'b1;
      end
   endtask
   
   
   // a counter used for doing timeouts.  the longest timeout is 10us for NXM which is a count
   // of 200 at 20MHz.  all the timeouts set below may look like one less than the comment
   // suggests but it takes one clock cycle to get to the next state.
   reg [7:0] 	timeout_count;
   reg [7:0] 	timeout_next;
   wire 	timeout = (timeout_count == 0);

   // synchronize various asynchronous signals
   reg [0:1] 	RSYNCsr, RRPLYsr;
   always @(posedge clk) begin
      if (RINIT) begin
	 RSYNCsr <= 0;
	 RRPLYsr <= 0; 
      end else begin
	 RSYNCsr <= { RSYNCsr[1], RSYNC };
	 RRPLYsr <= { RRPLYsr[1], RRPLY };
      end
   end
   wire sRSYNC = RSYNCsr[0],
	sRRPLY = RRPLYsr[0];
   
   // combinational part of the state machine
   reg TSACK_set, TSACK_clear, TSYNC_set, TSYNC_clear, TWTBT_set, TWTBT_clear;
   reg TDIN_set, TDIN_clear, TDOUT_set, TDOUT_clear;
   reg DALbe_set, DALbe_clear, DALst_set, DALst_clear;
   reg assert_addr_set, assert_addr_clear, assert_data_set, assert_data_clear;
   reg bus_master_set, bus_master_clear;

   always @(*) begin
      state_next = 0;		// every path through had better set exactly one state bit
      timeout_next = timeout_count - 1; // most of the time we just decrement the timeout counter
      dma_complete = 0;
      nxm = 0;
      clear_win = 0;
      
      // control lines to set or clear signals I mustn't glitch
      TSACK_set = 0;
      TSACK_clear = 0;
      TSYNC_set = 0;
      TSYNC_clear = 0;
      TWTBT_set = 0;
      TWTBT_clear = 0;
      TDIN_set = 0;
      TDIN_clear = 0;
      TDOUT_set = 0;
      TDOUT_clear = 0;
      DALbe_set = 0;
      DALbe_clear = 0;
      DALst_set = 0;
      DALst_clear = 0;
      assert_addr_set = 0;
      assert_addr_clear = 0;
      assert_data_set = 0;
      assert_data_clear = 0;
      bus_master_set = 0;
      bus_master_clear = 0;

      if (RINIT) begin
	 set_state(IDLE);
      end else
	case (1'b1)
	  state[IDLE]:
	    begin
	       if (sRDMGI && won_arbitration && !sRSYNC && !sRRPLY) begin
		  TSACK_set = 1;	// acknowledge we have the bus
		  bus_master_set = 1; // let the device know we're bus master
		  assert_addr_set = 1; // send the addressing info towards the Am2908s
		  TWTBT_set = dma_write; // if it's going to be a write cycle
		  timeout_next = 2;  // !!! give 2 extra cycles of delay to let the signals on
				     // the ribbon cable settle
		  set_state(ADDR_SETUP);
	       end else
		 set_state(IDLE);
	    end
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

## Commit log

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2015-10-05 A good start on the DMA mastering logic.
    Started the board layout for discrete bus drivers.
    [drivers.sch, qsic.kicad_pcb, qsic.sch]
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2015-10-11 Initial checkin of the lights board.
    [lights-board.kicad_pcb, lights-board.sch]
2015-10-12 Renamed lights to indicator-panel.
    [indicator-panel.kicad_pcb, indicator-panel.sch]
2015-10-12 Added the simple mechanical drawing for the indicator panel.
    [lights-board.kicad_pcb, lights-board.sch, mechanical.scad]
2015-10-13 Swapped out Am2908s for DS8641s and split the DAL signals to separate T and R.
    [proto.sch]
2015-10-14 Fix up connectors to carry current.
    [indicator-panel.kicad_pcb, indicator-panel.sch]
2015-10-15 Back to a bidirectional DAL bus.
    [proto.sch]
2015-10-15 Full circle, back to using Am2908s and a bidirectional DAL bus. Fixed a few other things along the way, like sorting out the direction and strobe lines and adding level shifting for them.
    [proto.sch]
2015-10-21 Separate some of the control signals for the BDAL lines.
    [proto.sch]
2015-10-27 Cleaned up schematic and added RK inlay.
    [indicator-panel.kicad_pcb, indicator-panel.sch]
2015-11-09 Added connections to ZTEX FPGA module.
    [proto.sch]
2015-11-11 Updated pcb and rk11 inlay to .44x.88 spacing.
    [indicator-panel.kicad_pcb, indicator-panel.sch]
2015-12-21 Changed data connector use so it can be reversed with no harm. Updated version to 1.1.
    [indicator-panel.kicad_pcb, indicator-panel.sch]
2016-01-10 Fixed bug with gnd on C1. Should be C2 and moved RSYNC down to C14.
    [proto.sch]
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2016-01-24 Moved RSYNC from C14 to B12 so it can be used as a clock.
    [proto.sch]
2016-02-11 Split out the wirewrap board from a prototype PC board. Fixed the RS422 drivers to get 3.3V intead of 5V.
    [proto.kicad_pcb, proto.sch]
2016-02-11 Wirewrap board is now split off, this is the PC prototype.
    [proto.kicad_pcb, proto.sch]
2016-02-14 Split schematic into multiple sheets.
    [control.sch, dal.sch, fpga.sch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]
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2016-02-20 Added barrel connector and shrunk schematic to Letter size. Last update before changing to add Blank and Board Detect signals.
    [indicator-panel.kicad_pcb, indicator-panel.sch]
2016-02-23 Changed to version 2.0 with the blanking signal and using a 4-unit rs485 receiver and transmitter.
    [indicator-panel.kicad_pcb, indicator-panel.sch]
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2016-03-14 RK11 is working with Noel's exerciser. Latest fix was to a bug in calculating the next sector address.
    [qmaster2908.v]
2016-03-20 Fixed the RK code to handle a word-count of 0 to mean 65,536. Our test program doesn't test this case yet but the code before was almost certainly wrong.
2016-04-02 This matches the old indicator panels, the first batch before I changed them all around.
    [proto.sch]
2017-01-15 Added SD card. Not yet wired to FPGA.
    [proto.sch]
2017-01-16 Attached SD card to FPGA.
    [proto.sch]
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2017-01-29 Updated current limiting resistor to 3.3k
    [indicator-panel.kicad_pcb, indicator-panel.sch, mechanical.scad]
2017-01-29 Added the LEDs I'm using on the debug board so I keep clear of those FPGA pins
    [proto.sch]
2017-01-29 Changed to comparator for bus receivers and rearranged schematic to multiple pages
    [BusControl.sch, drivers.sch, qsic.kicad_pcb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]
2017-01-29 Changed over to only DS8641 bus transceivers and the smaller package level-converters.
    [control.sch, dal.sch, fpga.sch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]
2017-03-16 Added the FPGA and rearranged the sheets.
    [BusControl.sch, bus-control.sch, bus-dal.sch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]
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2017-03-30 Moved two SD card signals (CS/CD and SD_DO) to ribbon cable wires that are less noisy.
    [proto.sch]
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2017-04-20 Added some voltage regulators.
    [bus-control.sch, bus-dal.sch, io.sch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]
2017-04-20 Worked on the board layout for the bus receivers.
    [bus-control.sch, bus-dal.sch, qsic.kicad_pcb]
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2017-04-27 Added the schematics to git.
    [grant1.sch, grant2.sch, grant3.sch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]
2017-11-06 Moved comparator power connections to separate symbols.
    [bus-control.sch, bus-dal.sch, io.sch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]
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2017-11-12 Cleaned up wire lengths
    [grant2.sch, grant3.sch]
2017-11-23 Moved some wires around.
    [proto.sch]
2017-11-23 Fix for correct spacing
    [indicator-panel.kicad_pcb]
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2017-11-26 Moved mounting holes to give a better attach point in the light shield
    [indicator-panel.kicad_pcb]
2017-11-26 Make VDD and GND pins on chips visible.
    [indicator-panel.kicad_pcb, indicator-panel.sch]
2017-12-04 Relocated coaxial power connector and increased pad size on its footprint.
    [indicator-panel.kicad_pcb]
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2017-12-26 Added fiducials and ground pads
    [indicator-panel.kicad_pcb]
2017-12-26 A bunch of little things to help with debugging. Also dropped the full-speed to 10MHz to see if speed was causing some of the problems.
    [sd.v]
2017-12-26 Fixed problem where reads of a single block issued multiple read commands to the Storage Device. The FIFO_full signal doesn't work right so use the block_count to decide when to allow more DMA into t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
2018-01-14 Updated the pinout to the indicator panel data port to match what I actually built.
    [proto.sch]
2018-01-14 Changed current limiting resistor to 8.2k
    [indicator-panel.kicad_pcb, indicator-panel.sch]
2018-01-14 Little fixups
    [bus-control.sch, bus-dal.sch, io.sch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]
2018-01-18 Moved two of the SD card lines to, hopefully, quieter locations
    [proto.sch]
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2018-01-30 Switched over to the Xilinx FIFOs. Fixed up the indicator panel timing.
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2018-02-01 Added another clock cycle of delay in letting the data settle on its way over the ribbon cables to the 2908s. The RAM disk was faster and showed up occasional data errors.
    [qmaster2908.v]
2018-02-01 Touch up some dates.
    [indicator-panel.kicad_pcb, indicator-panel.sch]
2018-02-06 Annotated all the components so the netlist works right.
    [proto.sch]
2018-02-26 Finalized v2 signal layout and submitted first batch for production.
    [adapter.kicad_pcb, adapter.sch, indicator-panel.kicad_pcb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]
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2018-03-28 Changed the tantalum capacitor footprint to more clearly show the positive end. Added some text around the power connector on the back.
    [indicator-panel.kicad_pcb, indicator-panel.sch]
2018-04-05 Fix latch to only fire on the last panel.
    [ip_mux.v]
2018-04-26 Put the number of cylinders in the load table and fix up the RKV12 to generate the appropriate error if it runs off the end of the disk.
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2018-11-05 Updated to KiCad v5
    [bus-control.sch, bus-dal.sch, io.sch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]
2018-11-07 Updated to KiCad 5
    [control.sch, dal.sch, fpga.sch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]
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2018-11-26 Update to KiCad 5.0
    [indicator-panel.sch]
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2019-01-12 Small fixes as suggested by Verilator.
    [sd.v]
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2019-07-06 Bus drivers are routed and a start on the FPGA-memory signals.
    [bus-control.sch, bus-dal.sch, fpga.sch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]
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2019-10-01 Reworked board from template. Changed schematic to let me use the bus drivers and level converters more efficiently so to get all the signals.
    [blinken.sch, bus-control.sch, bus-dal.sch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]
2019-10-12 Design of prototype is done. Needs checking before sending out.
    [bus-rcvr.sch, bus-xcvr.sch, bus-xmtr.sch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]
2019-10-12 A few fixups from ERC. Ground CS# on the memory chip.
    [blinken.sch, bus-driver-pwr.sch, bus-rcvr.sch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]
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2019-10-12 Fixed up TDAL[0..21] and RDAL[0.21] buses now that I got it working.
    [qbus-interface.sch, qsic.kicad_pcb]
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2020-01-27 Fixed sys_rst on the SDRAM interface to be active low. Bumped the size of the RAM disk up to 203 cylinders to be a full-sized RK05 now that the SDRAM is working.
2020-01-27 Got the RAMDISK working. Had to add a full clock cycle delay when reading the write FIFO since the data seems to be lagging by one clock cycle. Doesn't make sense and will be redone when I change the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
2020-01-27 Add small resistor and large capacitor to SD card power.
    [qbus.sch]
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2020-01-31 Trying out a sheet for the transceiver circuit.
    [xcvr.sch]
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2024-01-06 These are all old changes in directories that are now historical.
    [bus-control.sch, bus-dal.sch, io.sch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]
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
